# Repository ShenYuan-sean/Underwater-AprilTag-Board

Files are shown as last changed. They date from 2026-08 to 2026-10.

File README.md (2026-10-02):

# Underwater AprilTag Board

本仓库包含两套使用 AprilTag 36h11 的水下标定与定位板工程：

- 当前根目录：6 块 `150 mm × 150 mm` 六面全向标定板，Tag ID 为 `0–53`。
- [`Reservoir-AprilTag-Boards-20/`](Reservoir-AprilTag-Boards-20/)：两批共 40 块 `300 mm × 300 mm` 水库定位板，Tag ID 为 `100–459`，包含四个 `5.2 mm` 安装孔、加工用 DXF/SVG、参考 PDF 和第一批加工厂确认图。

## 6-Face AprilTag 36h11 Calibration Board

这个项目用于生成 6 块 150 mm x 150 mm 标定板，每块板使用 AprilTag `36h11` 家族，所有 Tag ID 唯一。默认布局是每面 1 个中央大 Tag + 8 个外围小 Tag，适合做六边形水平全向标定板。

## 默认方案

- 每块板尺寸：150 mm x 150 mm
- 每面 Tag 数：9
- 中央大 Tag：64 mm 黑色码区，单元格约 8 mm
- 外围小 Tag：22 mm 黑色码区，单元格约 2.75 mm
- 每面 ID：
  - Face 1: 0-8
  - Face 2: 9-17
  - Face 3: 18-26
  - Face 4: 27-35
  - Face 5: 36-44
  - Face 6: 45-53

中央大 Tag 用来保证中远距离、斜视角和运动模糊下仍能稳定识别；外围小 Tag 用来在近距离、局部遮挡、多面同时入镜时增加可见角点数量。默认不在板面上放安装孔，建议用背面、边缘压条或插槽夹持，避免破坏 Tag 的白色 quiet zone。

## 文件

- `generate_apriltag_boards.py`: 生成 SVG/DXF 的 Python 脚本
- `environment.yml`: 可复现环境配置
- `generated/face_01.svg` 到 `generated/face_06.svg`: 单面干净 SVG
- `generated/face_01_guide.svg` 到 `generated/face_06_guide.svg`: 带 ID 和 quiet zone 辅助线的 SVG
- `generated/face_01.dxf` 到 `generated/face_06.dxf`: 单面干净 DXF，默认只含加工常用图层和板面文字
- `generated/face_01_guide.dxf` 到 `generated/face_06_guide.dxf`: 带 Tag 边界、quiet zone 和辅助 ID 的 DXF
- `generated/all_faces_sheet.svg`: 六面拼版 SVG
- `generated/all_faces_sheet.dxf`: 六面拼版 DXF
- `generated/all_faces_sheet_guide.dxf`: 六面拼版辅助 DXF
- `generated/hex_fixture_top_view.dxf`: 六边形夹具顶视参考 DXF
- `generated/manifest.txt`: 尺寸、ID 和 DXF 图层说明

## 生成命令

本机 Miniconda 没有加入 PATH，所以可以直接用完整路径调用项目内环境：

```powershell
C:\Users\ASUS\Documents\WS\4.Underwater_Robot\水下标定板\.conda\apriltag-board\python.exe generate_apriltag_boards.py
```

如果要从 `environment.yml` 重建环境：

```powershell
C:\Users\ASUS\miniconda3\Scripts\conda.exe env create -f environment.yml
```

或者创建到项目内：

```powershell
C:\Users\ASUS\miniconda3\Scripts\conda.exe env create --prefix .\.conda\apriltag-board -f environment.yml
```

## 可调参数

```powershell
.\.conda\apriltag-board\python.exe generate_apriltag_boards.py --center-tag-mm 64 --small-tag-mm 22 --start-id 0
```

如果你希望远距离识别更强，可以把外围小 Tag 减少，或把中央 Tag 改到 72-90 mm；如果主要是近距离标定，可以保留 9 Tag 布局。当前默认方案是两者之间的折中。

## ID 校验

用 OpenCV 重新检测每块板的 SVG，确认 AprilTag 36h11 的 ID 没有生成错：

```powershell
.\.conda\apriltag-board\python.exe verify_apriltag_boards.py
```

脚本会检查 `generated/face_01.svg` 到 `generated/face_06.svg`，并在 `generated/verification_debug/` 里输出带检测框的 PNG。

## DXF 图层

- `CUT`: 150 mm 板外框
- `MOUNT_HOLE`: 4 个安装孔，默认孔径 3.4 mm，孔心为 `(48,22)`, `(102,22)`, `(48,128)`, `(102,128)`
- `BLACK_POCKET`: 每个黑色单元格的轮廓线，适合 CNC/激光做填黑或雕刻区域
- `BOARD_TEXT`: 实际可印/可刻的板号、ID 范围和左右相邻面提示；普通 DXF 中这些文字已经转成线段字，不依赖 CAD 的 `TEXT` 实体
- `ORIENTATION`: 顶边方向箭头
- `BLACK_FILL_PREVIEW`: 可选黑块预览填充层，默认不输出
- `TAG_BOUNDARY`: Tag 黑色码区边界，只在 `*_guide.dxf`
- `QUIET_ZONE`: 推荐留白区域，只在 `*_guide.dxf`
- `LABEL`: 面编号和 ID 辅助标注，只在 `*_guide.dxf`

实际加工时，建议使用 `CUT`、`BLACK_POCKET`、`BOARD_TEXT` 和 `ORIENTATION`。默认 DXF 已改成 AutoCAD R12 ASCII，普通加工版只用 `LINE` 实体来画板框、黑块、箭头和板面提示文字，兼容性比上一版更好。

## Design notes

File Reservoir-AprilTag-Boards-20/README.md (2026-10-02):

# 水库 AprilTag 定位板（两批共 40 块）

本工程管理两批共 40 块独立的 `300 mm × 300 mm` 水库定位板。参考原六面标定板，每块板使用“一个中央大 Tag + 八个外围小 Tag”的 AprilTag 36h11 九宫格布局。共使用唯一 ID `100–459`，避免与 `Underwater-AprilTag-Board` 中已有的 `0–53` 冲突。

| 批次 | 板号 | Tag ID | 文件位置 |
|---|---|---|---|
| 第一批（已加工） | R01–R20 | 100–279 | `generated/`、`加工厂复核/` |
| 第二批（本次新增） | R21–R40 | 280–459 | `batch_02/generated/`、`batch_02/output/pdf/` |

## 推荐方案

| 项目 | 参数 |
|---|---:|
| 板材外形 | 300 mm × 300 mm |
| 每板 Tag 数量 | 9 |
| Tag 家族 | AprilTag 36h11 |
| ID | 100–459（两批合计） |
| 中央黑色码区 | 128 mm × 128 mm |
| 外围黑色码区 | 44 mm × 44 mm |
| 中央/小 Tag 单元格 | 16 mm / 5.5 mm |
| 中央/小 Tag quiet zone | 10 mm / 8 mm |
| 安装孔 | 4 × 直径 5.2 mm（M5 间隙孔） |
| 孔位 | 两列 `x=96/204 mm`，两行 `y=44/256 mm` |

以板左下角为工程坐标原点，四个孔心为：

- `(96, 44) mm`
- `(204, 44) mm`
- `(96, 256) mm`
- `(204, 256) mm`

中央 Tag 黑色码区位于 `x=86–214 mm, y=86–214 mm`，其 quiet zone 为 `x=76–224 mm, y=76–224 mm`。外围 Tag 位于中心坐标为 `44、150、256 mm` 的九宫格位置，跳过中央位置；每个小 Tag 的 quiet zone 外形为 `60 mm × 60 mm`。孔位落在外围 Tag 之间的空隙中，不侵入任何 quiet zone。

每块板的 ID 按下面方式连续分配：

```text
左上=base+1    上=base+2      右上=base+3
左=base+4      中央=base      右=base+5
左下=base+6    下=base+7      右下=base+8
```

例如 R01 使用 `100–108`，R20 使用 `271–279`，R21 使用 `280–288`，R40 使用 `451–459`。

## 为什么采用一大八小

中央 `128 mm` Tag 是主地标，承担相对较远距离的发现和位姿估计。八个 `44 mm` 小 Tag 用于：

- 相机经常靠得非常近，主 Tag 不能完整进入画面；
- 标定板经常被局部遮挡；
- 只看到板的一角或一条边时仍能识别板号；
- 近距离时提供更多独立角点和检测冗余。

该布局是原 150 mm 六面板方案的两倍尺度版本：中央 `64→128 mm`、外围 `22→44 mm`、外围中心距板边 `22→44 mm`。因此可以沿用原工程的 ID 顺序和检测逻辑。

## 输出文件

第一批的 `generated/` 包含：

- `board_01_ids_100-108.svg` 到 `board_20_ids_271-279.svg`：用于印刷的干净 SVG；
- `board_XX_ids_XXX-XXX_guide.svg`：包含 quiet zone、Tag 边界、ID 和钻孔位置的检查图；
- 对应的 `.dxf`：包含切割、钻孔和黑色单元格加工图层；
- `all_boards_sheet.svg/.dxf`：20 块板的 4 × 5 拼版；
- `board_drill_template.svg/.dxf`：所有板共用的钻孔模板；
- `id_map.csv`：板号与 Tag ID 对照表；
- `deployment_survey_template.csv`：部署位置和姿态测量记录模板；
- `manifest.txt`：生产尺寸摘要。
- `output/pdf/reservoir_apriltag_20_board_reference.pdf`：20 页 DXF 图案和孔位对照册。

第二批的 `batch_02/generated/` 使用相同结构，文件名从 `board_21_ids_280-288` 到 `board_40_ids_451-459`。加工厂交付目录位于 `batch_02/manufacturing/`，可直接发送的压缩包为 `batch_02/reservoir_apriltag_boards_21-40_manufacturing.zip`，参考对照册为 `batch_02/output/pdf/reservoir_apriltag_boards_21-40_reference.pdf`。

干净 SVG 不画钻孔辅助圆，避免钻孔标记混入印刷图案；钻孔位置在 guide SVG 和所有 DXF 文件中给出。
每块板正面左下边缘只印中央大 Tag 的可读编号，例如第一块为 `ID = 100`；不再印 `R01–R20` 板号。该文字位于外围 Tag 的 quiet zone 之外。
生产 DXF 中的 `ID = 100` 已转换成普通 `LINE` 轮廓，不依赖 DXF `TEXT` 实体，因此 Fusion 360 插入草图时也能显示。

## 环境

本机已有 `rss_depth` Conda 环境满足要求：

- Python 3.10.19
- OpenCV 4.13.0
- `cv2.aruco.ArucoDetector`

直接运行：

```powershell
conda run -n rss_depth python generate_reservoir_boards.py
conda run -n rss_depth python verify_reservoir_boards.py --no-debug
conda run -n rss_depth python generate_reference_pdf.py
```

生成并验证第二批 R21–R40：

```powershell
conda run -n rss_depth python generate_reservoir_boards.py `
  --out batch_02/generated `
  --board-count 20 `
  --board-number-start 21 `
  --start-id 280

conda run -n rss_depth python verify_reservoir_boards.py `
  --input-dir batch_02/generated `
  --no-debug

conda run -n rss_depth python generate_reference_pdf.py `
  --out batch_02/output/pdf/reservoir_apriltag_boards_21-40_reference.pdf `
  --board-count 20 `
  --board-number-start 21 `
  --start-id 280
```

如果以后需要独立重建环境：

```powershell
conda env create -f environment.yml
conda run -n reservoir-apriltag-boards python generate_reservoir_boards.py
```

常用参数示例：

```powershell
conda run -n rss_depth python generate_reservoir_boards.py `
  --board-count 20 `
  --board-mm 300 `
  --center-tag-mm 128 `
  --small-tag-mm 44 `
  --center-quiet-mm 10 `
  --small-quiet-mm 8 `
  --small-center-mm 44 `
  --start-id 100 `
  --hole-dia-mm 5.2 `
  --hole-x-mm 96 `
  --hole-y-mm 44
```

## 制作要求

1. 必须按 `100%` 实际尺寸输出，关闭“适合页面”或自动缩放。
2. 成品上实测中央/小黑色码区应为 `128 mm` 和 `44 mm`；建议中央尺寸误差控制在 `±0.5 mm` 内。
3. quiet zone 内不能出现孔、螺栓、接缝、文字、污渍或颜色突变。
4. 黑白表面优先使用哑光工艺，避免水下照明形成强反光。
5. 推荐 3–5 mm 5052 铝板、铝塑板或足够刚性的耐水板材；薄板背面应加支撑，避免弯曲造成位姿误差。
6. 图案可采用耐浸水 UV 印刷、丝印或黑白双组分环氧涂层。正式批量制作前先做一块浸泡和擦洗测试。
7. M5 螺栓建议配大垫片和防松结构；异种金属接触处应做电化学腐蚀隔离。
8. 板角建议倒圆，但最终外形变更不能侵入孔边或 quiet zone。

## 部署要求

Tag ID 只能告诉程序“看到了哪块板”。要让它成为水库世界坐标系中的定位地标，还必须测量并记录：

- Tag 中心的水库坐标 `X/Y/Z`；
- 板面朝向，至少记录 yaw/pitch/roll 或板面法向量；
- 箭头所指方向；
- 安装位置照片和附近固定参照物；
- 安装日期、紧固状态和后续污损情况。

建议所有竖直安装的板保持箭头朝上。位姿估计时必须根据 ID 使用正确尺寸：每板第一个 ID 对应中央 `128 mm` Tag，其余八个 ID 对应 `44 mm` Tag，不能把 300 mm 板外形当成 Tag 尺寸。

粗略识别距离可以用下面的投影关系估算：

```text
中央 Tag 像素宽度 ≈ 相机焦距(px) × 0.128(m) / 距离(m)
小 Tag 像素宽度   ≈ 相机焦距(px) × 0.044(m) / 距离(m)
```

水下正式部署前，应使用实际相机、舱体玻璃、灯光和目标水体，在计划的最远距离验证检测成功率。建议让 Tag 在图像中至少保持约 60–80 像素宽，复杂浑水环境应留更大余量。

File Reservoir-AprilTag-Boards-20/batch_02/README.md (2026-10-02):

# 第二批水库 AprilTag 定位板

本批次包含 R21–R40，共 20 块 `300 mm × 300 mm` 定位板，沿用第一批的一大八小 AprilTag 36h11 布局、四个 `5.2 mm` 安装孔和左下角中央 ID 标识。

- 板号：R21–R40
- Tag ID：280–459
- 中央 Tag：128 mm
- 外围 Tag：8 × 44 mm
- 孔位：`(96,44)`、`(204,44)`、`(96,256)`、`(204,256)` mm
- 加工厂压缩包：`reservoir_apriltag_boards_21-40_manufacturing.zip`
- 生产 DXF：`manufacturing/`
- SVG/DXF/清单源文件：`generated/`
- 20 页对照 PDF：`output/pdf/reservoir_apriltag_boards_21-40_reference.pdf`

所有 20 块板的 180 个 Tag 已通过 OpenCV AprilTag 36h11 解码复核；20 个生产 DXF 已检查 300 mm 外框和四个直径 5.2 mm 通孔。

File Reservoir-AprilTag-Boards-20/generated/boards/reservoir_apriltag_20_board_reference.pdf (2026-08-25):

RESERVOIR APRILTAG BOARD - DXF REFERENCE | Page 1 / 20 | Center ID 100

# BOARD 01

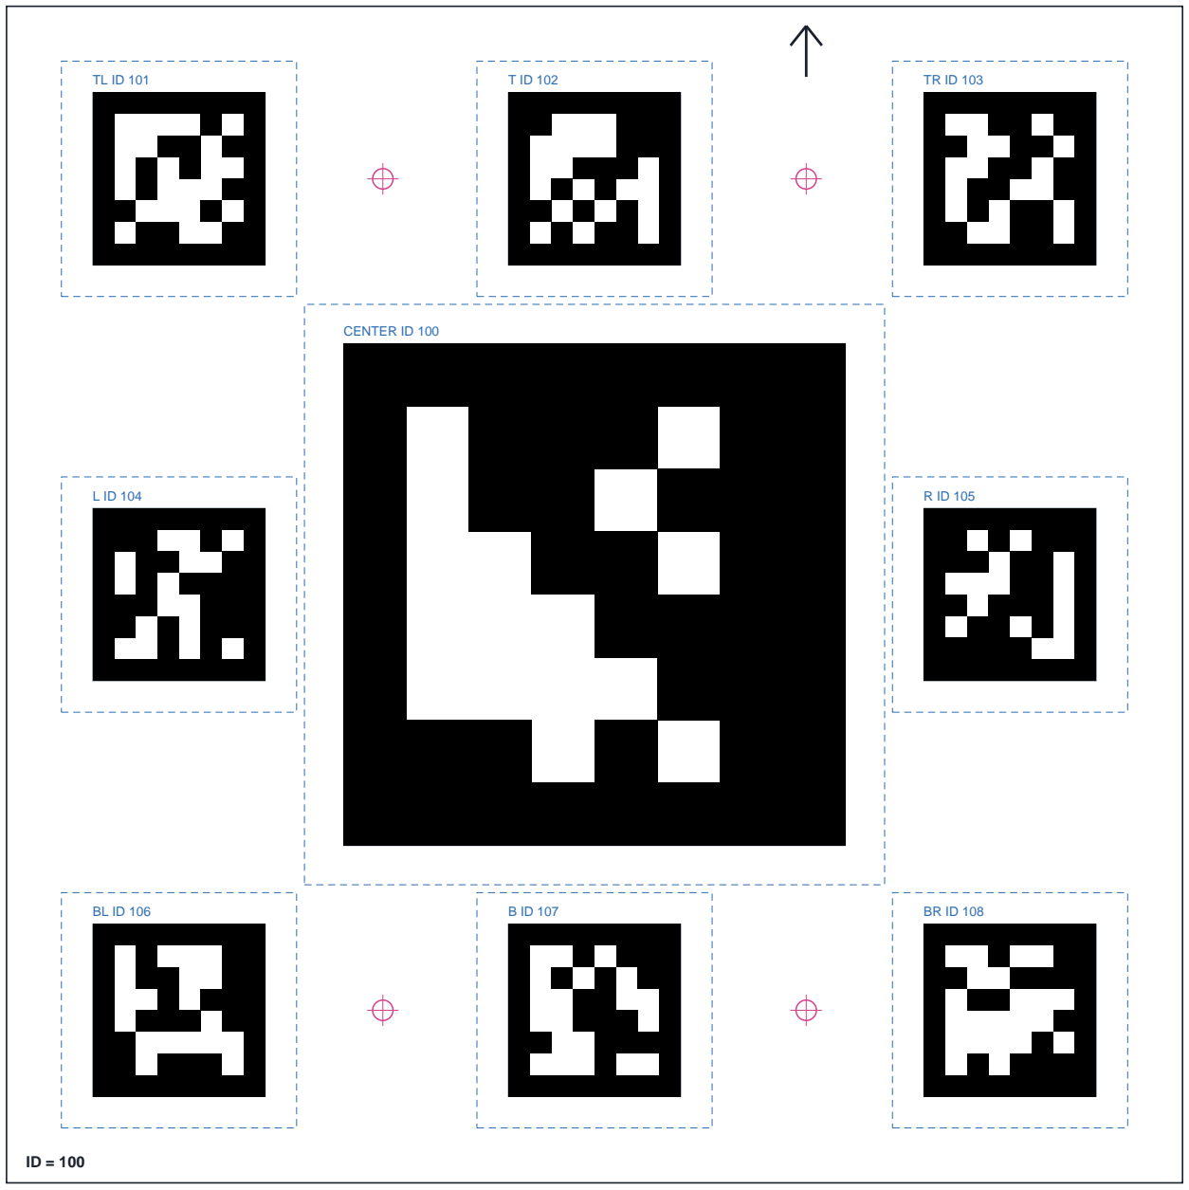
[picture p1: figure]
CENTER ID 100

## Center ID 100 | IDs 100-108

Board | 300 x 300 mm
Center marker | 128 mm
Outer markers | 8 x 44 mm
Mount holes | 4 x DIA 5.2 mm
Hole X | 96, 204 mm
Hole Y | 44, 256 mm

## ID LAYOUT

TL 101 | T 102 | TR 103
L 104 | CENTER 100 | R 105
BL 106 | B 107 | BR 108

Blue dashed: required white quiet zone Magenta: mounting holes and centers Reference diagram is scaled, not 1:1 Manufacture from DXF/SVG; DXF units are mm

board_01_ids_100-108.dxf

RESERVOIR APRILTAG BOARD - DXF REFERENCE | Page 2 / 20 | Center ID 109

# BOARD 02

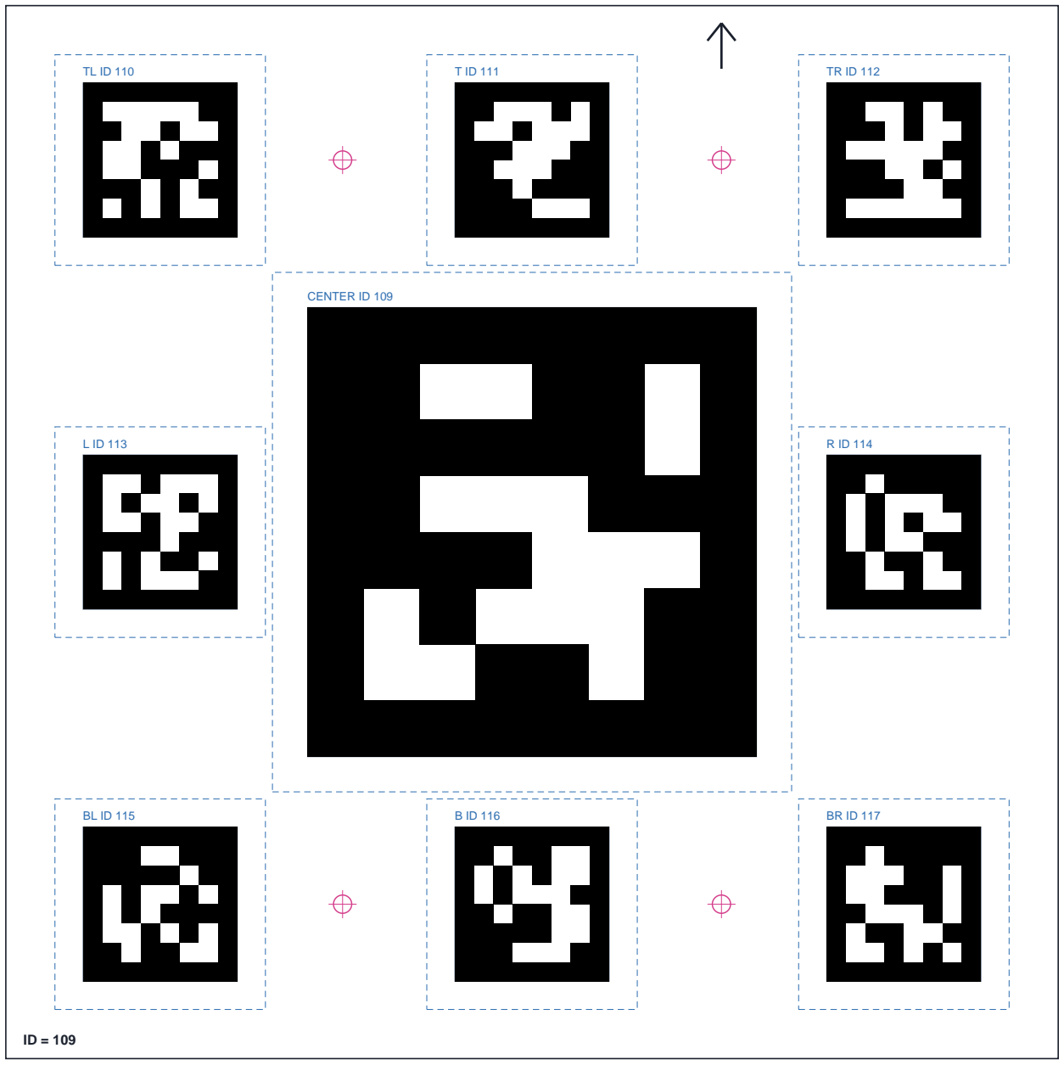
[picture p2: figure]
CENTER ID 109

## Center ID 109 | IDs 109-117

Board | 300 x 300 mm
Center marker | 128 mm
Outer markers | 8 x 44 mm
Mount holes | 4 x DIA 5.2 mm
Hole X | 96, 204 mm
Hole Y | 44, 256 mm

## ID LAYOUT

TL 110 | T 111 | TR 112
L 113 | CENTER 109 | R 114
BL 115 | B 116 | BR 117

Blue dashed: required white quiet zone Magenta: mounting holes and centers Reference diagram is scaled, not 1:1 Manufacture from DXF/SVG; DXF units are mm

board_02_ids_109-117.dxf

RESERVOIR APRILTAG BOARD - DXF REFERENCE | Page 3 / 20 | Center ID 118

# BOARD 03

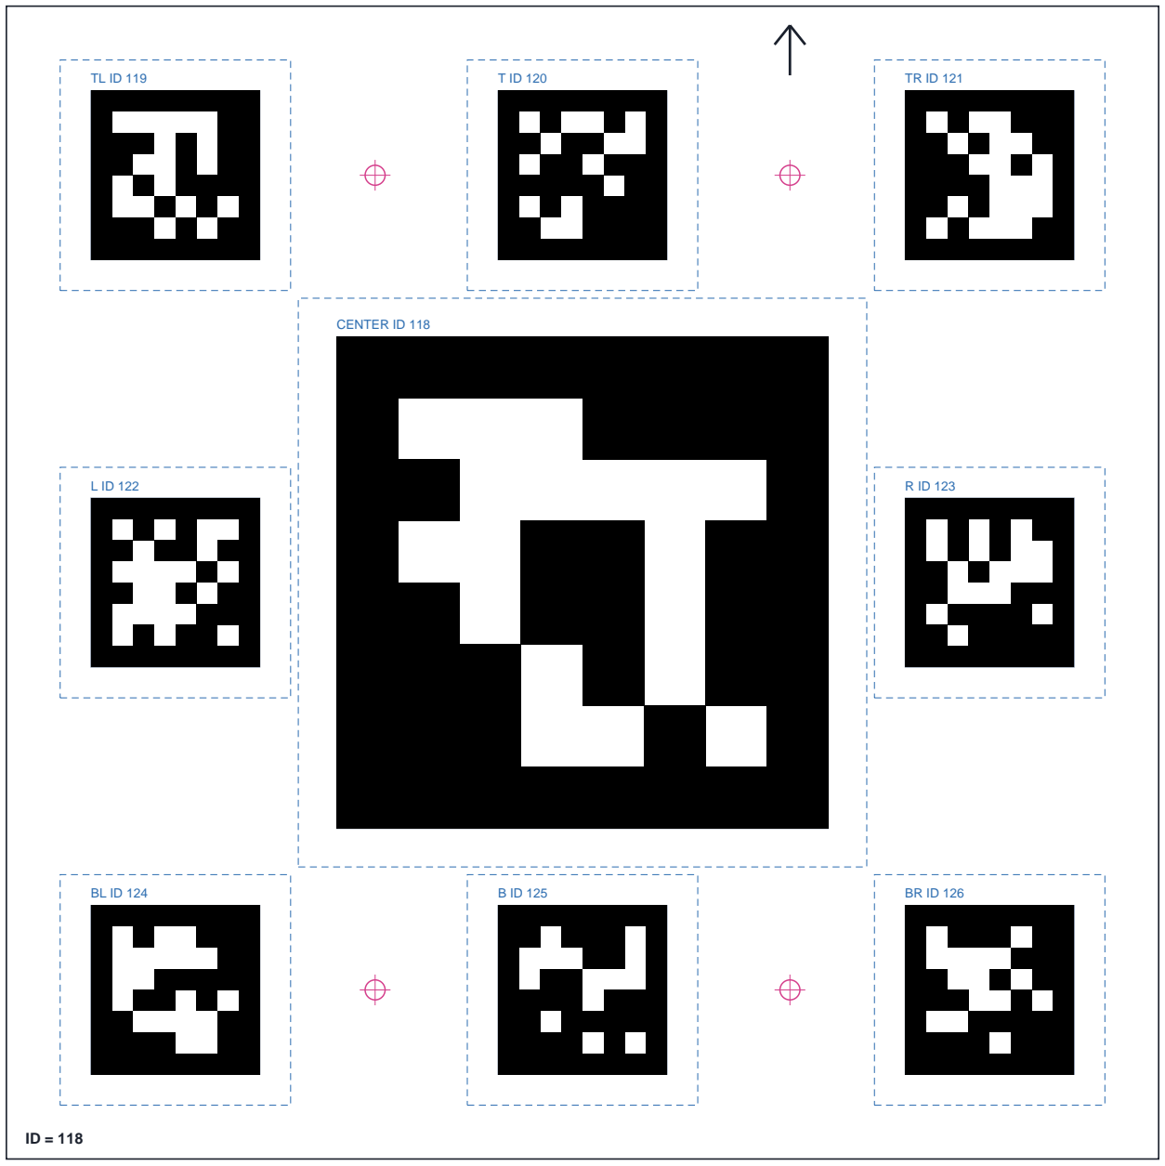
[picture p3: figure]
CENTER ID 118

## Center ID 118 | IDs 118-126

Board | 300 x 300 mm
Center marker | 128 mm
Outer markers | 8 x 44 mm
Mount holes | 4 x DIA 5.2 mm
Hole X | 96, 204 mm
Hole Y | 44, 256 mm

## ID LAYOUT

TL 119 | T 120 | TR 121
L 122 | CENTER 118 | R 123
BL 124 | B 125 | BR 126

Blue dashed: required white quiet zone Magenta: mounting holes and centers Reference diagram is scaled, not 1:1 Manufacture from DXF/SVG; DXF units are mm

board_03_ids_118-126.dxf

RESERVOIR APRILTAG BOARD - DXF REFERENCE | Page 4 / 20 | Center ID 127

# BOARD 04

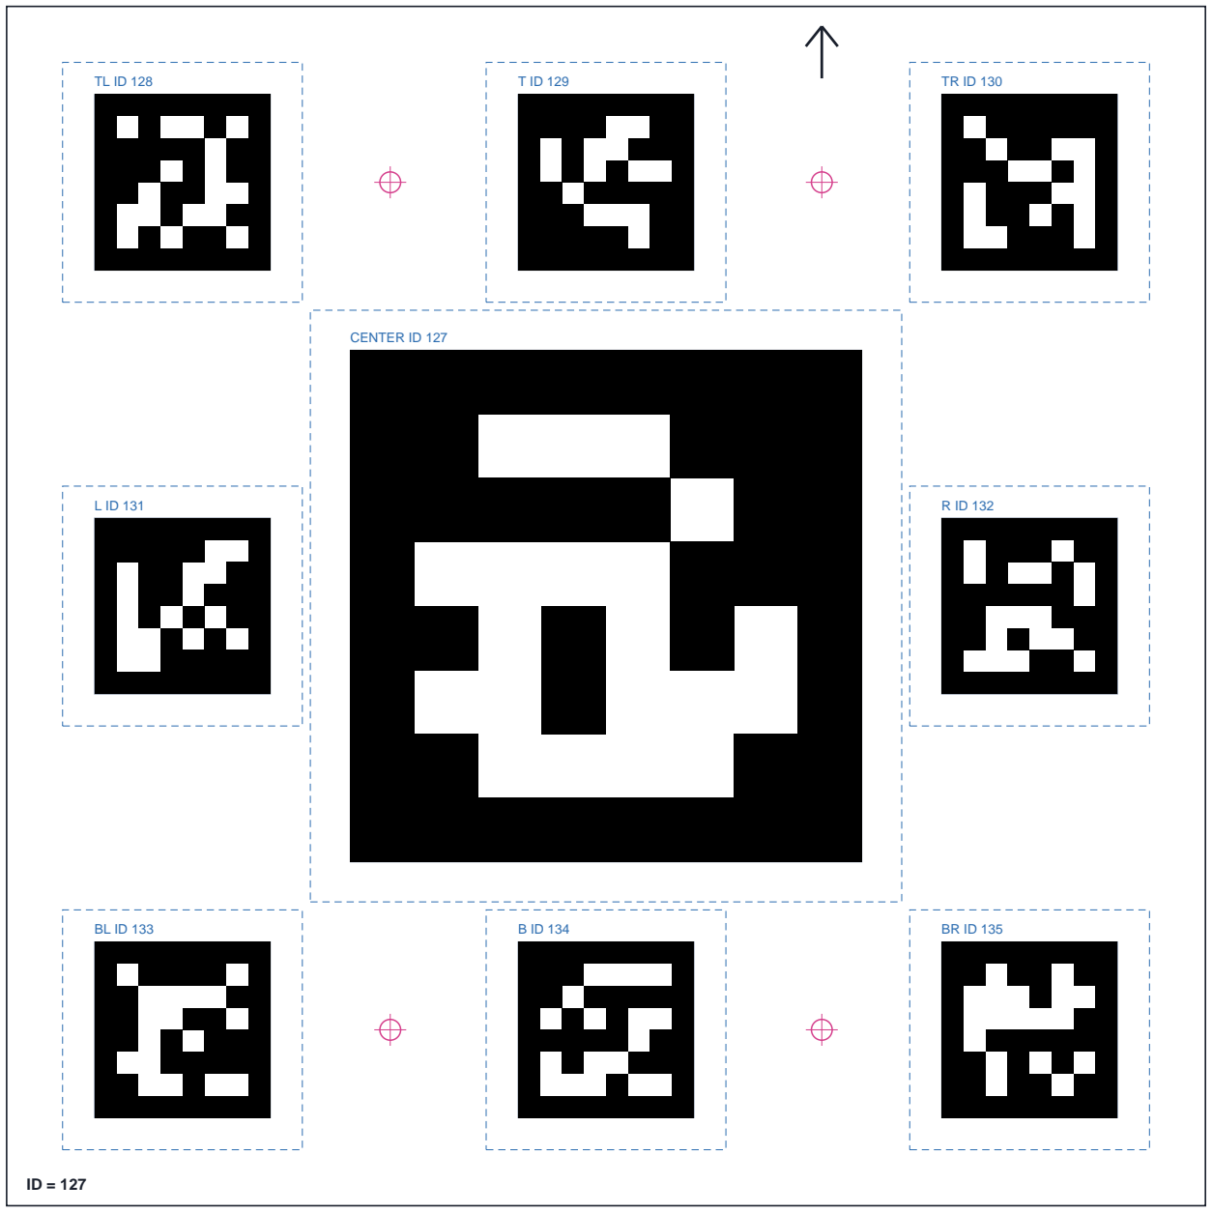
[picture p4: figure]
CENTER ID 127

## Center ID 127 | IDs 127-135

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

## ID LAYOUT

TL 128 | T 129 | TR 130
L 131 | CENTER 127 | R 132
BL 133 | B 134 | BR 135

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

board_04_ids_127-135.dxf

RESERVOIR APRILTAG BOARD - DXF REFERENCE | Page 5 / 20 | Center ID 136

# BOARD 05

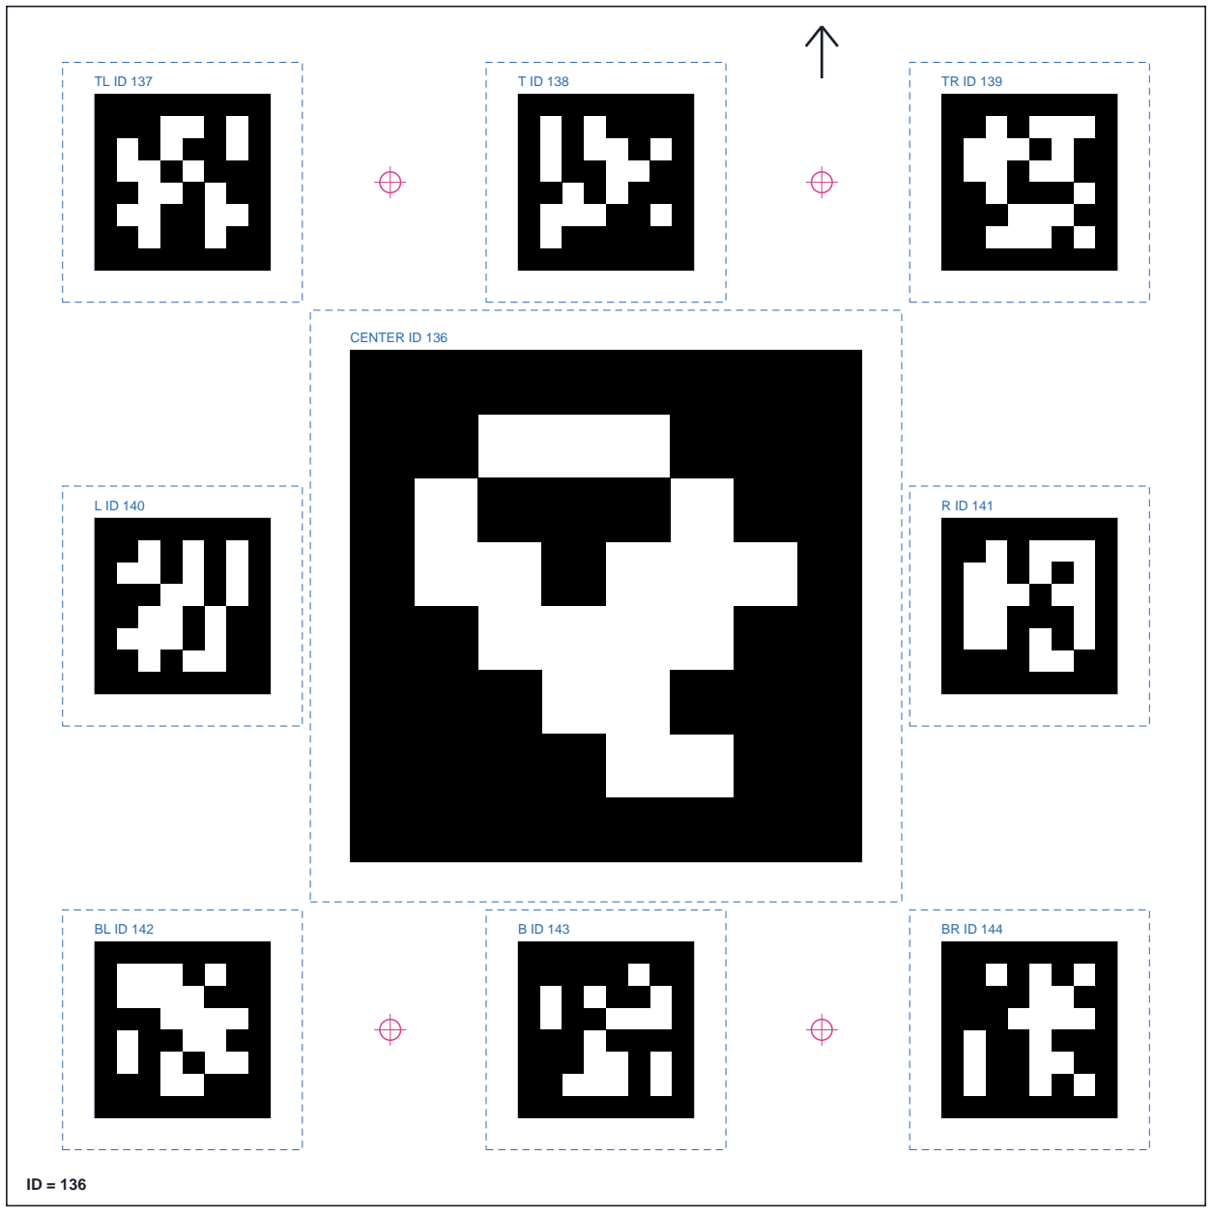
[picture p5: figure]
CENTER ID 136

## Center ID 136 | IDs 136-144

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

## ID LAYOUT

TL 137 | T 138 | TR 139
L 140 | CENTER 136 | R 141
BL 142 | B 143 | BR 144

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

board_05_ids_136-144.dxf

RESERVOIR APRILTAG BOARD - DXF REFERENCE | Page 6 / 20 | Center ID 145

# BOARD 06

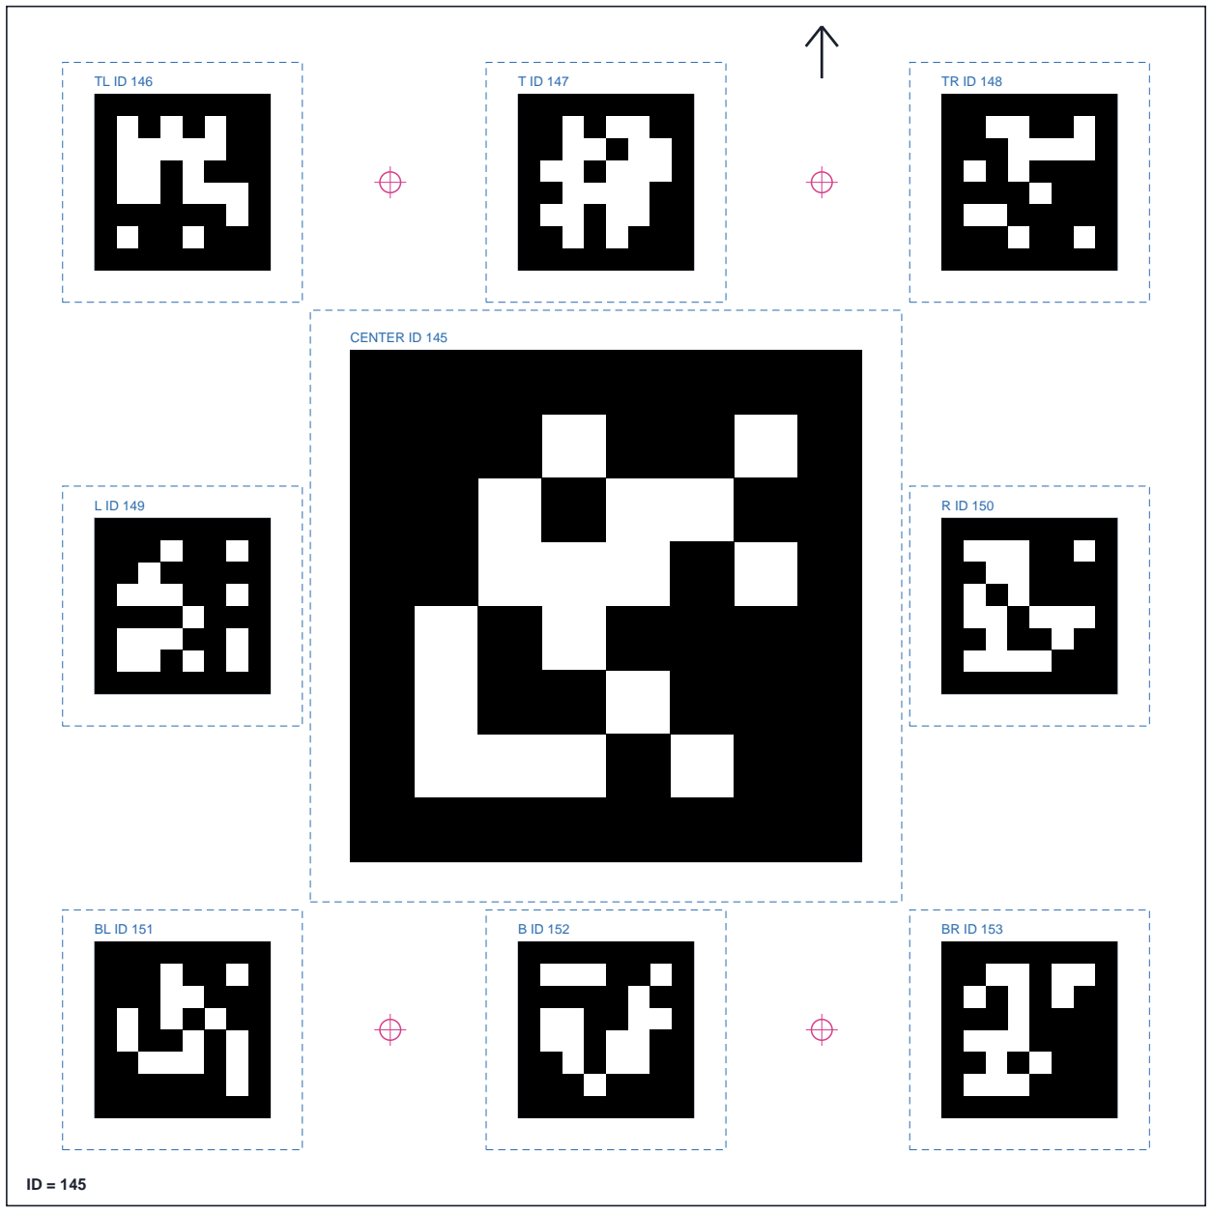
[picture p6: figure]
CENTER ID 145

## Center ID 145 | IDs 145-153

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

## ID LAYOUT

TL 146 | T 147 | TR 148
L 149 | CENTER 145 | R 150
BL 151 | B 152 | BR 153

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

board_06_ids_145-153.dxf

RESERVOIR APRILTAG BOARD - DXF REFERENCE | Page 7 / 20 | Center ID 154

# BOARD 07

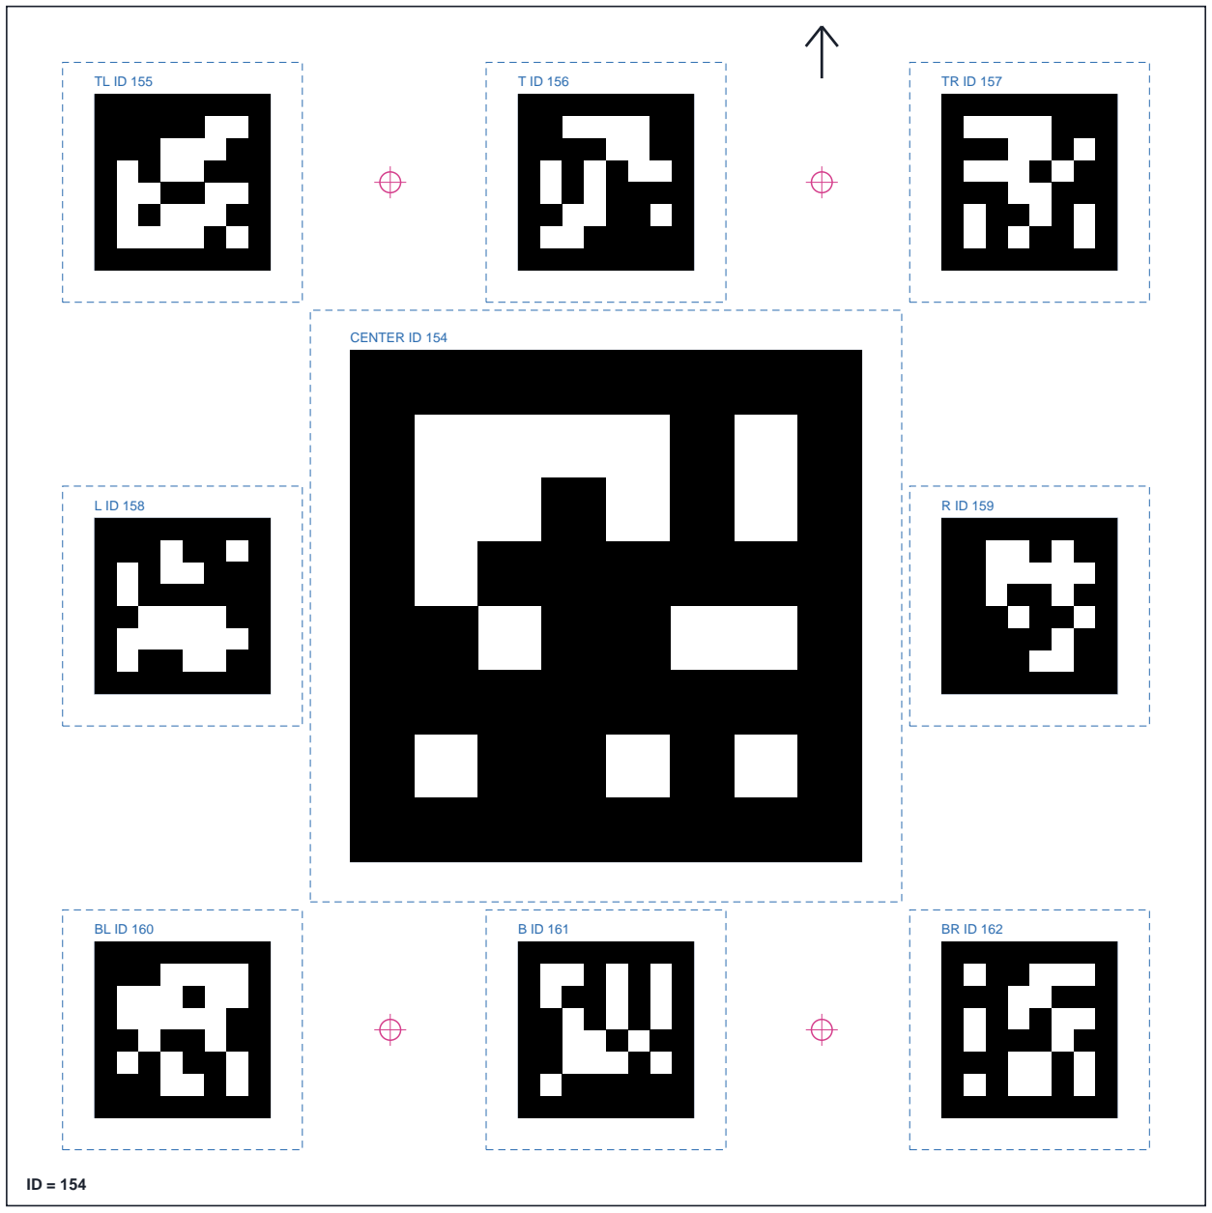
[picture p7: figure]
CENTER ID 154

## Center ID 154 | IDs 154-162

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

## ID LAYOUT

TL 155 | T 156 | TR 157
L 158 | CENTER 154 | R 159
BL 160 | B 161 | BR 162

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

board_07_ids_154-162.dxf

RESERVOIR APRILTAG BOARD - DXF REFERENCE | Page 8 / 20 | Center ID 163

# BOARD 08

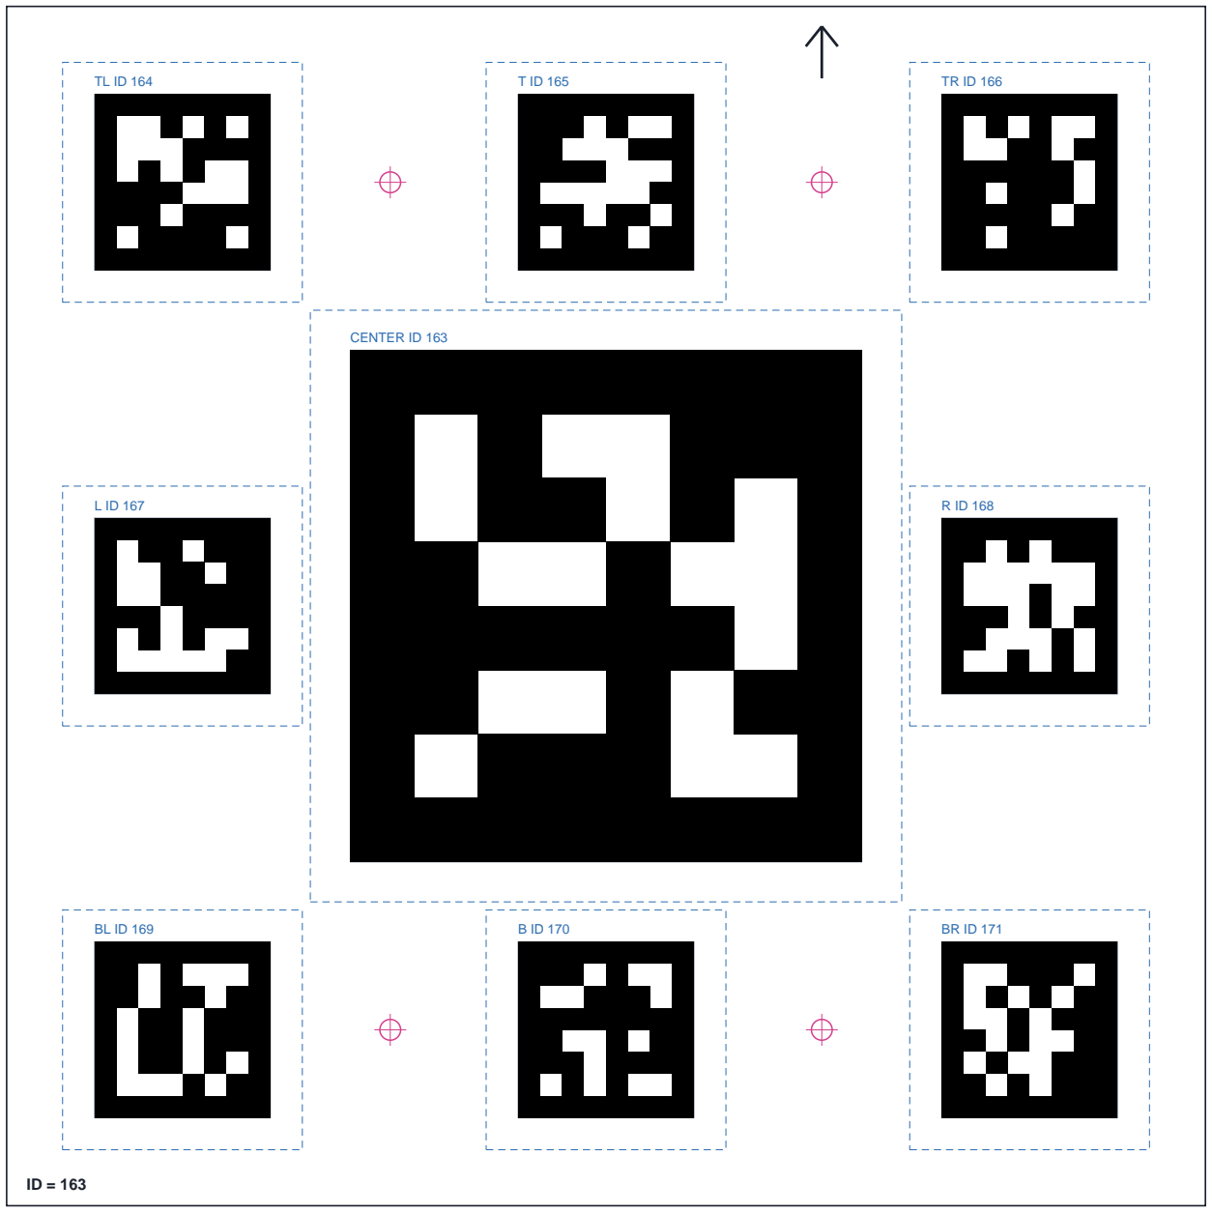
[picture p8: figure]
CENTER ID 163

## Center ID 163 | IDs 163-171

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

## ID LAYOUT

TL 164 | T 165 | TR 166
L 167 | CENTER 163 | R 168
BL 169 | B 170 | BR 171

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

board_08_ids_163-171.dxf

RESERVOIR APRILTAG BOARD - DXF REFERENCE | Page 9 / 20 | Center ID 172

# BOARD 09

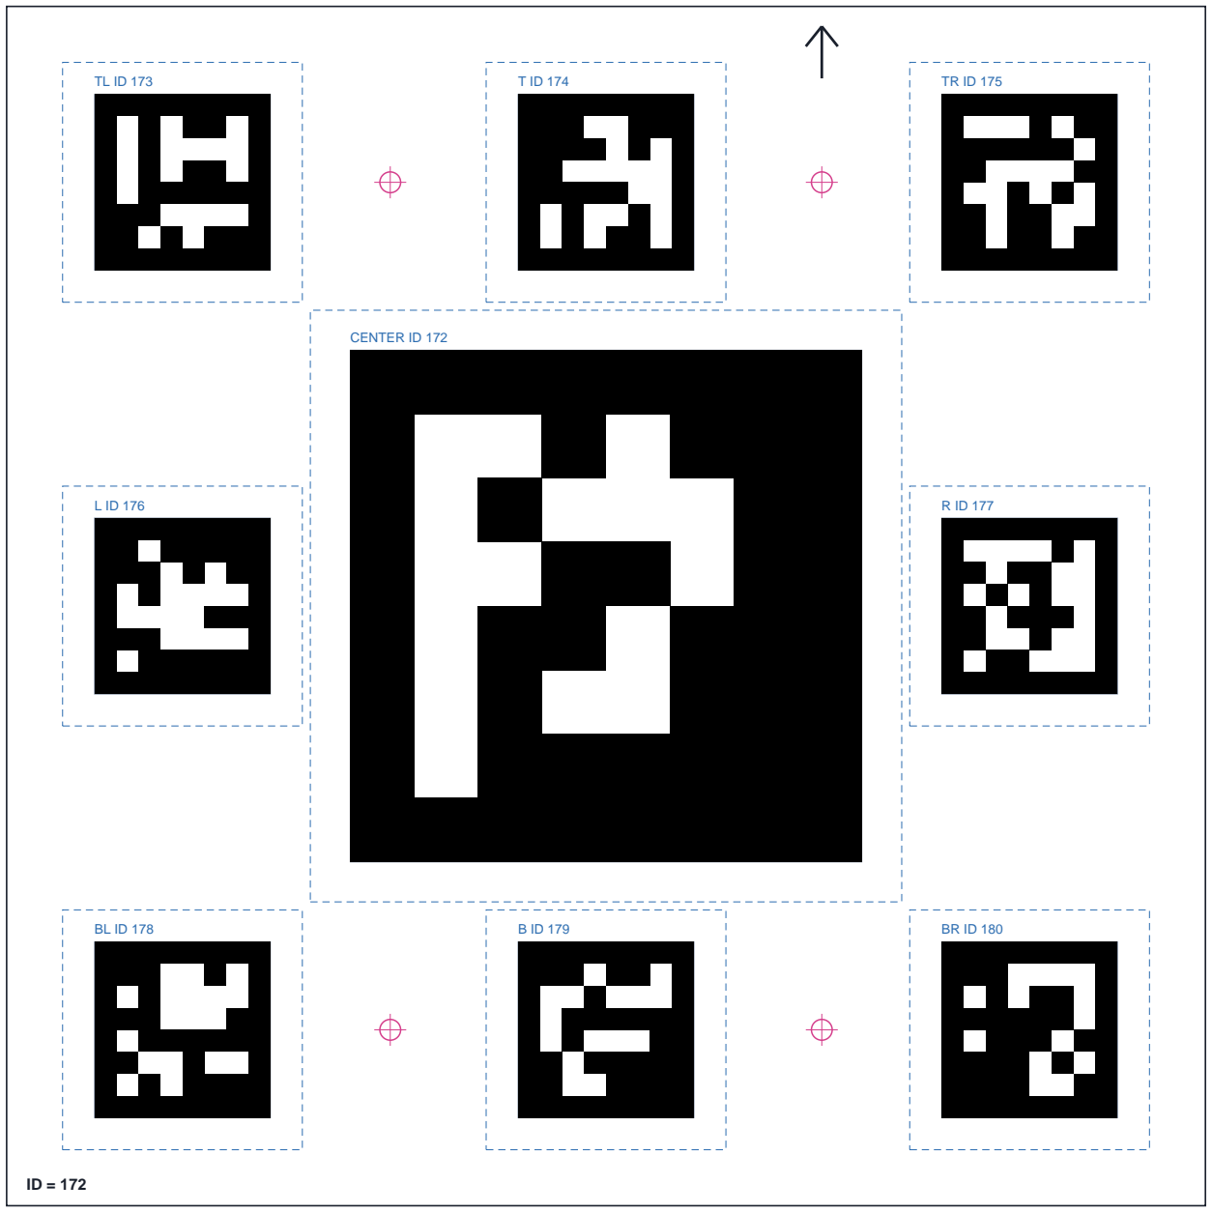
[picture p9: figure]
CENTER ID 172

## Center ID 172 | IDs 172-180

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

## ID LAYOUT

TL 173 | T 174 | TR 175
L 176 | CENTER 172 | R 177
BL 178 | B 179 | BR 180

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

board_09_ids_172-180.dxf

RESERVOIR APRILTAG BOARD - DXF REFERENCE | Page 10 / 20 | Center ID 181

# BOARD 10

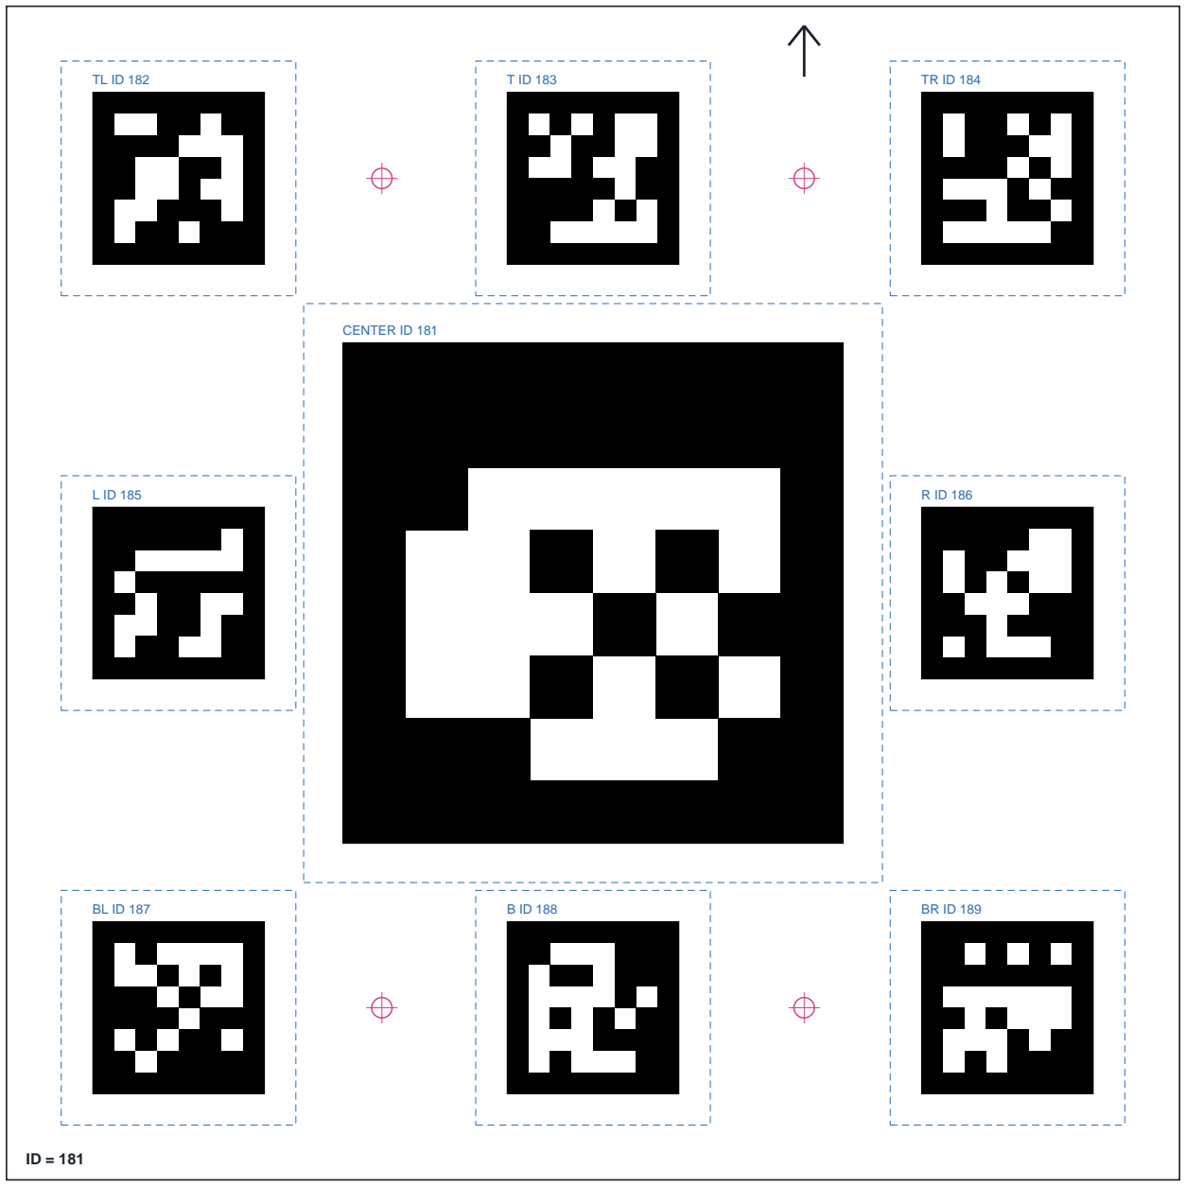
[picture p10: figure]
CENTER ID 181

## Center ID 181 | IDs 181-189

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

## ID LAYOUT

TL 182 | T 183 | TR 184
L 185 | CENTER 181 | R 186
BL 187 | B 188 | BR 189

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

board_10_ids_181-189.dxf

RESERVOIR APRILTAG BOARD - DXF REFERENCE | Page 11 / 20 | Center ID 190

# BOARD 11

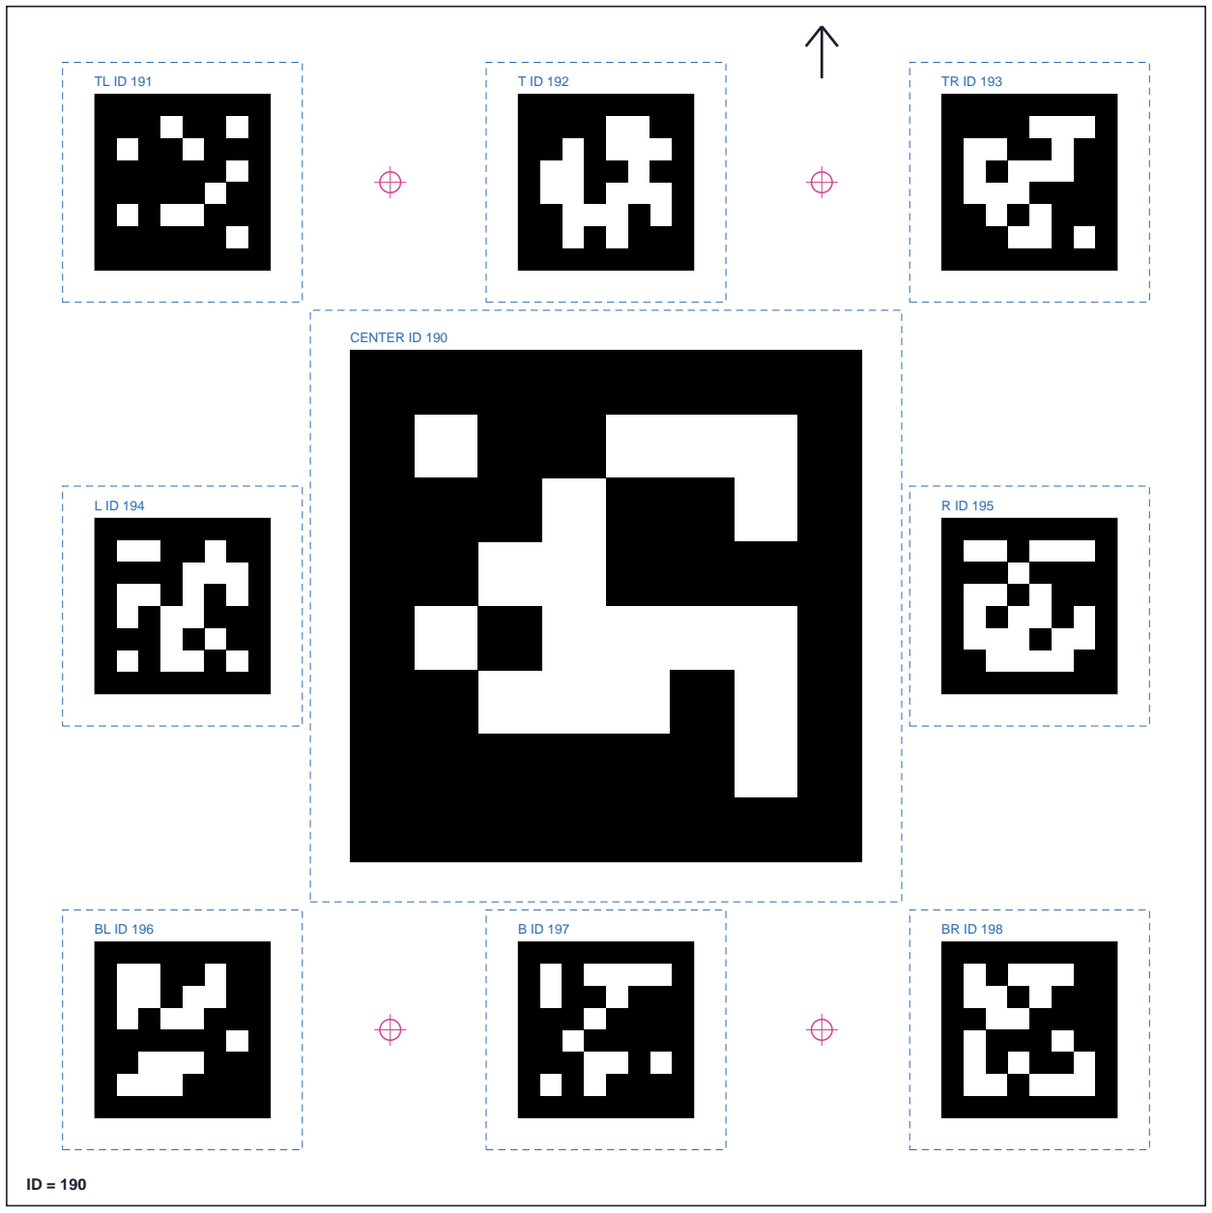
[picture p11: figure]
CENTER ID 190

## Center ID 190 | IDs 190-198

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

## ID LAYOUT

TL 191 | T 192 | TR 193
L 194 | CENTER 190 | R 195
BL 196 | B 197 | BR 198

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

board_11_ids_190-198.dxf

RESERVOIR APRILTAG BOARD - DXF REFERENCE | Page 12 / 20 | Center ID 199

# BOARD 12

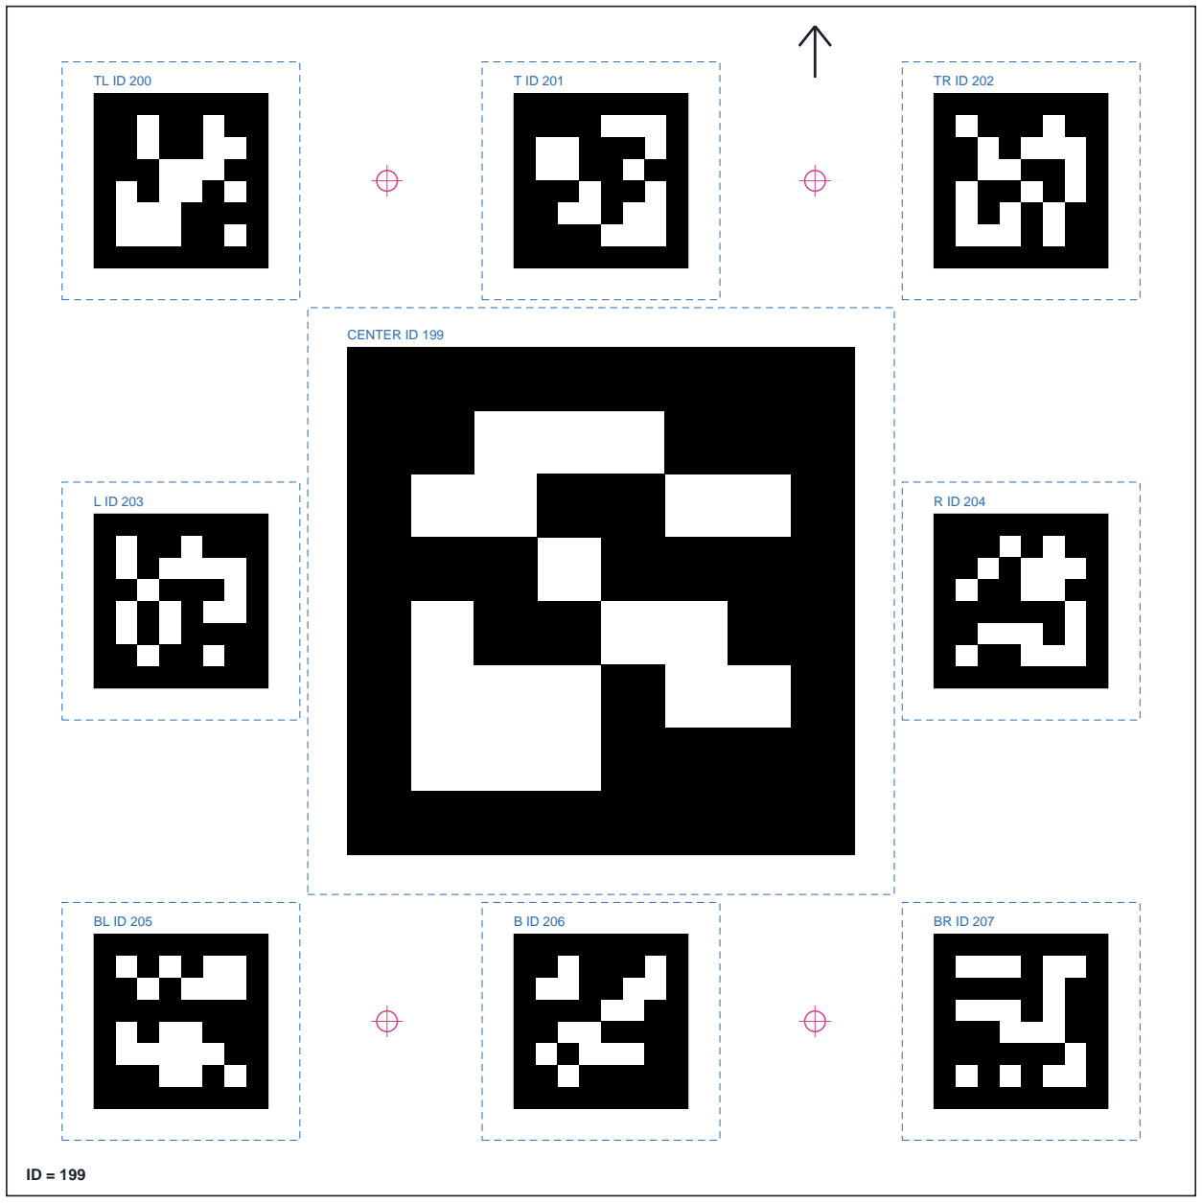
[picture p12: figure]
CENTER ID 199

## Center ID 199 | IDs 199-207

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

## ID LAYOUT

TL 200 | T 201 | TR 202
L 203 | CENTER 199 | R 204
BL 205 | B 206 | BR 207

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

board_12_ids_199-207.dxf

RESERVOIR APRILTAG BOARD - DXF REFERENCE | Page 13 / 20 | Center ID 208

# BOARD 13

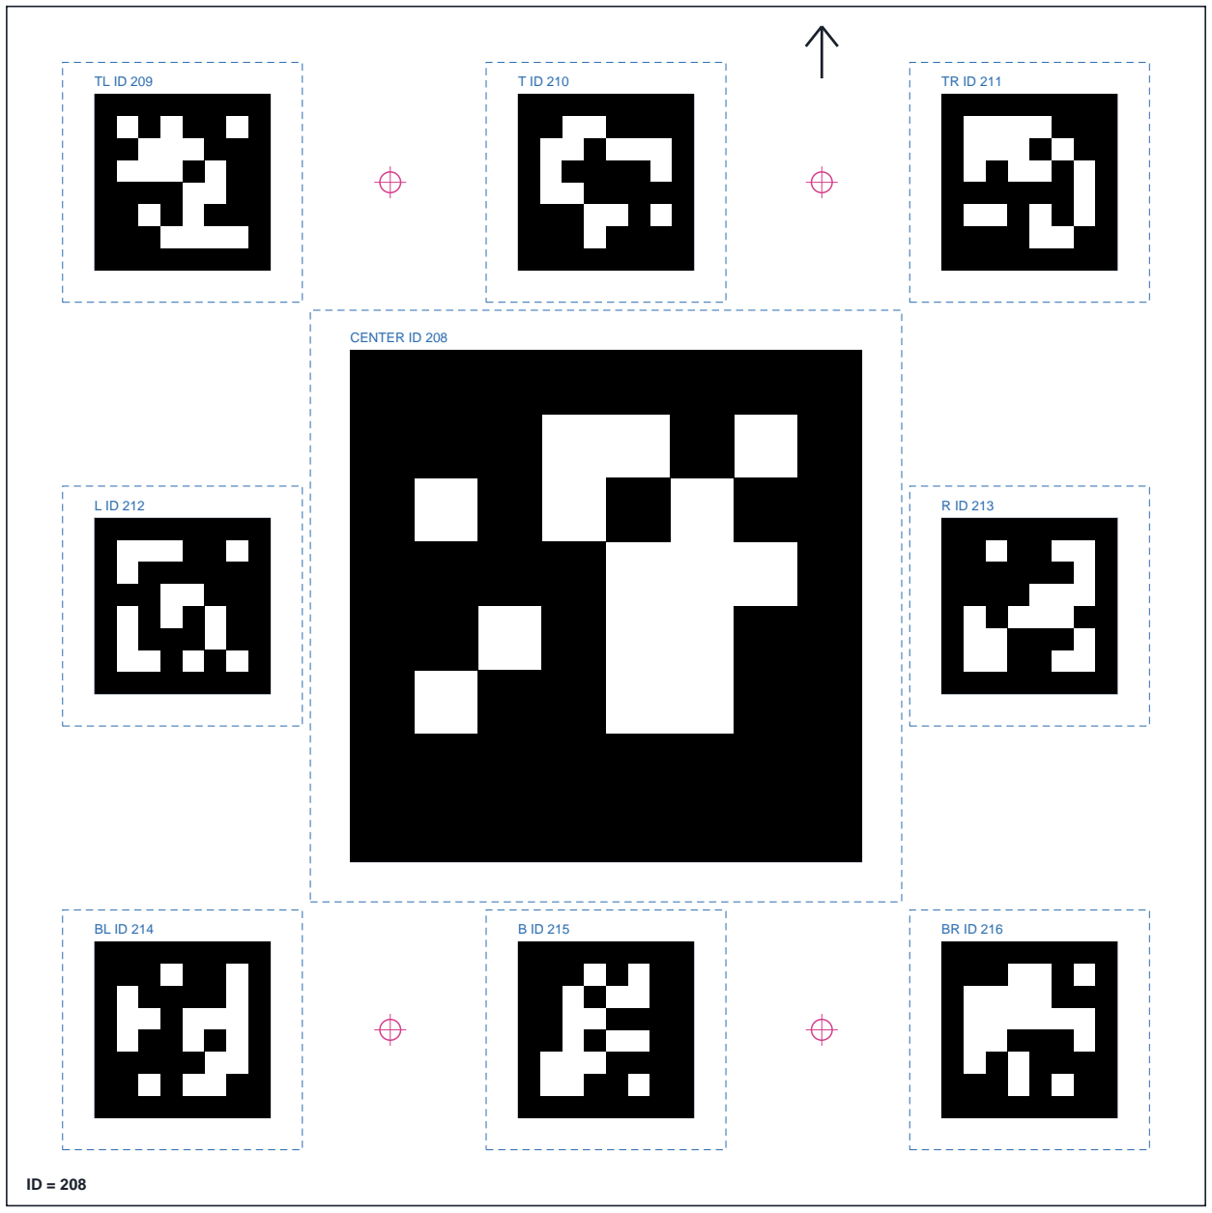
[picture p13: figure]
CENTER ID 208

## Center ID 208 | IDs 208-216

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

## ID LAYOUT

TL 209 | T 210 | TR 211
L 212 | CENTER 208 | R 213
BL 214 | B 215 | BR 216

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

board_13_ids_208-216.dxf

RESERVOIR APRILTAG BOARD - DXF REFERENCE | Page 14 / 20 | Center ID 217

# BOARD 14

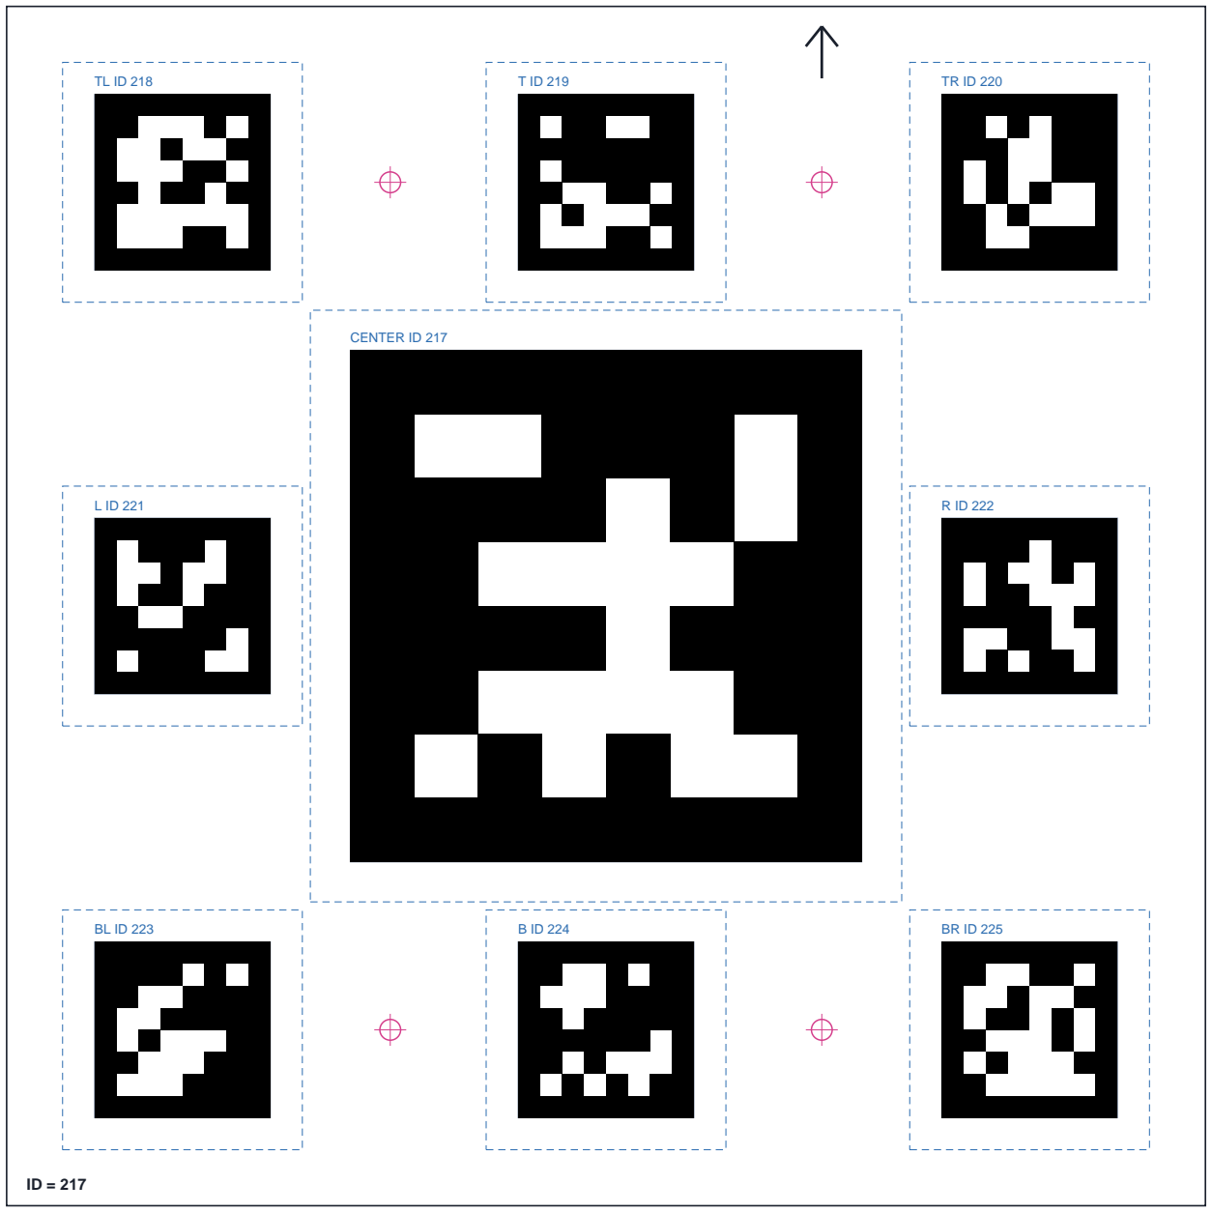
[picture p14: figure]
CENTER ID 217

## Center ID 217 | IDs 217-225

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

## ID LAYOUT

TL 218 | T 219 | TR 220
L 221 | CENTER 217 | R 222
BL 223 | B 224 | BR 225

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

board_14_ids_217-225.dxf

RESERVOIR APRILTAG BOARD - DXF REFERENCE | Page 15 / 20 | Center ID 226

# BOARD 15

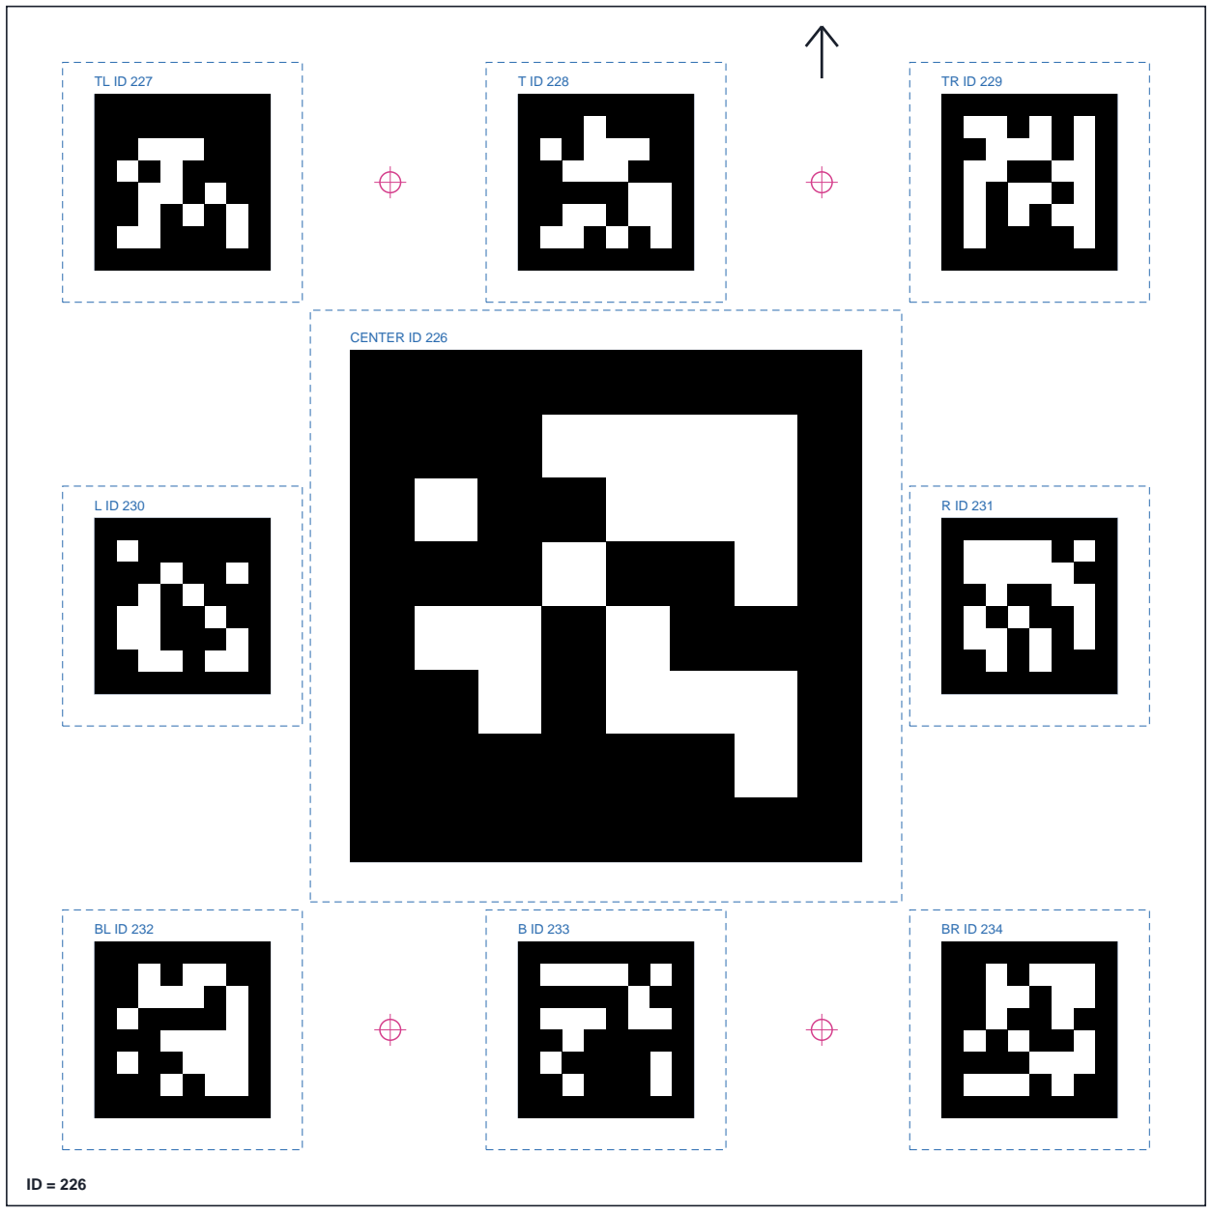
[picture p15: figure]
CENTER ID 226

## Center ID 226 | IDs 226-234

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

## ID LAYOUT

TL 227 | T 228 | TR 229
L 230 | CENTER 226 | R 231
BL 232 | B 233 | BR 234

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

board_15_ids_226-234.dxf

RESERVOIR APRILTAG BOARD - DXF REFERENCE | Page 16 / 20 | Center ID 235

# BOARD 16

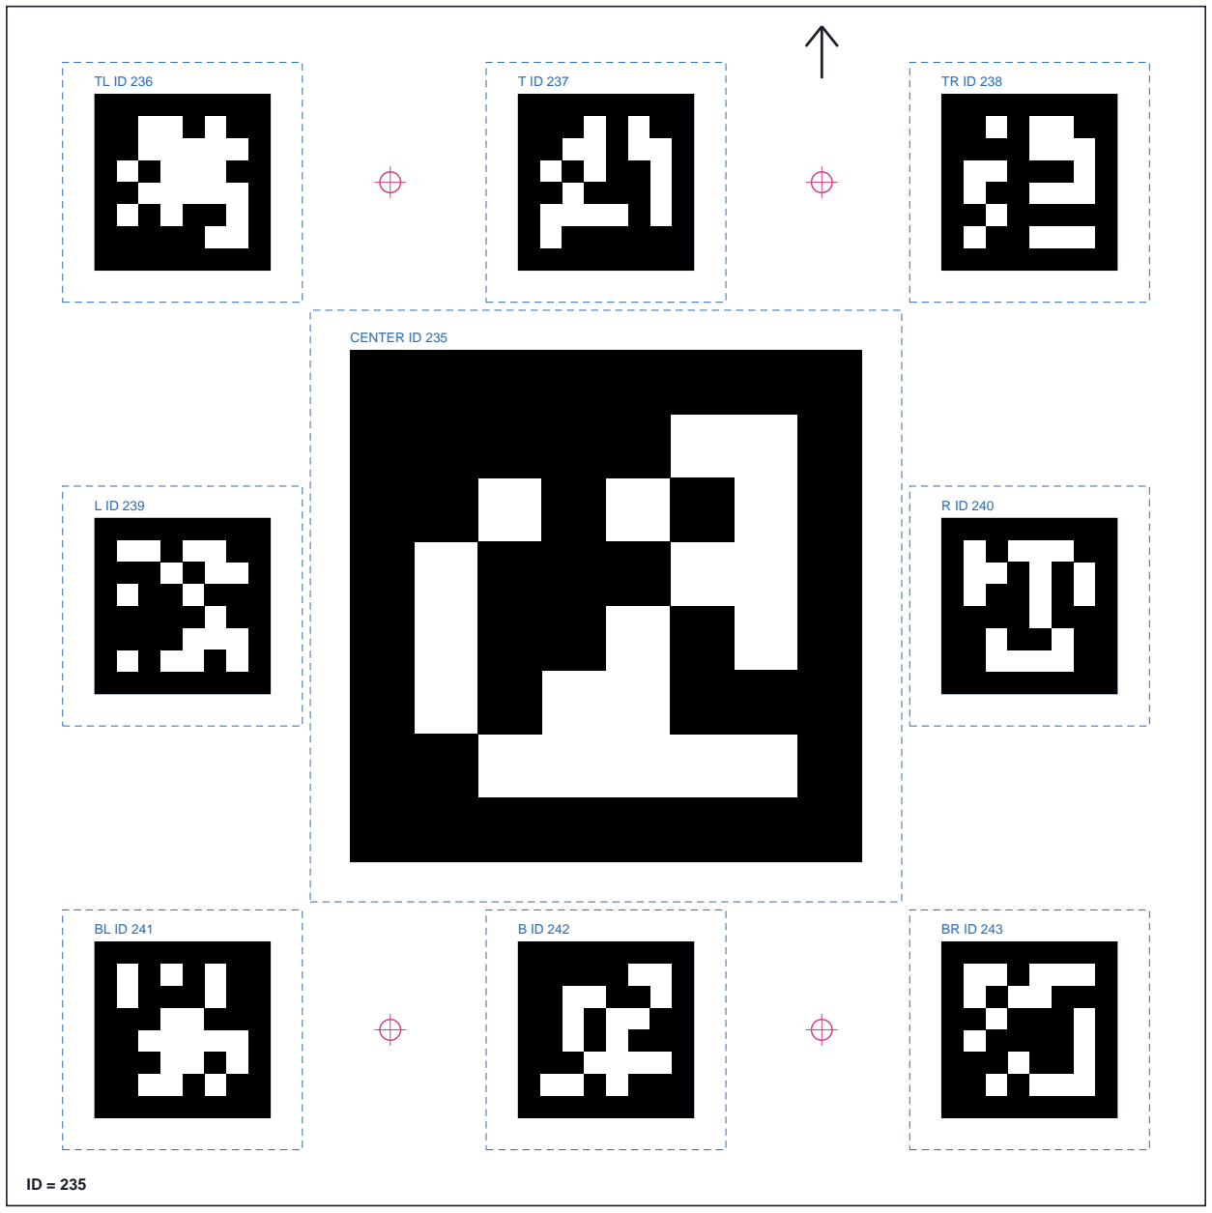
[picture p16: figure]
CENTER ID 235

## Center ID 235 | IDs 235-243

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

## ID LAYOUT

TL 236 | T 237 | TR 238
L 239 | CENTER 235 | R 240
BL 241 | B 242 | BR 243

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

board_16_ids_235-243.dxf

RESERVOIR APRILTAG BOARD - DXF REFERENCE | Page 17 / 20 | Center ID 244

# BOARD 17

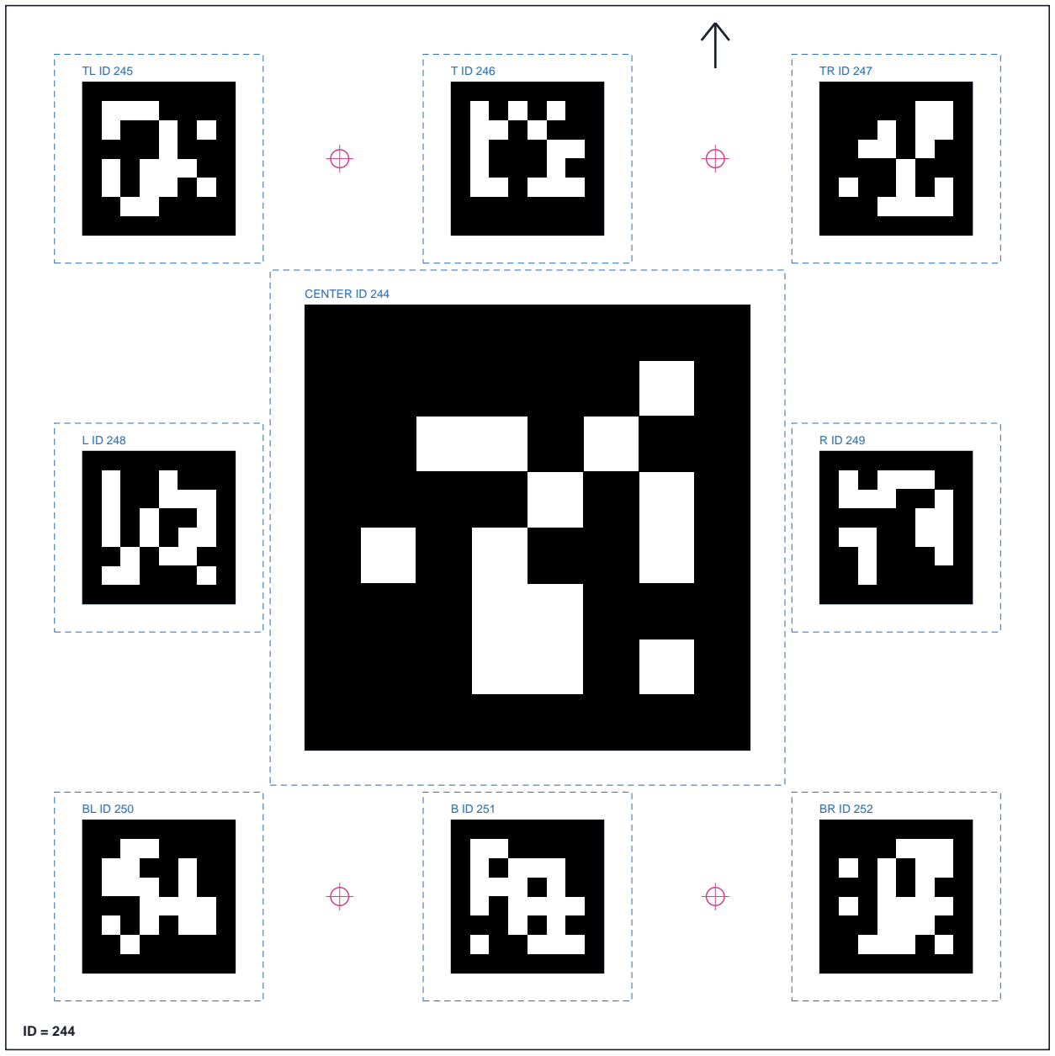
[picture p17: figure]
CENTER ID 244

## Center ID 244 | IDs 244-252

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

## ID LAYOUT

TL 245 | T 246 | TR 247
L 248 | CENTER 244 | R 249
BL 250 | B 251 | BR 252

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

board_17_ids_244-252.dxf

RESERVOIR APRILTAG BOARD - DXF REFERENCE | Page 18 / 20 | Center ID 253

# BOARD 18

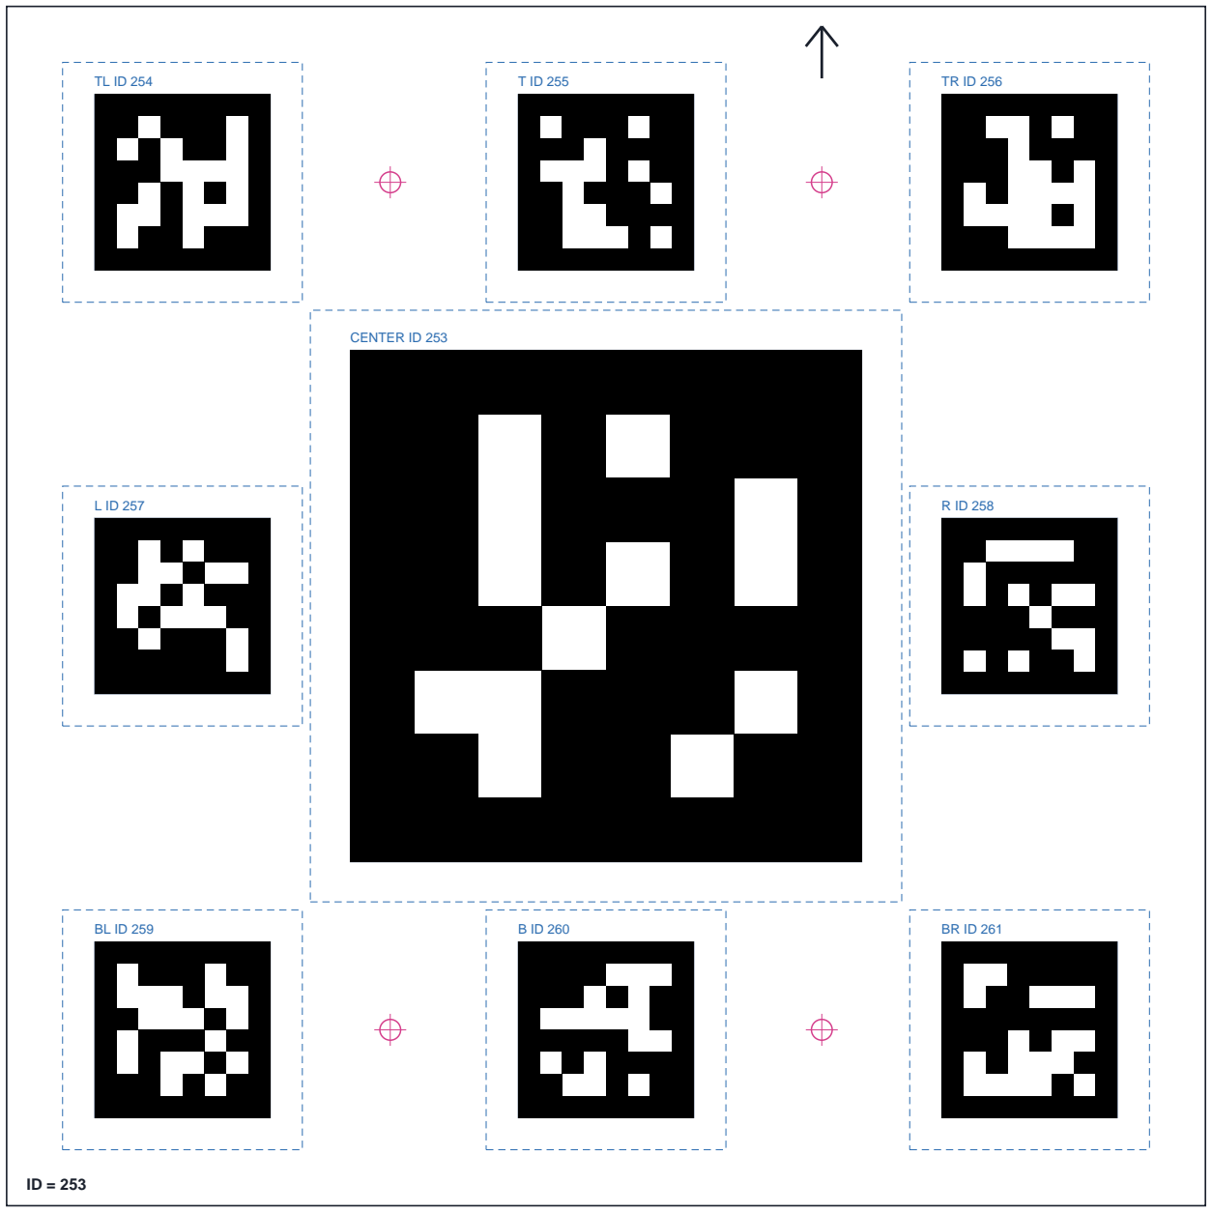
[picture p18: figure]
CENTER ID 253

## Center ID 253 | IDs 253-261

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

## ID LAYOUT

TL 254 | T 255 | TR 256
L 257 | CENTER 253 | R 258
BL 259 | B 260 | BR 261

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

board_18_ids_253-261.dxf

RESERVOIR APRILTAG BOARD - DXF REFERENCE | Page 19 / 20 | Center ID 262

# BOARD 19

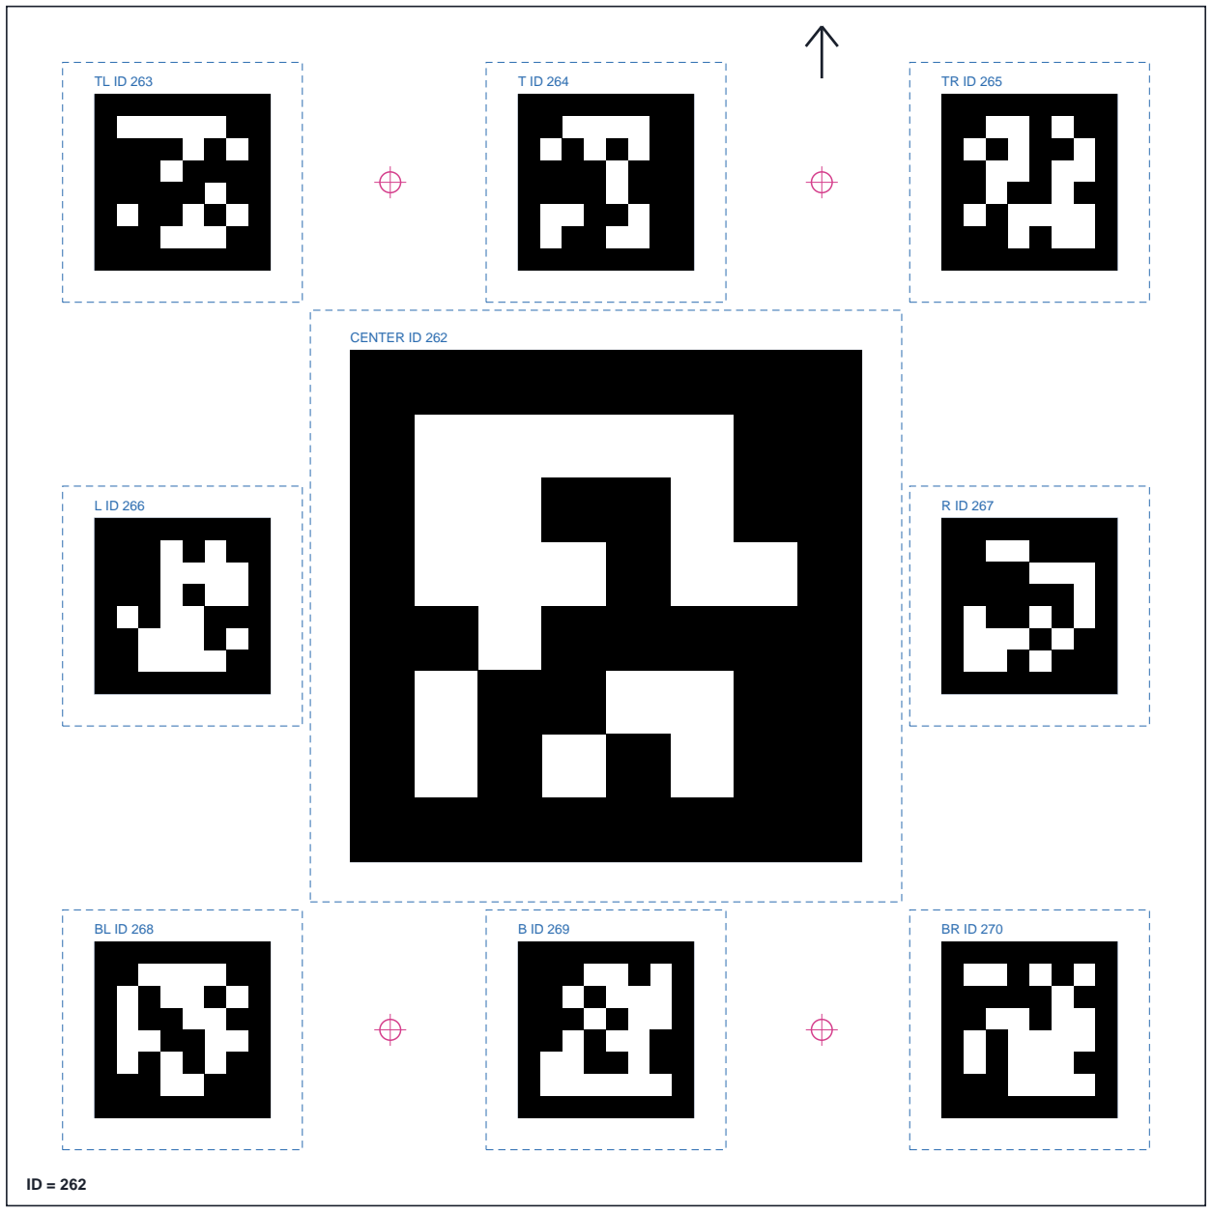
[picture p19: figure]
CENTER ID 262

## Center ID 262 | IDs 262-270

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

## ID LAYOUT

TL 263 | T 264 | TR 265
L 266 | CENTER 262 | R 267
BL 268 | B 269 | BR 270

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

board_19_ids_262-270.dxf

RESERVOIR APRILTAG BOARD - DXF REFERENCE | Page 20 / 20 | Center ID 271

# BOARD 20

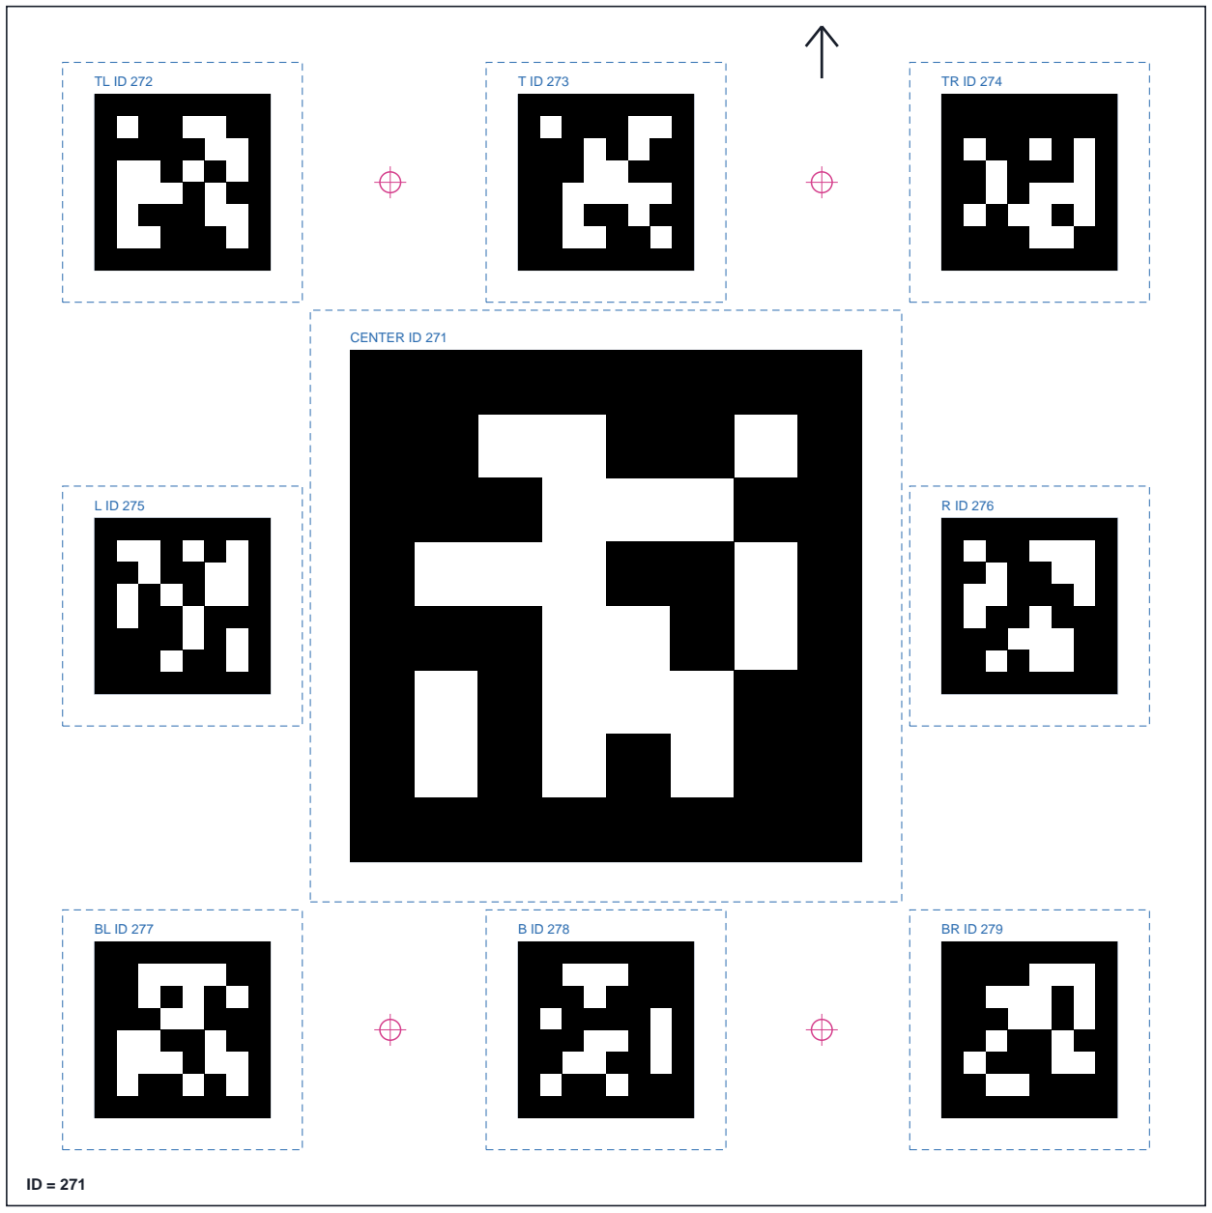
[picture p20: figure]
CENTER ID 271

## Center ID 271 | IDs 271-279

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

## ID LAYOUT

TL 272 | T 273 | TR 274
L 275 | CENTER 271 | R 276
BL 277 | B 278 | BR 279

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

board_20_ids_271-279.dxf

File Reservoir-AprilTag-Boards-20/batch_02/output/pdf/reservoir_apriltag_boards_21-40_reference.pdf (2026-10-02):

RESERVOIR APRILTAG BOARD - DXF REFERENCE | Page 1 / 20 | Center ID 280

# BOARD 21

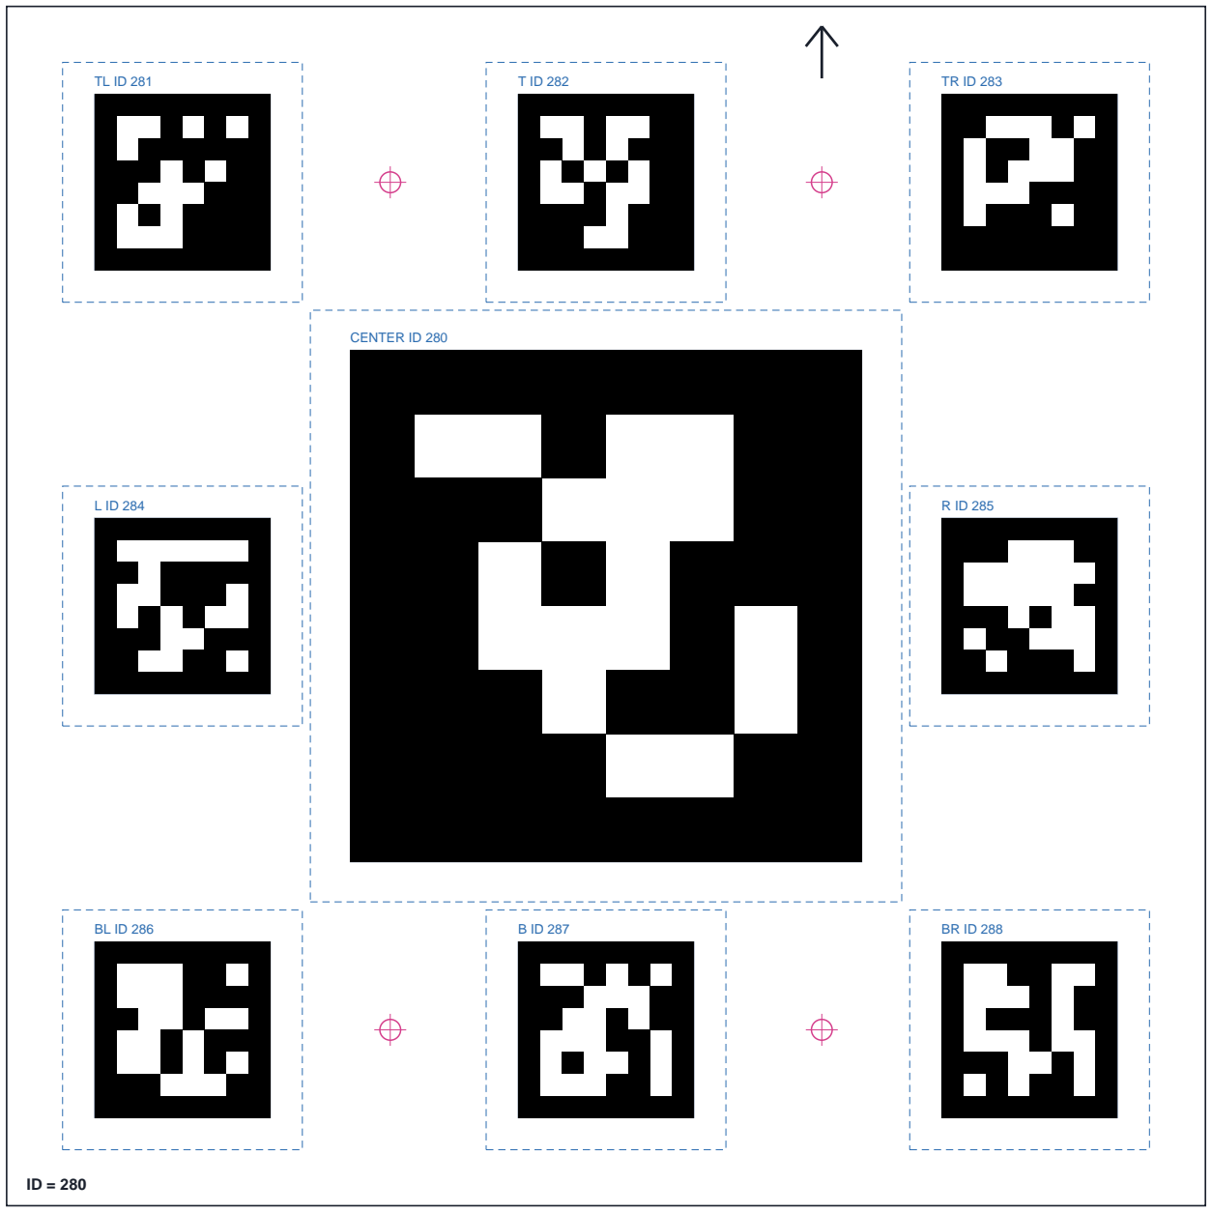
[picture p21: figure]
CENTER ID 280

## Center ID 280 | IDs 280-288

Board | 300 x 300 mm
Center marker | 128 mm
Outer markers | 8 x 44 mm
Mount holes | 4 x DIA 5.2 mm
Hole X | 96, 204 mm
Hole Y | 44, 256 mm

## ID LAYOUT

TL 281 | T 282 | TR 283
L 284 | CENTER 280 | R 285
BL 286 | B 287 | BR 288

Blue dashed: required white quiet zone Magenta: mounting holes and centers Reference diagram is scaled, not 1:1 Manufacture from DXF/SVG; DXF units are mm

board_21_ids_280-288.dxf

RESERVOIR APRILTAG BOARD - DXF REFERENCE | Page 2 / 20 | Center ID 289

# BOARD 22

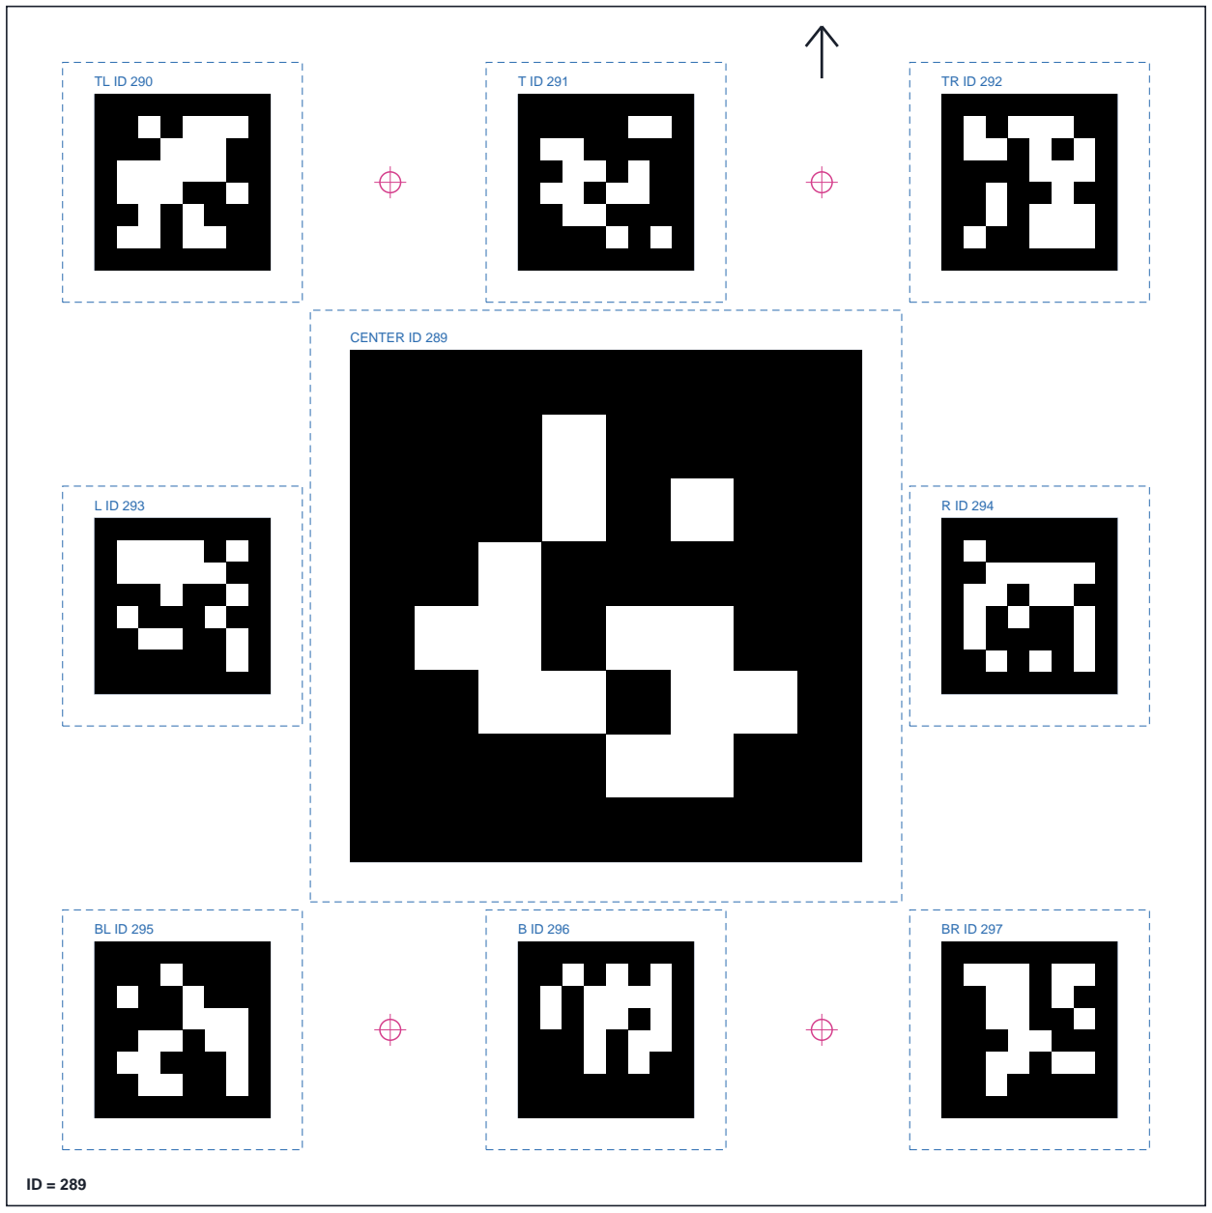
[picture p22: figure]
CENTER ID 289

## Center ID 289 | IDs 289-297

Board | 300 x 300 mm
Center marker | 128 mm
Outer markers | 8 x 44 mm
Mount holes | 4 x DIA 5.2 mm
Hole X | 96, 204 mm
Hole Y | 44, 256 mm

## ID LAYOUT

TL 290 | T 291 | TR 292
L 293 | CENTER 289 | R 294
BL 295 | B 296 | BR 297

Blue dashed: required white quiet zone Magenta: mounting holes and centers Reference diagram is scaled, not 1:1 Manufacture from DXF/SVG; DXF units are mm

board_22_ids_289-297.dxf

RESERVOIR APRILTAG BOARD - DXF REFERENCE | Page 3 / 20 | Center ID 298

# BOARD 23

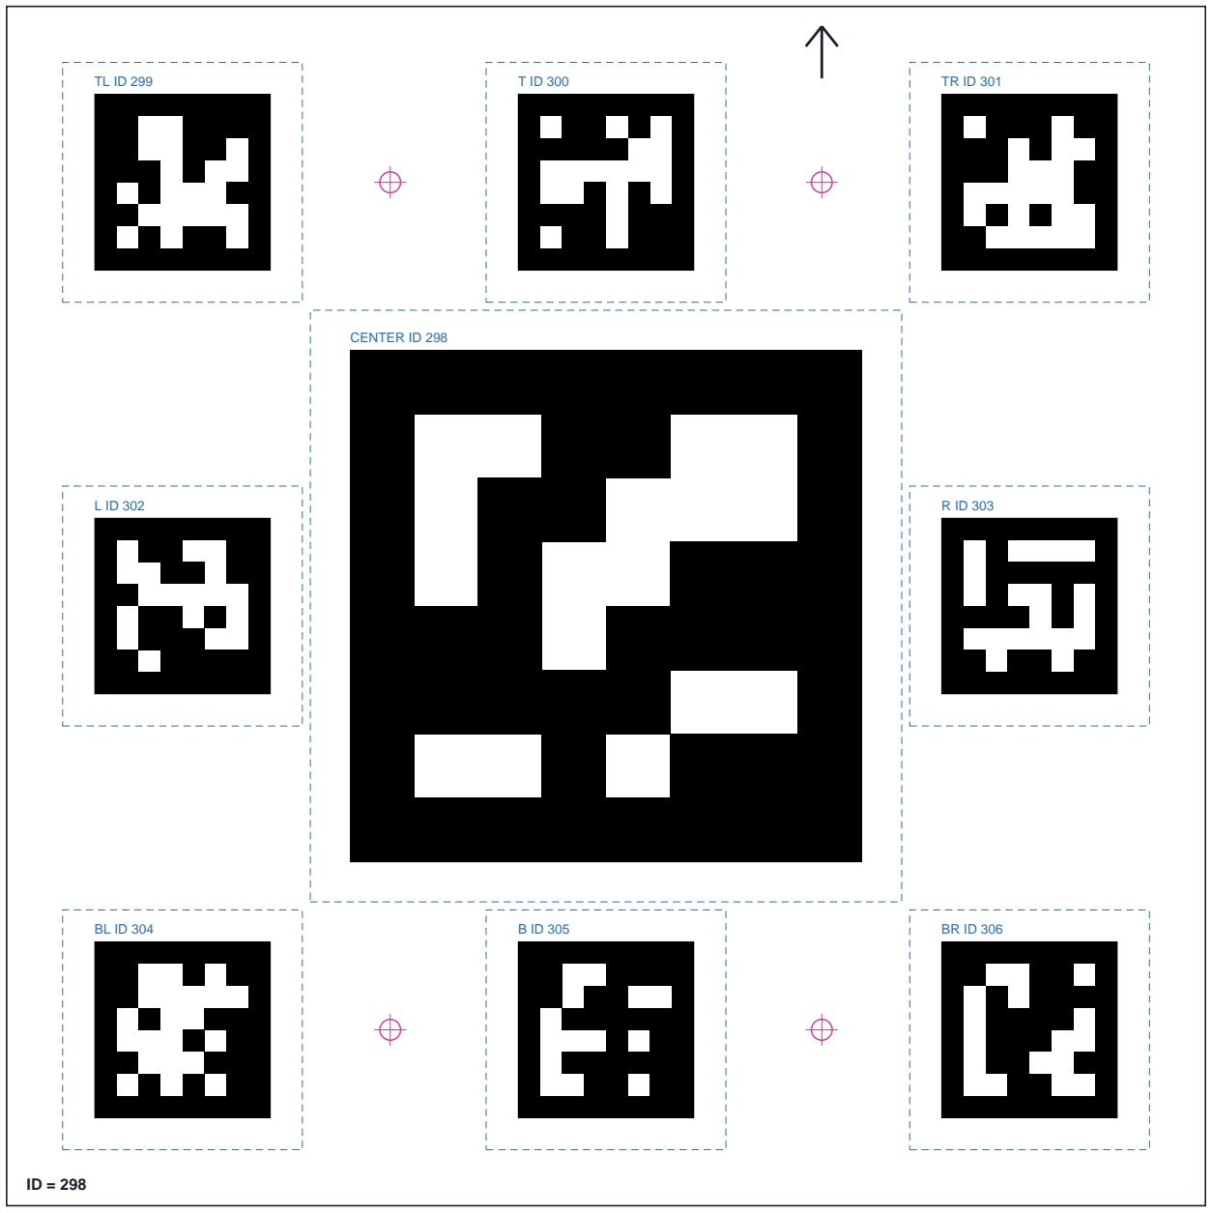
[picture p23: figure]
CENTER ID 298

## Center ID 298 | IDs 298-306

Board | 300 x 300 mm
Center marker | 128 mm
Outer markers | 8 x 44 mm
Mount holes | 4 x DIA 5.2 mm
Hole X | 96, 204 mm
Hole Y | 44, 256 mm

## ID LAYOUT

TL 299 | T 300 | TR 301
L 302 | CENTER 298 | R 303
BL 304 | B 305 | BR 306

Blue dashed: required white quiet zone Magenta: mounting holes and centers Reference diagram is scaled, not 1:1 Manufacture from DXF/SVG; DXF units are mm

board_23_ids_298-306.dxf

RESERVOIR APRILTAG BOARD - DXF REFERENCE | Page 4 / 20 | Center ID 307

# BOARD 24

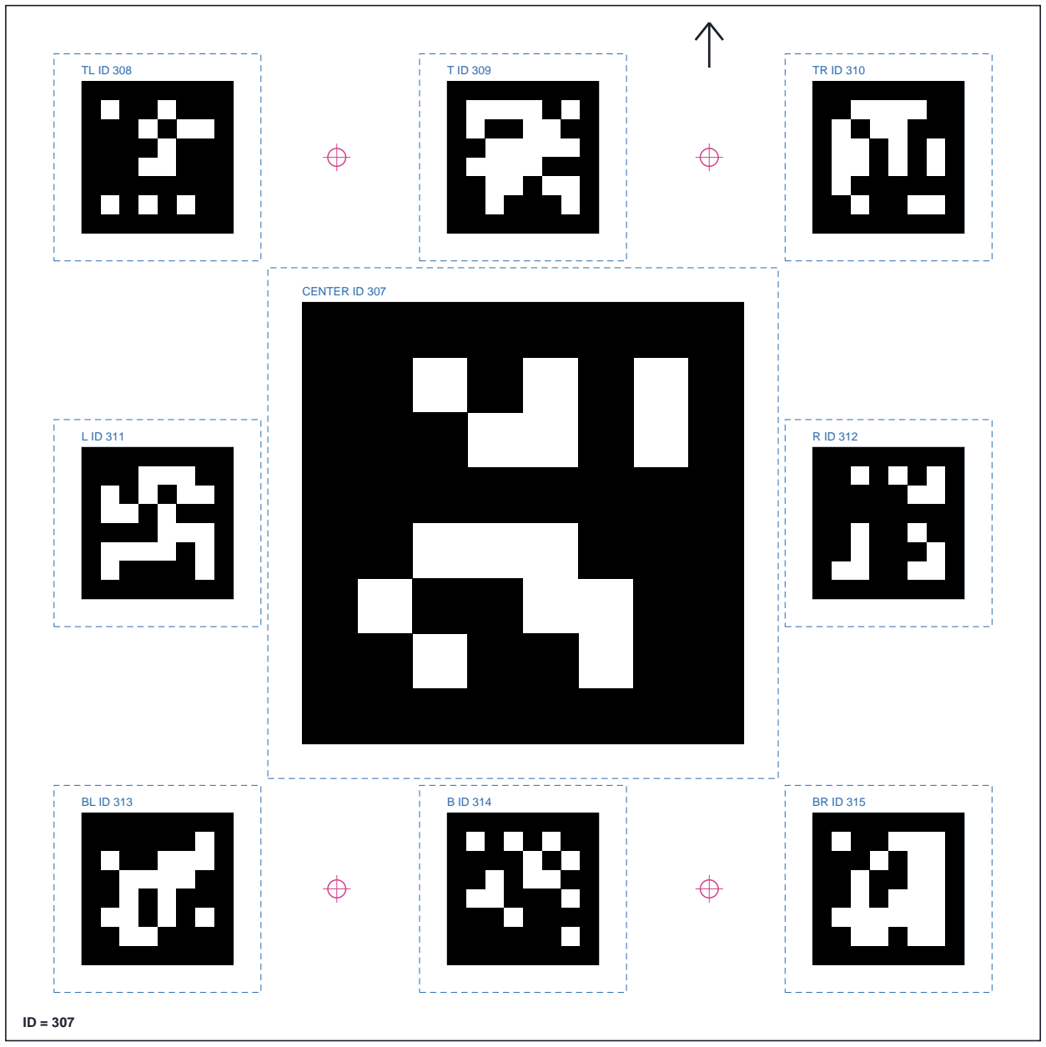
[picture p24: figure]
CENTER ID 307

## Center ID 307 | IDs 307-315

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

## ID LAYOUT

TL 308 | T 309 | TR 310
L 311 | CENTER 307 | R 312
BL 313 | B 314 | BR 315

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

board_24_ids_307-315.dxf

RESERVOIR APRILTAG BOARD - DXF REFERENCE | Page 5 / 20 | Center ID 316

# BOARD 25

CENTER ID 316

## Center ID 316 | IDs 316-324

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

## ID LAYOUT

TL 317 | T 318 | TR 319
L 320 | CENTER 316 | R 321
BL 322 | B 323 | BR 324

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

board_25_ids_316-324.dxf

RESERVOIR APRILTAG BOARD - DXF REFERENCE | Page 6 / 20 | Center ID 325

# BOARD 26

CENTER ID 325

## Center ID 325 | IDs 325-333

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

## ID LAYOUT

TL 326 | T 327 | TR 328
L 329 | CENTER 325 | R 330
BL 331 | B 332 | BR 333

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

board_26_ids_325-333.dxf

RESERVOIR APRILTAG BOARD - DXF REFERENCE | Page 7 / 20 | Center ID 334

# BOARD 27

CENTER ID 334

## Center ID 334 | IDs 334-342

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

## ID LAYOUT

TL 335 | T 336 | TR 337
L 338 | CENTER 334 | R 339
BL 340 | B 341 | BR 342

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

board_27_ids_334-342.dxf

RESERVOIR APRILTAG BOARD - DXF REFERENCE | Page 8 / 20 | Center ID 343

# BOARD 28

CENTER ID 343

## Center ID 343 | IDs 343-351

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

## ID LAYOUT

TL 344 | T 345 | TR 346
L 347 | CENTER 343 | R 348
BL 349 | B 350 | BR 351

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

board_28_ids_343-351.dxf

RESERVOIR APRILTAG BOARD - DXF REFERENCE | Page 9 / 20 | Center ID 352

# BOARD 29

CENTER ID 352

## Center ID 352 | IDs 352-360

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

## ID LAYOUT

TL 353 | T 354 | TR 355
L 356 | CENTER 352 | R 357
BL 358 | B 359 | BR 360

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

board_29_ids_352-360.dxf

RESERVOIR APRILTAG BOARD - DXF REFERENCE | Page 10 / 20 | Center ID 361

# BOARD 30

CENTER ID 361

## Center ID 361 | IDs 361-369

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

## ID LAYOUT

TL 362 | T 363 | TR 364
L 365 | CENTER 361 | R 366
BL 367 | B 368 | BR 369

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

board_30_ids_361-369.dxf

RESERVOIR APRILTAG BOARD - DXF REFERENCE | Page 11 / 20 | Center ID 370

# BOARD 31

CENTER ID 370

## Center ID 370 | IDs 370-378

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

## ID LAYOUT

TL 371 | T 372 | TR 373
L 374 | CENTER 370 | R 375
BL 376 | B 377 | BR 378

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

board_31_ids_370-378.dxf

RESERVOIR APRILTAG BOARD - DXF REFERENCE | Page 12 / 20 | Center ID 379

# BOARD 32

CENTER ID 379

## Center ID 379 | IDs 379-387

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

## ID LAYOUT

TL 380 | T 381 | TR 382
L 383 | CENTER 379 | R 384
BL 385 | B 386 | BR 387

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

board_32_ids_379-387.dxf

RESERVOIR APRILTAG BOARD - DXF REFERENCE | Page 13 / 20 | Center ID 388

# BOARD 33

CENTER ID 388

## Center ID 388 | IDs 388-396

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

## ID LAYOUT

TL 389 | T 390 | TR 391
L 392 | CENTER 388 | R 393
BL 394 | B 395 | BR 396

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

board_33_ids_388-396.dxf

RESERVOIR APRILTAG BOARD - DXF REFERENCE | Page 14 / 20 | Center ID 397

# BOARD 34

CENTER ID 397

## Center ID 397 | IDs 397-405

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

## ID LAYOUT

TL 398 | T 399 | TR 400
L 401 | CENTER 397 | R 402
BL 403 | B 404 | BR 405

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

board_34_ids_397-405.dxf

RESERVOIR APRILTAG BOARD - DXF REFERENCE | Page 15 / 20 | Center ID 406

# BOARD 35

CENTER ID 406

## Center ID 406 | IDs 406-414

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

## ID LAYOUT

TL 407 | T 408 | TR 409
L 410 | CENTER 406 | R 411
BL 412 | B 413 | BR 414

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

board_35_ids_406-414.dxf

RESERVOIR APRILTAG BOARD - DXF REFERENCE | Page 16 / 20 | Center ID 415

# BOARD 36

CENTER ID 415

## Center ID 415 | IDs 415-423

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

## ID LAYOUT

TL 416 | T 417 | TR 418
L 419 | CENTER 415 | R 420
BL 421 | B 422 | BR 423

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

board_36_ids_415-423.dxf

RESERVOIR APRILTAG BOARD - DXF REFERENCE | Page 17 / 20 | Center ID 424

# BOARD 37

CENTER ID 424

## Center ID 424 | IDs 424-432

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

## ID LAYOUT

TL 425 | T 426 | TR 427
L 428 | CENTER 424 | R 429
BL 430 | B 431 | BR 432

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

board_37_ids_424-432.dxf

RESERVOIR APRILTAG BOARD - DXF REFERENCE | Page 18 / 20 | Center ID 433

# BOARD 38

CENTER ID 433

## Center ID 433 | IDs 433-441

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

## ID LAYOUT

TL 434 | T 435 | TR 436
L 437 | CENTER 433 | R 438
BL 439 | B 440 | BR 441

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

board_38_ids_433-441.dxf

RESERVOIR APRILTAG BOARD - DXF REFERENCE | Page 19 / 20 | Center ID 442

# BOARD 39

CENTER ID 442

## Center ID 442 | IDs 442-450

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

## ID LAYOUT

TL 443 | T 444 | TR 445
L 446 | CENTER 442 | R 447
BL 448 | B 449 | BR 450

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

board_39_ids_442-450.dxf

RESERVOIR APRILTAG BOARD - DXF REFERENCE | Page 20 / 20 | Center ID 451

# BOARD 40

CENTER ID 451

## Center ID 451 | IDs 451-459

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

## ID LAYOUT

TL 452 | T 453 | TR 454
L 455 | CENTER 451 | R 456
BL 457 | B 458 | BR 459

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

board_40_ids_451-459.dxf

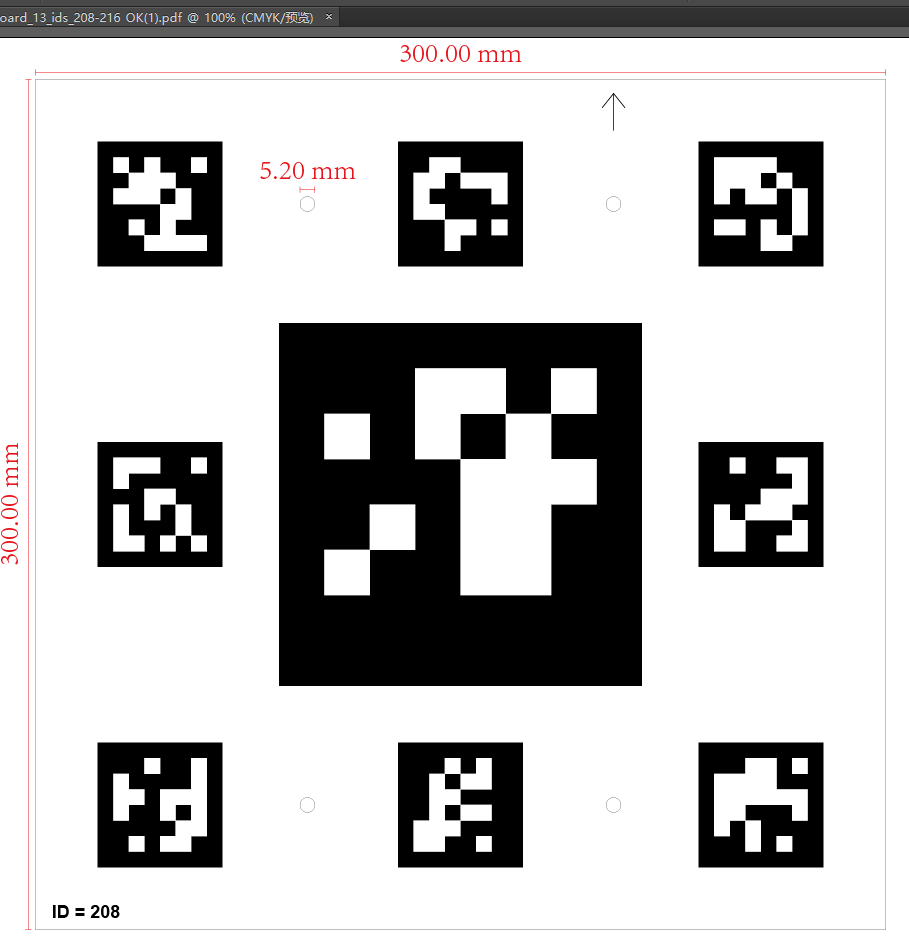
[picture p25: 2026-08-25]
Reservoir-AprilTag-Boards-20/加工厂复核/微信图片_20260824111636_379_489.png

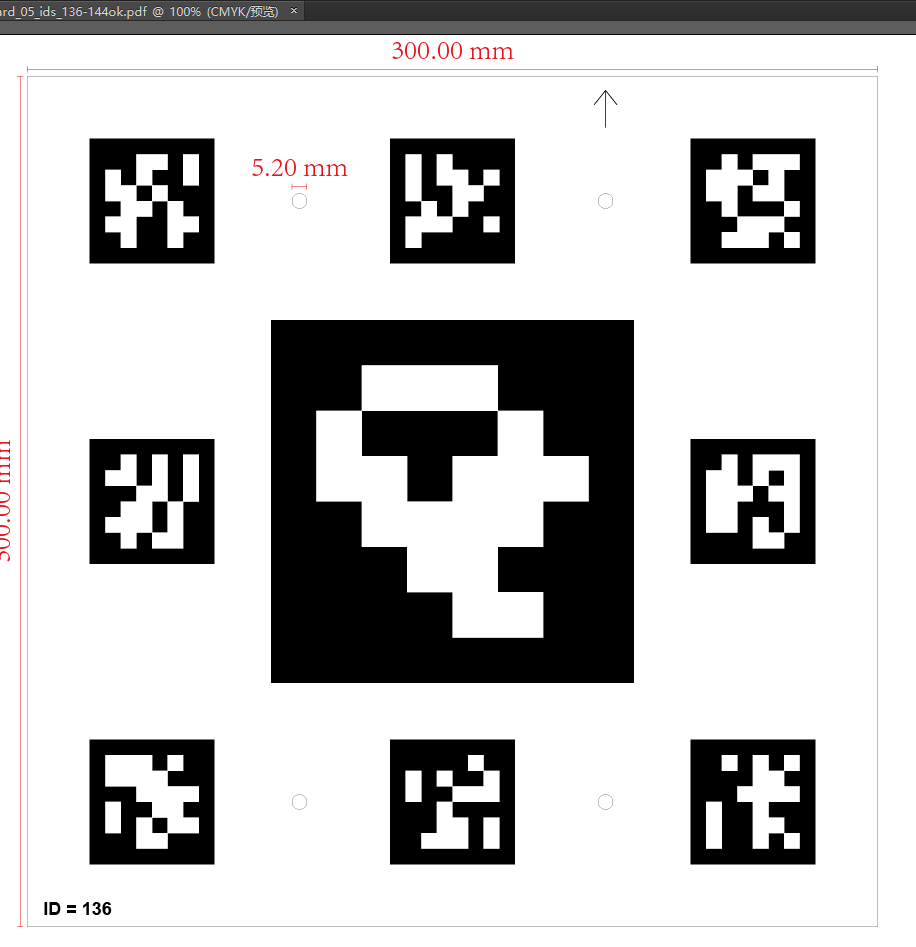
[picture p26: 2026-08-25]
Reservoir-AprilTag-Boards-20/加工厂复核/微信图片_20260824111518_371_489.png

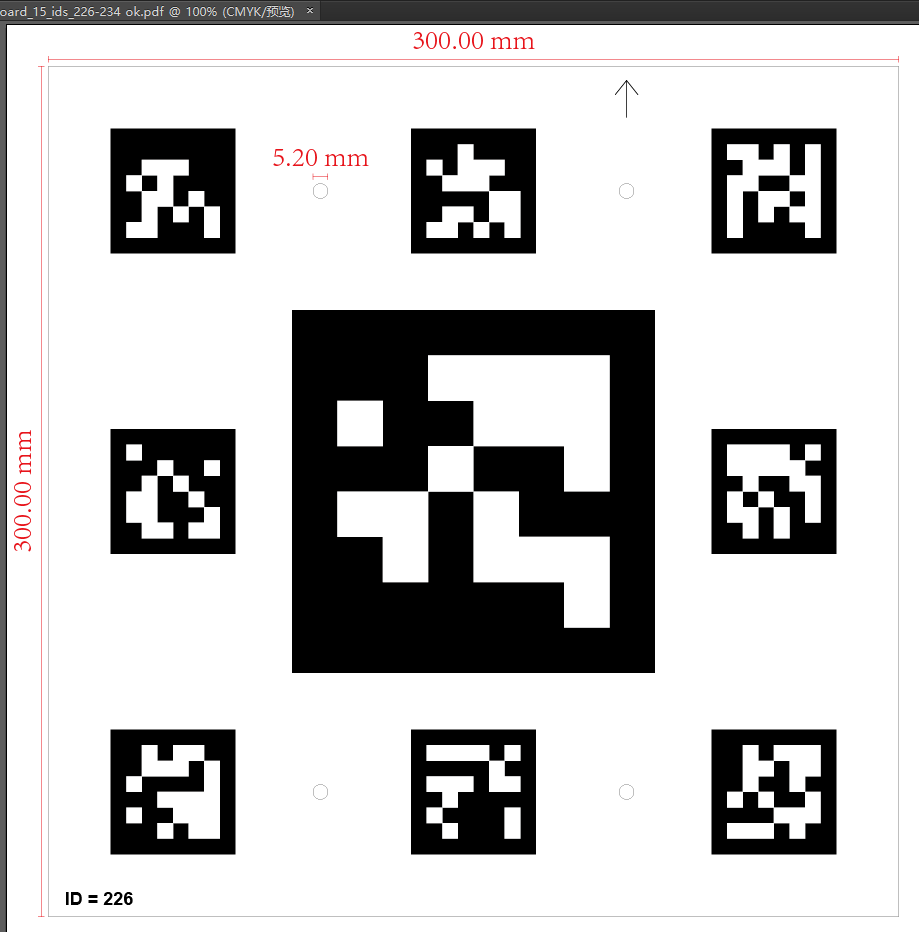
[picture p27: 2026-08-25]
Reservoir-AprilTag-Boards-20/加工厂复核/微信图片_20260824111822_381_489.png

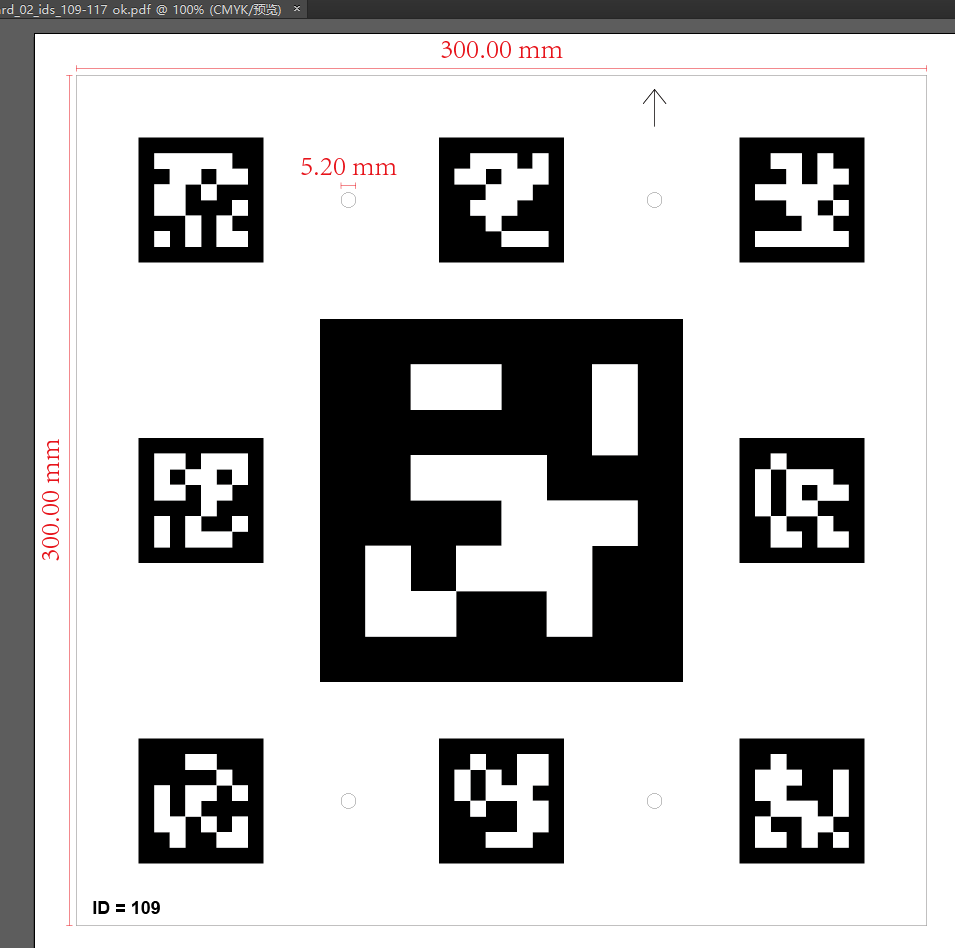
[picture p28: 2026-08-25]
Reservoir-AprilTag-Boards-20/加工厂复核/微信图片_20260824111516_368_489.png

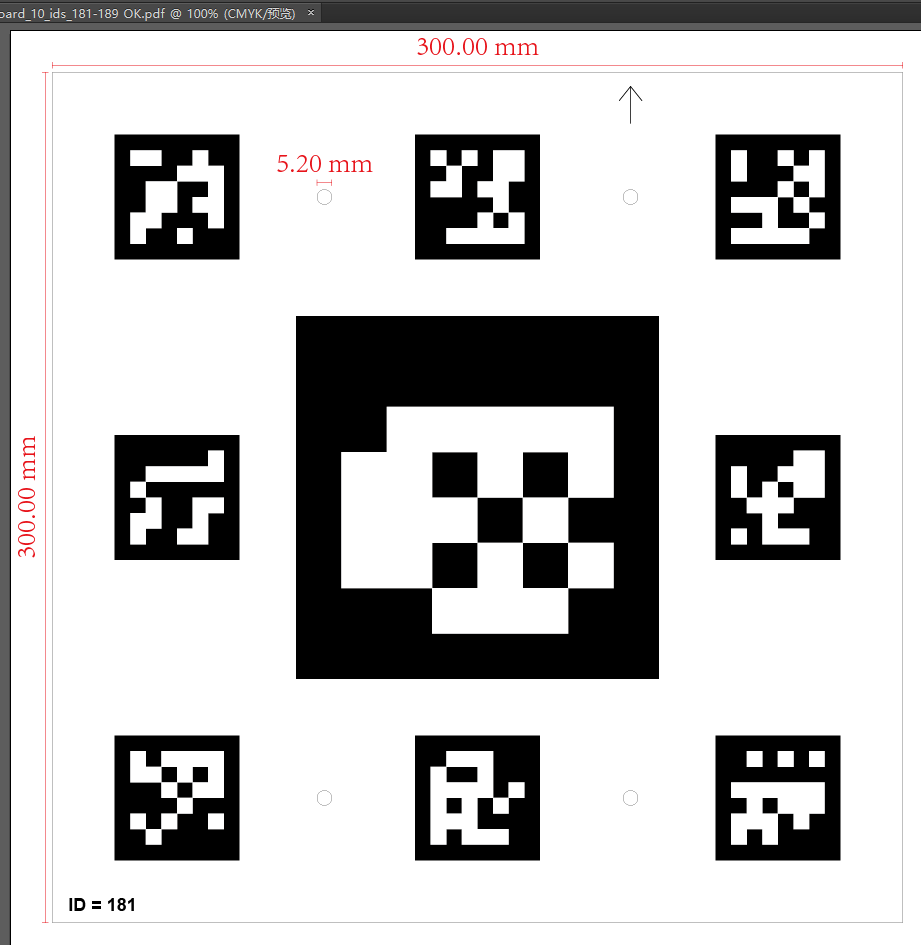
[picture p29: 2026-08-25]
Reservoir-AprilTag-Boards-20/加工厂复核/微信图片_20260824111535_376_489.png

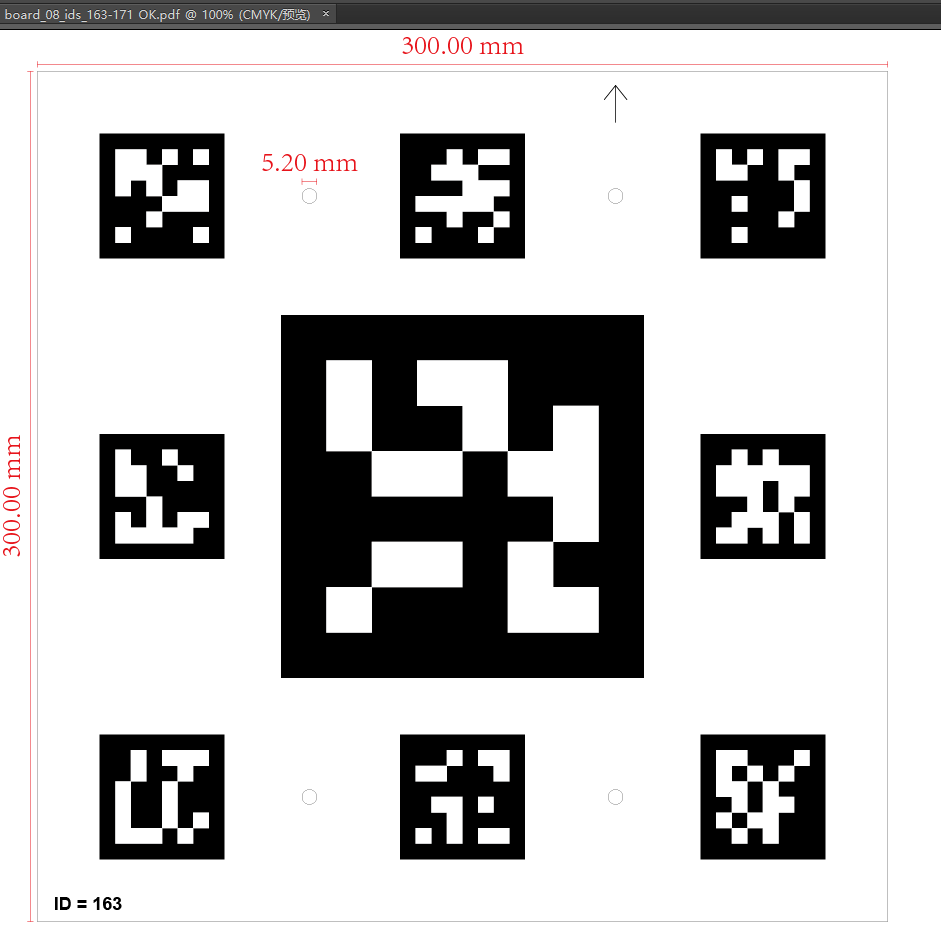
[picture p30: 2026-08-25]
Reservoir-AprilTag-Boards-20/加工厂复核/微信图片_20260824111519_374_489.png

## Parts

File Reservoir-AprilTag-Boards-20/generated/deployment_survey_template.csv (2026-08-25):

board_no | center_tag_id | tag_id_range | reservoir_zone | position_x_m | position_y_m | position_z_m | yaw_deg | pitch_deg | roll_deg | installed_date | photo_reference | notes
R01 | 100 | 100-108
R02 | 109 | 109-117
R03 | 118 | 118-126
R04 | 127 | 127-135
R05 | 136 | 136-144
R06 | 145 | 145-153
R07 | 154 | 154-162
R08 | 163 | 163-171
R09 | 172 | 172-180
R10 | 181 | 181-189
R11 | 190 | 190-198
R12 | 199 | 199-207
R13 | 208 | 208-216
R14 | 217 | 217-225
R15 | 226 | 226-234
R16 | 235 | 235-243
R17 | 244 | 244-252
R18 | 253 | 253-261
R19 | 262 | 262-270
R20 | 271 | 271-279

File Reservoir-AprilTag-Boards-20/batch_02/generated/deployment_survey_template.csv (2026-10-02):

board_no | center_tag_id | tag_id_range | reservoir_zone | position_x_m | position_y_m | position_z_m | yaw_deg | pitch_deg | roll_deg | installed_date | photo_reference | notes
R21 | 280 | 280-288
R22 | 289 | 289-297
R23 | 298 | 298-306
R24 | 307 | 307-315
R25 | 316 | 316-324
R26 | 325 | 325-333
R27 | 334 | 334-342
R28 | 343 | 343-351
R29 | 352 | 352-360
R30 | 361 | 361-369
R31 | 370 | 370-378
R32 | 379 | 379-387
R33 | 388 | 388-396
R34 | 397 | 397-405
R35 | 406 | 406-414
R36 | 415 | 415-423
R37 | 424 | 424-432
R38 | 433 | 433-441
R39 | 442 | 442-450
R40 | 451 | 451-459

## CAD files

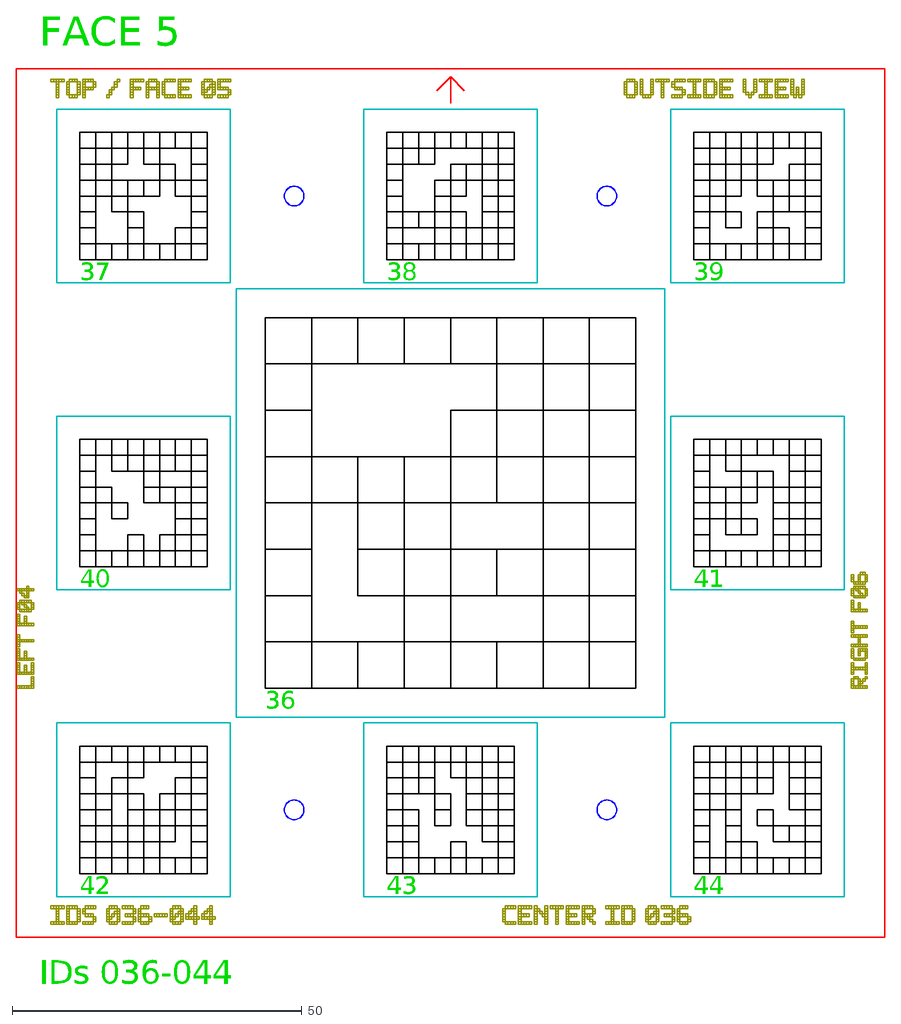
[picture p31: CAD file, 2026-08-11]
generated/face_05_guide.dxf
FACE 5
IDs 036-044
36
37
38
39
40
41
42
43
44

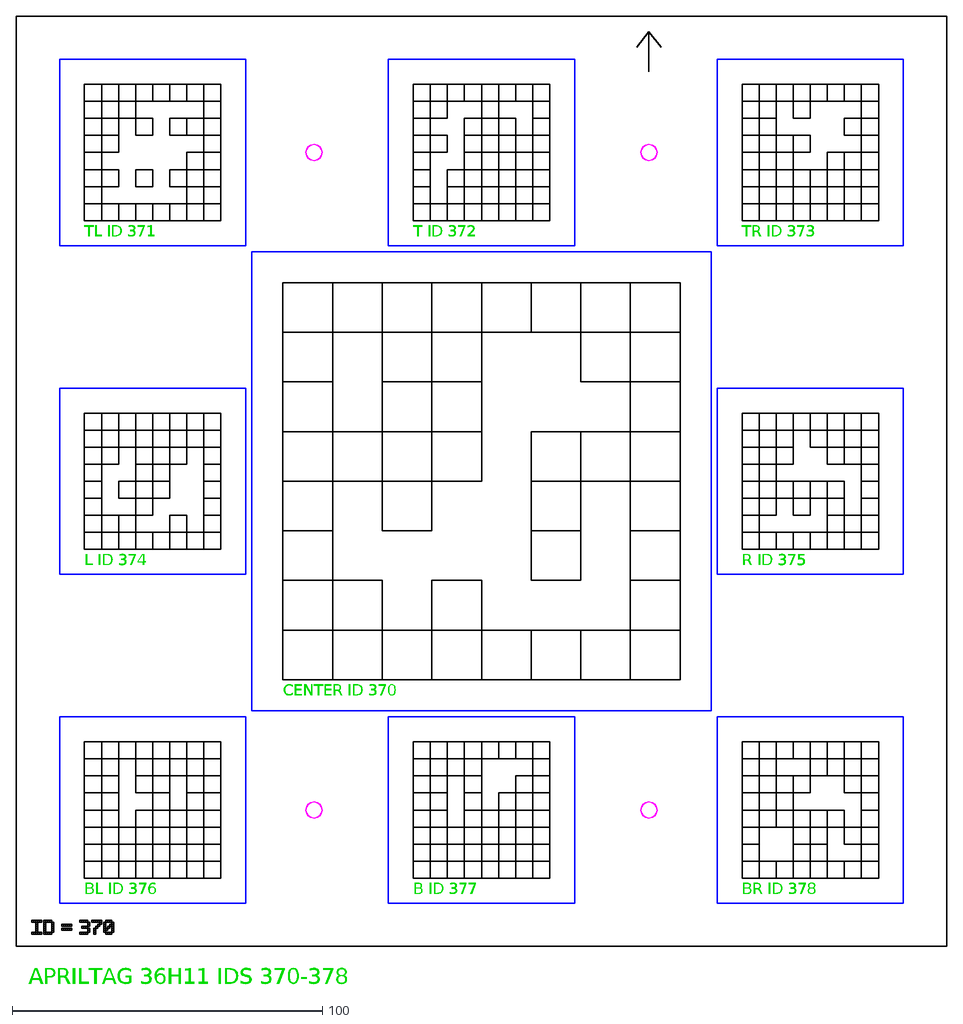
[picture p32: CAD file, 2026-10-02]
Reservoir-AprilTag-Boards-20/batch_02/generated/board_31_ids_370-378_guide.dxf
CENTER ID 370
TL ID 371
T ID 372
TR ID 373
L ID 374
R ID 375
BL ID 376
B ID 377
BR ID 378
APRILTAG 36H11 IDS 370-378

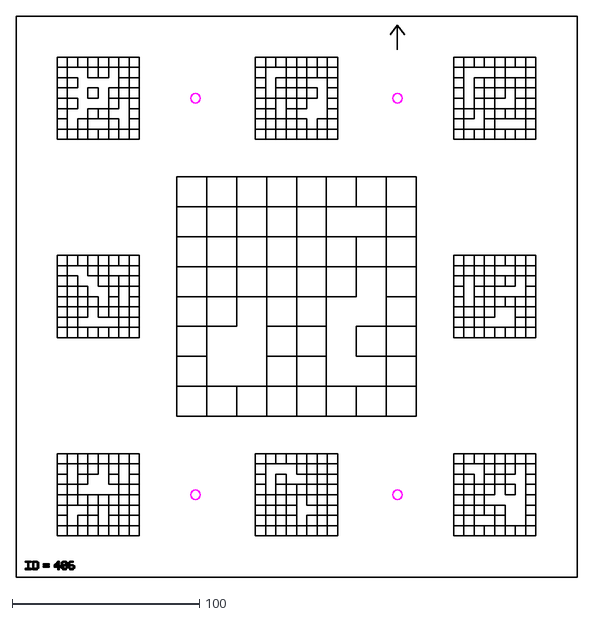
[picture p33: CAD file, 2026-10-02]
Reservoir-AprilTag-Boards-20/batch_02/manufacturing/board_35_ids_406-414.dxf
300.0 x 300.0

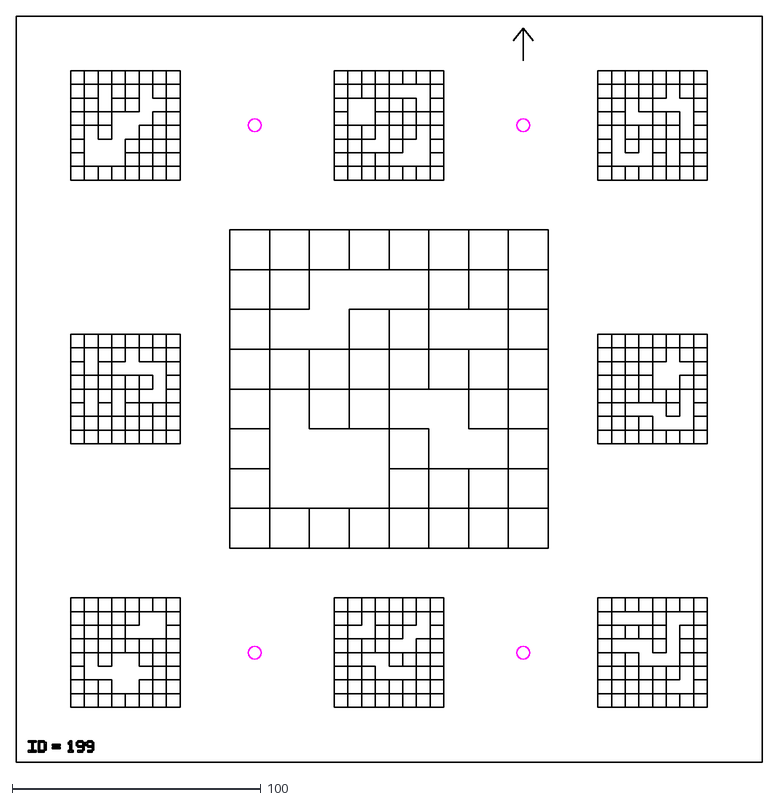
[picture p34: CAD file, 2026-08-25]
Reservoir-AprilTag-Boards-20/generated/board_12_ids_199-207.dxf
300.0 x 300.0

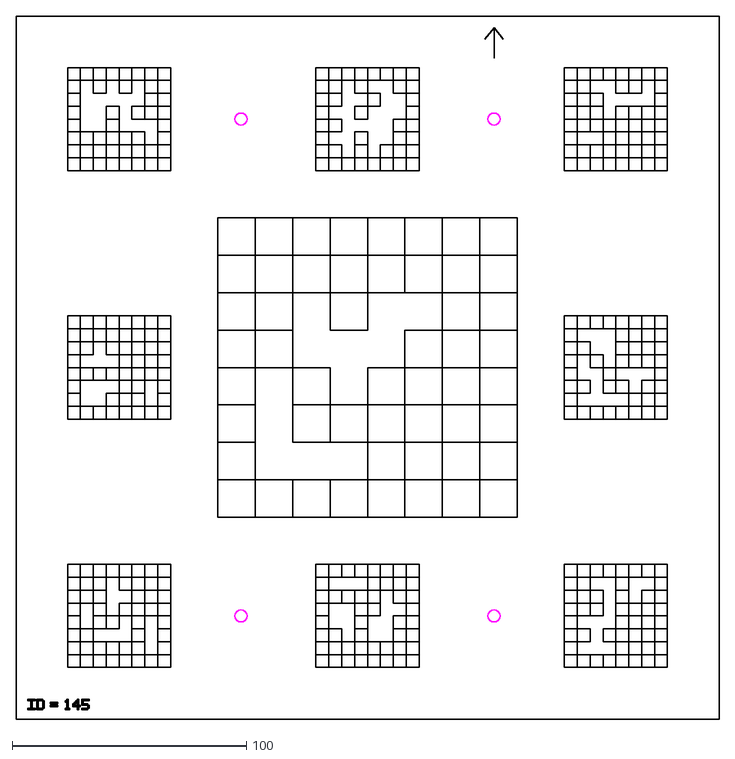
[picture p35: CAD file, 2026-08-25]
Reservoir-AprilTag-Boards-20/generated/boards/board_06_ids_145-153.dxf
300.0 x 300.0

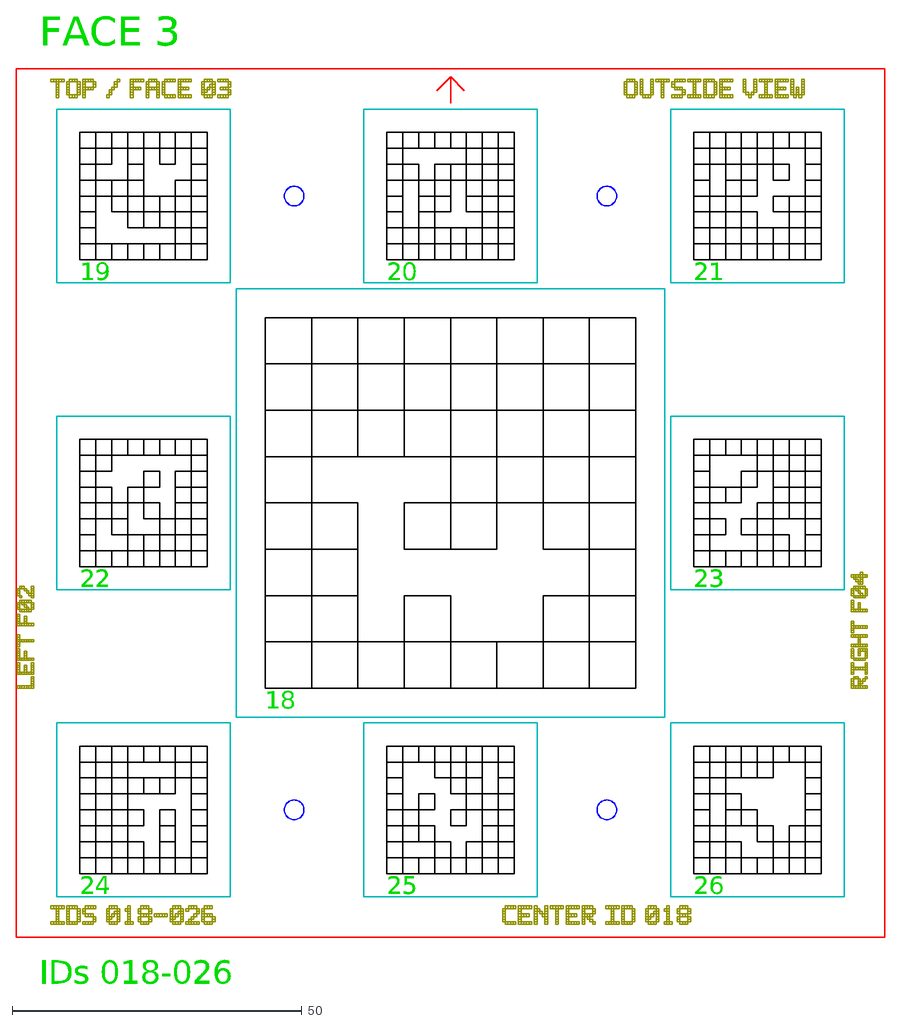
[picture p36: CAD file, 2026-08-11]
generated/face_03_guide.dxf
FACE 3
IDs 018-026
18
19
20
21
22
23
24
25
26

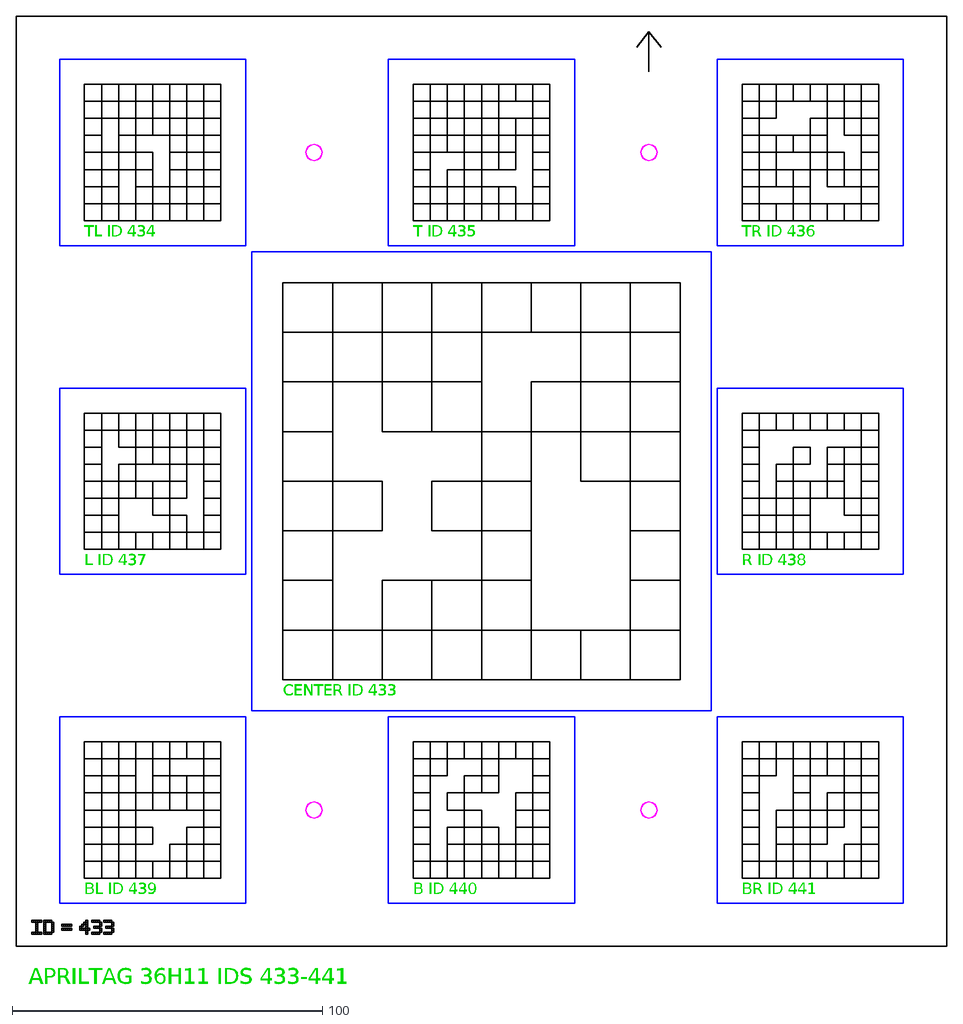
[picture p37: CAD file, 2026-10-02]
Reservoir-AprilTag-Boards-20/batch_02/generated/board_38_ids_433-441_guide.dxf
CENTER ID 433
TL ID 434
T ID 435
TR ID 436
L ID 437
R ID 438
BL ID 439
B ID 440
BR ID 441
APRILTAG 36H11 IDS 433-441

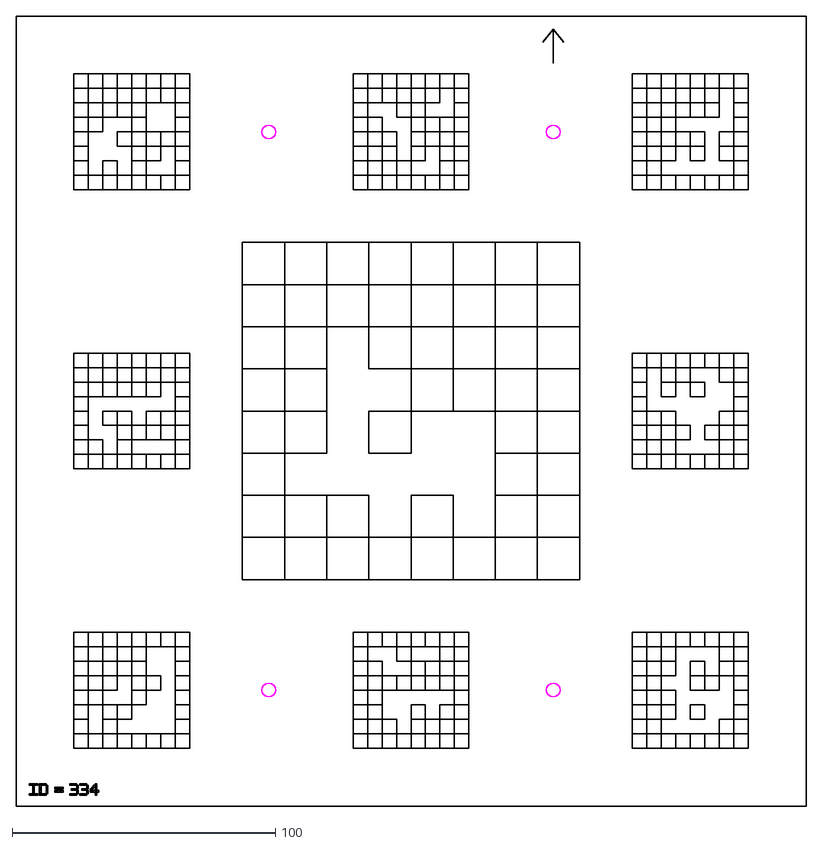
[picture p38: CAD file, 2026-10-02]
Reservoir-AprilTag-Boards-20/batch_02/manufacturing/board_27_ids_334-342.dxf
300.0 x 300.0

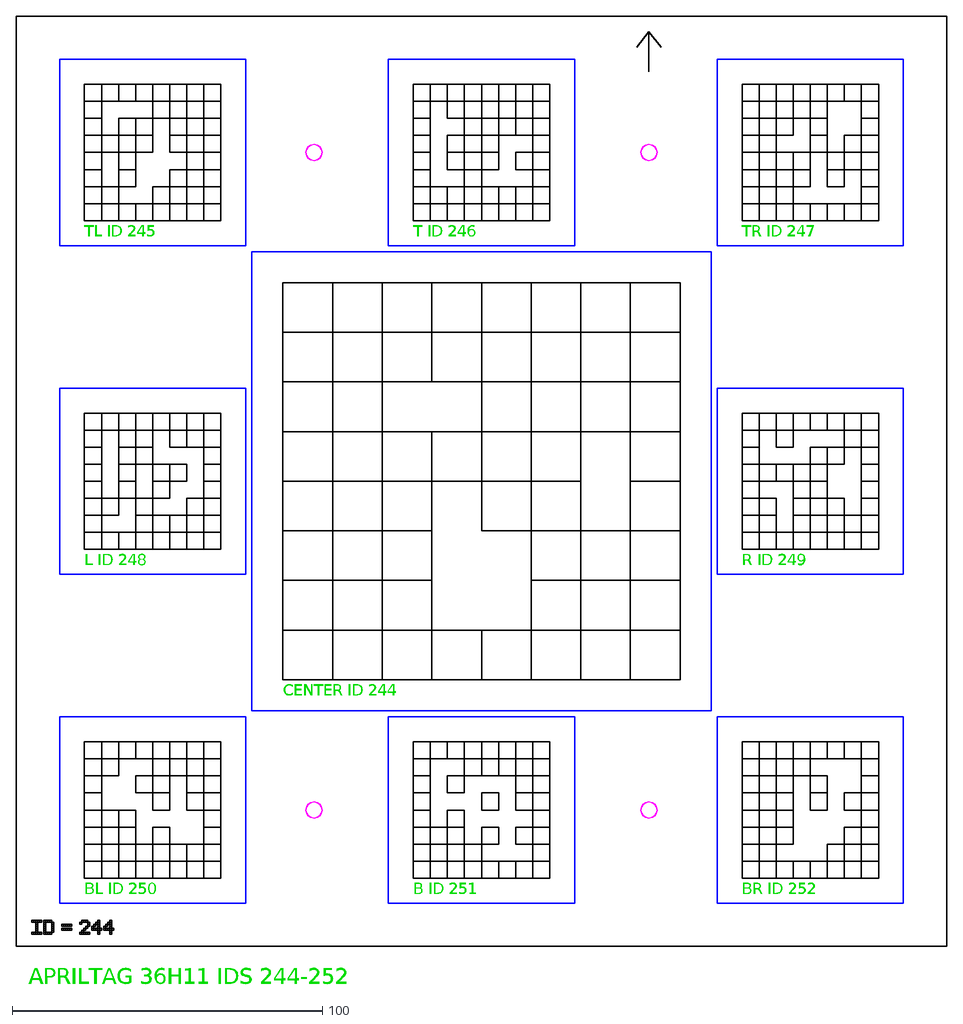
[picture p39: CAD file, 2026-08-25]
Reservoir-AprilTag-Boards-20/generated/board_17_ids_244-252_guide.dxf
CENTER ID 244
TL ID 245
T ID 246
TR ID 247
L ID 248
R ID 249
BL ID 250
B ID 251
BR ID 252
APRILTAG 36H11 IDS 244-252

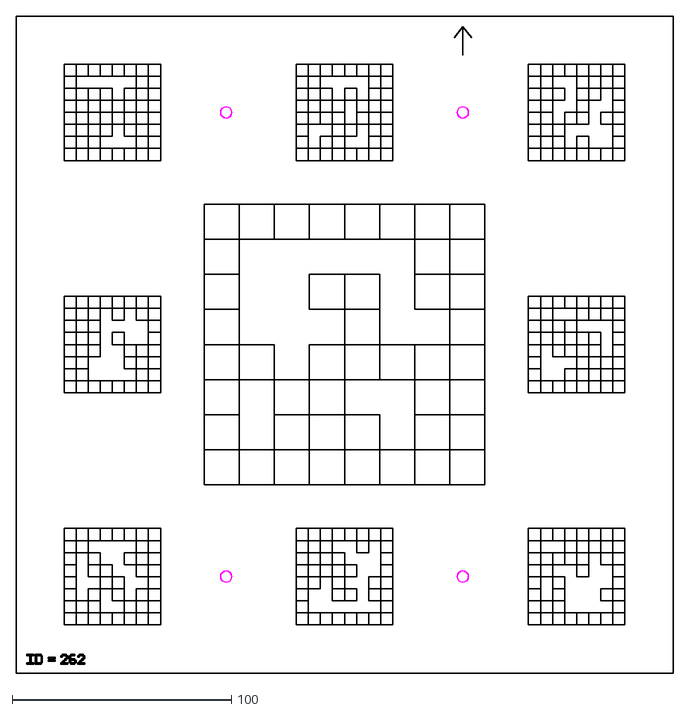
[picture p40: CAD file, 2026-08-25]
Reservoir-AprilTag-Boards-20/generated/boards/board_19_ids_262-270.dxf
300.0 x 300.0

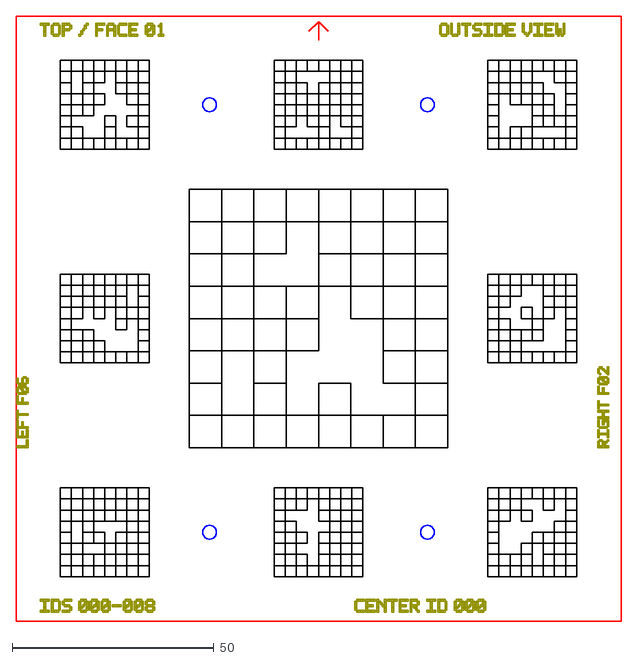
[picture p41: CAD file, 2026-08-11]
generated/face_01.dxf
150.0 x 150.0

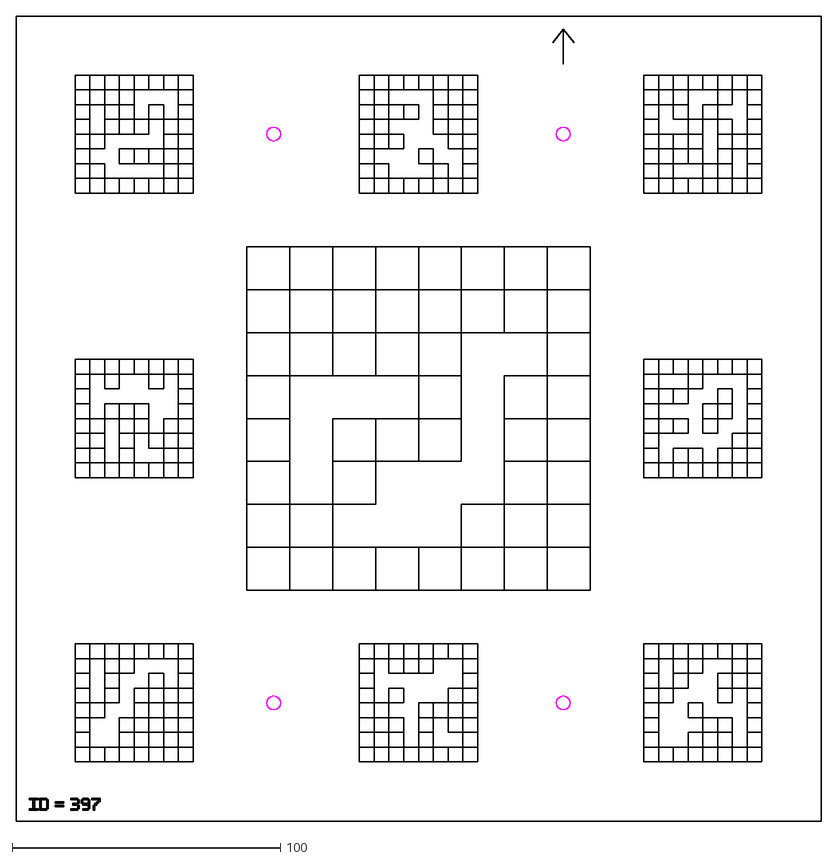
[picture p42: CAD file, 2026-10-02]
Reservoir-AprilTag-Boards-20/batch_02/generated/board_34_ids_397-405.dxf
300.0 x 300.0

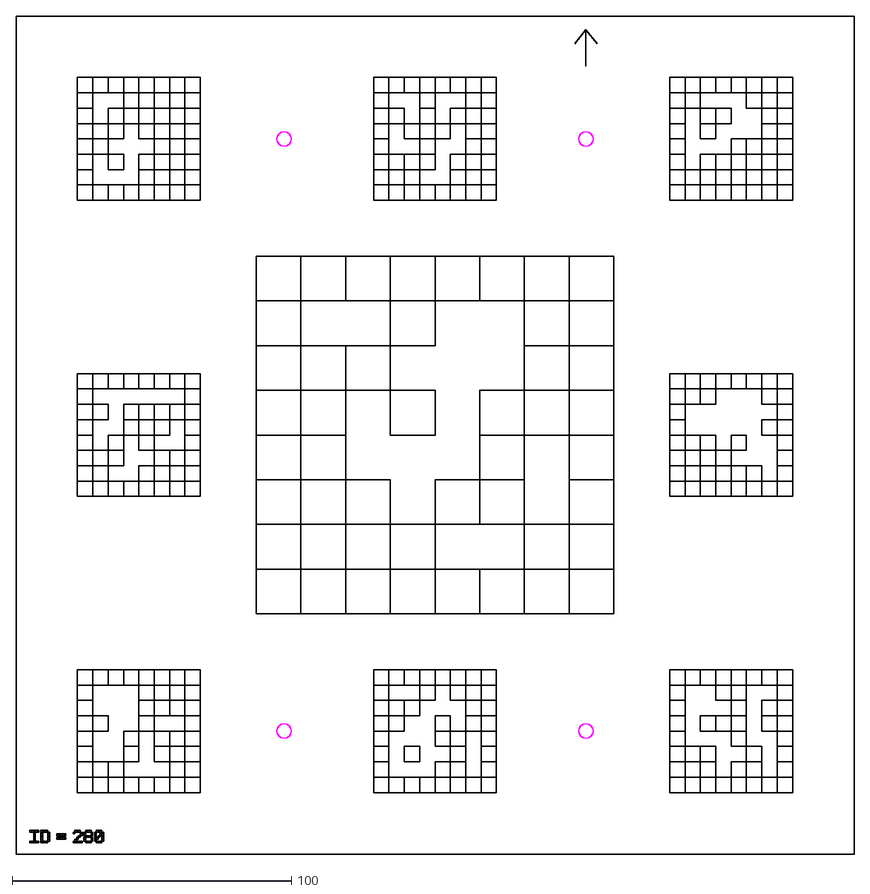
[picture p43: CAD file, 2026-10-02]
Reservoir-AprilTag-Boards-20/batch_02/manufacturing/board_21_ids_280-288.dxf
300.0 x 300.0

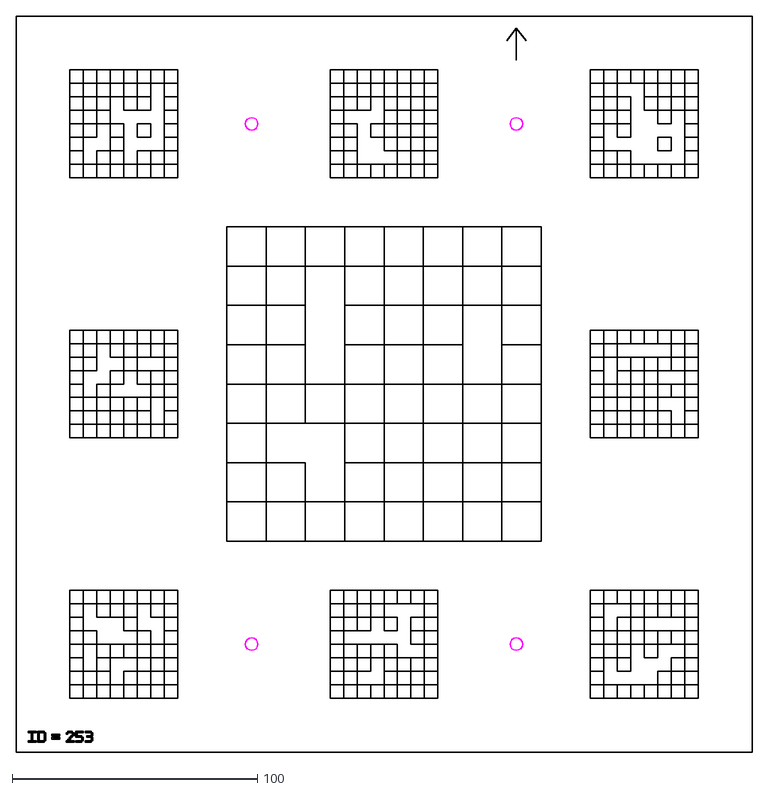
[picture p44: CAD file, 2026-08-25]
Reservoir-AprilTag-Boards-20/generated/board_18_ids_253-261.dxf
300.0 x 300.0

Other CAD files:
Reservoir-AprilTag-Boards-20/generated/boards/board_13_ids_208-216.dxf
generated/face_02_guide.dxf
Reservoir-AprilTag-Boards-20/batch_02/manufacturing/board_26_ids_325-333.dxf
Reservoir-AprilTag-Boards-20/batch_02/generated/all_boards_sheet.dxf
Reservoir-AprilTag-Boards-20/batch_02/generated/all_boards_sheet_guide.dxf
Reservoir-AprilTag-Boards-20/batch_02/generated/board_21_ids_280-288_guide.dxf
Reservoir-AprilTag-Boards-20/batch_02/generated/board_22_ids_289-297.dxf
Reservoir-AprilTag-Boards-20/batch_02/generated/board_22_ids_289-297_guide.dxf
Reservoir-AprilTag-Boards-20/batch_02/generated/board_23_ids_298-306.dxf
Reservoir-AprilTag-Boards-20/batch_02/generated/board_23_ids_298-306_guide.dxf
Reservoir-AprilTag-Boards-20/batch_02/generated/board_24_ids_307-315.dxf
Reservoir-AprilTag-Boards-20/batch_02/generated/board_24_ids_307-315_guide.dxf
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

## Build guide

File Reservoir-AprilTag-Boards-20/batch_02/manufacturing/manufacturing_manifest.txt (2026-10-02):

Reservoir AprilTag board manufacturing manifest

Tag family: AprilTag 36h11
Board count: 20
Board numbers: 21-40
Tags per board: 9 (one center plus eight outer tags)
ID range: 280-459
Board size: 300.0 x 300.0 mm
Center black marker size: 128.0 x 128.0 mm
Outer black marker size: 44.0 x 44.0 mm
Marker modules: 8 x 8
Center module / quiet zone: 16.000 / 10.0 mm
Outer module / quiet zone: 5.500 / 8.0 mm
Outer tag grid centers: 44.0, 150.0, 256.0 mm
Mounting holes: 4 x diameter 5.2 mm
Hole centers from lower-left: (96.0, 44.0), (204.0, 44.0), (96.0, 256.0), (204.0, 256.0)

Print at 100% scale. Do not use fit-to-page.
Keep the entire quiet zone matte white and free of fasteners, stains, text, or seams.
The SVG files contain physical millimeter dimensions; DXF uses millimeters.
The clean SVG is print artwork. The guide SVG is for inspection and drilling reference.

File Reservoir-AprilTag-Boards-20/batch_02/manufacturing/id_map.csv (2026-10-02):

board_no | board_label | tag_family | tag_id | tag_position | center_x_mm | center_y_mm | board_size_mm | black_marker_size_mm | module_size_mm | quiet_zone_mm
21 | R21 | AprilTag 36h11 | 280 | CENTER | 150.0 | 150.0 | 300.0 | 128.0 | 16.000 | 10.0
21 | R21 | AprilTag 36h11 | 281 | TL | 44.0 | 256.0 | 300.0 | 44.0 | 5.500 | 8.0
21 | R21 | AprilTag 36h11 | 282 | T | 150.0 | 256.0 | 300.0 | 44.0 | 5.500 | 8.0
21 | R21 | AprilTag 36h11 | 283 | TR | 256.0 | 256.0 | 300.0 | 44.0 | 5.500 | 8.0
21 | R21 | AprilTag 36h11 | 284 | L | 44.0 | 150.0 | 300.0 | 44.0 | 5.500 | 8.0
21 | R21 | AprilTag 36h11 | 285 | R | 256.0 | 150.0 | 300.0 | 44.0 | 5.500 | 8.0
21 | R21 | AprilTag 36h11 | 286 | BL | 44.0 | 44.0 | 300.0 | 44.0 | 5.500 | 8.0
21 | R21 | AprilTag 36h11 | 287 | B | 150.0 | 44.0 | 300.0 | 44.0 | 5.500 | 8.0
21 | R21 | AprilTag 36h11 | 288 | BR | 256.0 | 44.0 | 300.0 | 44.0 | 5.500 | 8.0
22 | R22 | AprilTag 36h11 | 289 | CENTER | 150.0 | 150.0 | 300.0 | 128.0 | 16.000 | 10.0
22 | R22 | AprilTag 36h11 | 290 | TL | 44.0 | 256.0 | 300.0 | 44.0 | 5.500 | 8.0
22 | R22 | AprilTag 36h11 | 291 | T | 150.0 | 256.0 | 300.0 | 44.0 | 5.500 | 8.0
22 | R22 | AprilTag 36h11 | 292 | TR | 256.0 | 256.0 | 300.0 | 44.0 | 5.500 | 8.0
22 | R22 | AprilTag 36h11 | 293 | L | 44.0 | 150.0 | 300.0 | 44.0 | 5.500 | 8.0
22 | R22 | AprilTag 36h11 | 294 | R | 256.0 | 150.0 | 300.0 | 44.0 | 5.500 | 8.0
22 | R22 | AprilTag 36h11 | 295 | BL | 44.0 | 44.0 | 300.0 | 44.0 | 5.500 | 8.0
22 | R22 | AprilTag 36h11 | 296 | B | 150.0 | 44.0 | 300.0 | 44.0 | 5.500 | 8.0
22 | R22 | AprilTag 36h11 | 297 | BR | 256.0 | 44.0 | 300.0 | 44.0 | 5.500 | 8.0
23 | R23 | AprilTag 36h11 | 298 | CENTER | 150.0 | 150.0 | 300.0 | 128.0 | 16.000 | 10.0
23 | R23 | AprilTag 36h11 | 299 | TL | 44.0 | 256.0 | 300.0 | 44.0 | 5.500 | 8.0
23 | R23 | AprilTag 36h11 | 300 | T | 150.0 | 256.0 | 300.0 | 44.0 | 5.500 | 8.0
23 | R23 | AprilTag 36h11 | 301 | TR | 256.0 | 256.0 | 300.0 | 44.0 | 5.500 | 8.0
23 | R23 | AprilTag 36h11 | 302 | L | 44.0 | 150.0 | 300.0 | 44.0 | 5.500 | 8.0
23 | R23 | AprilTag 36h11 | 303 | R | 256.0 | 150.0 | 300.0 | 44.0 | 5.500 | 8.0
23 | R23 | AprilTag 36h11 | 304 | BL | 44.0 | 44.0 | 300.0 | 44.0 | 5.500 | 8.0
23 | R23 | AprilTag 36h11 | 305 | B | 150.0 | 44.0 | 300.0 | 44.0 | 5.500 | 8.0
23 | R23 | AprilTag 36h11 | 306 | BR | 256.0 | 44.0 | 300.0 | 44.0 | 5.500 | 8.0
24 | R24 | AprilTag 36h11 | 307 | CENTER | 150.0 | 150.0 | 300.0 | 128.0 | 16.000 | 10.0
24 | R24 | AprilTag 36h11 | 308 | TL | 44.0 | 256.0 | 300.0 | 44.0 | 5.500 | 8.0
24 | R24 | AprilTag 36h11 | 309 | T | 150.0 | 256.0 | 300.0 | 44.0 | 5.500 | 8.0
24 | R24 | AprilTag 36h11 | 310 | TR | 256.0 | 256.0 | 300.0 | 44.0 | 5.500 | 8.0
24 | R24 | AprilTag 36h11 | 311 | L | 44.0 | 150.0 | 300.0 | 44.0 | 5.500 | 8.0
24 | R24 | AprilTag 36h11 | 312 | R | 256.0 | 150.0 | 300.0 | 44.0 | 5.500 | 8.0
24 | R24 | AprilTag 36h11 | 313 | BL | 44.0 | 44.0 | 300.0 | 44.0 | 5.500 | 8.0
24 | R24 | AprilTag 36h11 | 314 | B | 150.0 | 44.0 | 300.0 | 44.0 | 5.500 | 8.0
24 | R24 | AprilTag 36h11 | 315 | BR | 256.0 | 44.0 | 300.0 | 44.0 | 5.500 | 8.0
25 | R25 | AprilTag 36h11 | 316 | CENTER | 150.0 | 150.0 | 300.0 | 128.0 | 16.000 | 10.0
25 | R25 | AprilTag 36h11 | 317 | TL | 44.0 | 256.0 | 300.0 | 44.0 | 5.500 | 8.0
25 | R25 | AprilTag 36h11 | 318 | T | 150.0 | 256.0 | 300.0 | 44.0 | 5.500 | 8.0
25 | R25 | AprilTag 36h11 | 319 | TR | 256.0 | 256.0 | 300.0 | 44.0 | 5.500 | 8.0
25 | R25 | AprilTag 36h11 | 320 | L | 44.0 | 150.0 | 300.0 | 44.0 | 5.500 | 8.0
25 | R25 | AprilTag 36h11 | 321 | R | 256.0 | 150.0 | 300.0 | 44.0 | 5.500 | 8.0
25 | R25 | AprilTag 36h11 | 322 | BL | 44.0 | 44.0 | 300.0 | 44.0 | 5.500 | 8.0
25 | R25 | AprilTag 36h11 | 323 | B | 150.0 | 44.0 | 300.0 | 44.0 | 5.500 | 8.0
25 | R25 | AprilTag 36h11 | 324 | BR | 256.0 | 44.0 | 300.0 | 44.0 | 5.500 | 8.0
26 | R26 | AprilTag 36h11 | 325 | CENTER | 150.0 | 150.0 | 300.0 | 128.0 | 16.000 | 10.0
26 | R26 | AprilTag 36h11 | 326 | TL | 44.0 | 256.0 | 300.0 | 44.0 | 5.500 | 8.0
26 | R26 | AprilTag 36h11 | 327 | T | 150.0 | 256.0 | 300.0 | 44.0 | 5.500 | 8.0
26 | R26 | AprilTag 36h11 | 328 | TR | 256.0 | 256.0 | 300.0 | 44.0 | 5.500 | 8.0
26 | R26 | AprilTag 36h11 | 329 | L | 44.0 | 150.0 | 300.0 | 44.0 | 5.500 | 8.0
26 | R26 | AprilTag 36h11 | 330 | R | 256.0 | 150.0 | 300.0 | 44.0 | 5.500 | 8.0
26 | R26 | AprilTag 36h11 | 331 | BL | 44.0 | 44.0 | 300.0 | 44.0 | 5.500 | 8.0
26 | R26 | AprilTag 36h11 | 332 | B | 150.0 | 44.0 | 300.0 | 44.0 | 5.500 | 8.0
26 | R26 | AprilTag 36h11 | 333 | BR | 256.0 | 44.0 | 300.0 | 44.0 | 5.500 | 8.0
27 | R27 | AprilTag 36h11 | 334 | CENTER | 150.0 | 150.0 | 300.0 | 128.0 | 16.000 | 10.0
27 | R27 | AprilTag 36h11 | 335 | TL | 44.0 | 256.0 | 300.0 | 44.0 | 5.500 | 8.0
27 | R27 | AprilTag 36h11 | 336 | T | 150.0 | 256.0 | 300.0 | 44.0 | 5.500 | 8.0
27 | R27 | AprilTag 36h11 | 337 | TR | 256.0 | 256.0 | 300.0 | 44.0 | 5.500 | 8.0
27 | R27 | AprilTag 36h11 | 338 | L | 44.0 | 150.0 | 300.0 | 44.0 | 5.500 | 8.0
27 | R27 | AprilTag 36h11 | 339 | R | 256.0 | 150.0 | 300.0 | 44.0 | 5.500 | 8.0
27 | R27 | AprilTag 36h11 | 340 | BL | 44.0 | 44.0 | 300.0 | 44.0 | 5.500 | 8.0
27 | R27 | AprilTag 36h11 | 341 | B | 150.0 | 44.0 | 300.0 | 44.0 | 5.500 | 8.0
27 | R27 | AprilTag 36h11 | 342 | BR | 256.0 | 44.0 | 300.0 | 44.0 | 5.500 | 8.0
28 | R28 | AprilTag 36h11 | 343 | CENTER | 150.0 | 150.0 | 300.0 | 128.0 | 16.000 | 10.0
28 | R28 | AprilTag 36h11 | 344 | TL | 44.0 | 256.0 | 300.0 | 44.0 | 5.500 | 8.0
28 | R28 | AprilTag 36h11 | 345 | T | 150.0 | 256.0 | 300.0 | 44.0 | 5.500 | 8.0
28 | R28 | AprilTag 36h11 | 346 | TR | 256.0 | 256.0 | 300.0 | 44.0 | 5.500 | 8.0
28 | R28 | AprilTag 36h11 | 347 | L | 44.0 | 150.0 | 300.0 | 44.0 | 5.500 | 8.0
28 | R28 | AprilTag 36h11 | 348 | R | 256.0 | 150.0 | 300.0 | 44.0 | 5.500 | 8.0
28 | R28 | AprilTag 36h11 | 349 | BL | 44.0 | 44.0 | 300.0 | 44.0 | 5.500 | 8.0
28 | R28 | AprilTag 36h11 | 350 | B | 150.0 | 44.0 | 300.0 | 44.0 | 5.500 | 8.0
28 | R28 | AprilTag 36h11 | 351 | BR | 256.0 | 44.0 | 300.0 | 44.0 | 5.500 | 8.0
29 | R29 | AprilTag 36h11 | 352 | CENTER | 150.0 | 150.0 | 300.0 | 128.0 | 16.000 | 10.0
29 | R29 | AprilTag 36h11 | 353 | TL | 44.0 | 256.0 | 300.0 | 44.0 | 5.500 | 8.0
29 | R29 | AprilTag 36h11 | 354 | T | 150.0 | 256.0 | 300.0 | 44.0 | 5.500 | 8.0
29 | R29 | AprilTag 36h11 | 355 | TR | 256.0 | 256.0 | 300.0 | 44.0 | 5.500 | 8.0
29 | R29 | AprilTag 36h11 | 356 | L | 44.0 | 150.0 | 300.0 | 44.0 | 5.500 | 8.0
29 | R29 | AprilTag 36h11 | 357 | R | 256.0 | 150.0 | 300.0 | 44.0 | 5.500 | 8.0
29 | R29 | AprilTag 36h11 | 358 | BL | 44.0 | 44.0 | 300.0 | 44.0 | 5.500 | 8.0
29 | R29 | AprilTag 36h11 | 359 | B | 150.0 | 44.0 | 300.0 | 44.0 | 5.500 | 8.0
29 | R29 | AprilTag 36h11 | 360 | BR | 256.0 | 44.0 | 300.0 | 44.0 | 5.500 | 8.0
30 | R30 | AprilTag 36h11 | 361 | CENTER | 150.0 | 150.0 | 300.0 | 128.0 | 16.000 | 10.0
30 | R30 | AprilTag 36h11 | 362 | TL | 44.0 | 256.0 | 300.0 | 44.0 | 5.500 | 8.0
30 | R30 | AprilTag 36h11 | 363 | T | 150.0 | 256.0 | 300.0 | 44.0 | 5.500 | 8.0
30 | R30 | AprilTag 36h11 | 364 | TR | 256.0 | 256.0 | 300.0 | 44.0 | 5.500 | 8.0
30 | R30 | AprilTag 36h11 | 365 | L | 44.0 | 150.0 | 300.0 | 44.0 | 5.500 | 8.0
30 | R30 | AprilTag 36h11 | 366 | R | 256.0 | 150.0 | 300.0 | 44.0 | 5.500 | 8.0
30 | R30 | AprilTag 36h11 | 367 | BL | 44.0 | 44.0 | 300.0 | 44.0 | 5.500 | 8.0
30 | R30 | AprilTag 36h11 | 368 | B | 150.0 | 44.0 | 300.0 | 44.0 | 5.500 | 8.0
30 | R30 | AprilTag 36h11 | 369 | BR | 256.0 | 44.0 | 300.0 | 44.0 | 5.500 | 8.0
31 | R31 | AprilTag 36h11 | 370 | CENTER | 150.0 | 150.0 | 300.0 | 128.0 | 16.000 | 10.0
31 | R31 | AprilTag 36h11 | 371 | TL | 44.0 | 256.0 | 300.0 | 44.0 | 5.500 | 8.0
31 | R31 | AprilTag 36h11 | 372 | T | 150.0 | 256.0 | 300.0 | 44.0 | 5.500 | 8.0
31 | R31 | AprilTag 36h11 | 373 | TR | 256.0 | 256.0 | 300.0 | 44.0 | 5.500 | 8.0
31 | R31 | AprilTag 36h11 | 374 | L | 44.0 | 150.0 | 300.0 | 44.0 | 5.500 | 8.0
31 | R31 | AprilTag 36h11 | 375 | R | 256.0 | 150.0 | 300.0 | 44.0 | 5.500 | 8.0
31 | R31 | AprilTag 36h11 | 376 | BL | 44.0 | 44.0 | 300.0 | 44.0 | 5.500 | 8.0
31 | R31 | AprilTag 36h11 | 377 | B | 150.0 | 44.0 | 300.0 | 44.0 | 5.500 | 8.0
31 | R31 | AprilTag 36h11 | 378 | BR | 256.0 | 44.0 | 300.0 | 44.0 | 5.500 | 8.0
32 | R32 | AprilTag 36h11 | 379 | CENTER | 150.0 | 150.0 | 300.0 | 128.0 | 16.000 | 10.0
32 | R32 | AprilTag 36h11 | 380 | TL | 44.0 | 256.0 | 300.0 | 44.0 | 5.500 | 8.0
32 | R32 | AprilTag 36h11 | 381 | T | 150.0 | 256.0 | 300.0 | 44.0 | 5.500 | 8.0
32 | R32 | AprilTag 36h11 | 382 | TR | 256.0 | 256.0 | 300.0 | 44.0 | 5.500 | 8.0
32 | R32 | AprilTag 36h11 | 383 | L | 44.0 | 150.0 | 300.0 | 44.0 | 5.500 | 8.0
32 | R32 | AprilTag 36h11 | 384 | R | 256.0 | 150.0 | 300.0 | 44.0 | 5.500 | 8.0
32 | R32 | AprilTag 36h11 | 385 | BL | 44.0 | 44.0 | 300.0 | 44.0 | 5.500 | 8.0
32 | R32 | AprilTag 36h11 | 386 | B | 150.0 | 44.0 | 300.0 | 44.0 | 5.500 | 8.0
32 | R32 | AprilTag 36h11 | 387 | BR | 256.0 | 44.0 | 300.0 | 44.0 | 5.500 | 8.0
33 | R33 | AprilTag 36h11 | 388 | CENTER | 150.0 | 150.0 | 300.0 | 128.0 | 16.000 | 10.0
33 | R33 | AprilTag 36h11 | 389 | TL | 44.0 | 256.0 | 300.0 | 44.0 | 5.500 | 8.0
33 | R33 | AprilTag 36h11 | 390 | T | 150.0 | 256.0 | 300.0 | 44.0 | 5.500 | 8.0
33 | R33 | AprilTag 36h11 | 391 | TR | 256.0 | 256.0 | 300.0 | 44.0 | 5.500 | 8.0
33 | R33 | AprilTag 36h11 | 392 | L | 44.0 | 150.0 | 300.0 | 44.0 | 5.500 | 8.0
33 | R33 | AprilTag 36h11 | 393 | R | 256.0 | 150.0 | 300.0 | 44.0 | 5.500 | 8.0
33 | R33 | AprilTag 36h11 | 394 | BL | 44.0 | 44.0 | 300.0 | 44.0 | 5.500 | 8.0
33 | R33 | AprilTag 36h11 | 395 | B | 150.0 | 44.0 | 300.0 | 44.0 | 5.500 | 8.0
33 | R33 | AprilTag 36h11 | 396 | BR | 256.0 | 44.0 | 300.0 | 44.0 | 5.500 | 8.0
34 | R34 | AprilTag 36h11 | 397 | CENTER | 150.0 | 150.0 | 300.0 | 128.0 | 16.000 | 10.0
34 | R34 | AprilTag 36h11 | 398 | TL | 44.0 | 256.0 | 300.0 | 44.0 | 5.500 | 8.0
34 | R34 | AprilTag 36h11 | 399 | T | 150.0 | 256.0 | 300.0 | 44.0 | 5.500 | 8.0
34 | R34 | AprilTag 36h11 | 400 | TR | 256.0 | 256.0 | 300.0 | 44.0 | 5.500 | 8.0
34 | R34 | AprilTag 36h11 | 401 | L | 44.0 | 150.0 | 300.0 | 44.0 | 5.500 | 8.0
34 | R34 | AprilTag 36h11 | 402 | R | 256.0 | 150.0 | 300.0 | 44.0 | 5.500 | 8.0
34 | R34 | AprilTag 36h11 | 403 | BL | 44.0 | 44.0 | 300.0 | 44.0 | 5.500 | 8.0
34 | R34 | AprilTag 36h11 | 404 | B | 150.0 | 44.0 | 300.0 | 44.0 | 5.500 | 8.0
34 | R34 | AprilTag 36h11 | 405 | BR | 256.0 | 44.0 | 300.0 | 44.0 | 5.500 | 8.0
35 | R35 | AprilTag 36h11 | 406 | CENTER | 150.0 | 150.0 | 300.0 | 128.0 | 16.000 | 10.0
35 | R35 | AprilTag 36h11 | 407 | TL | 44.0 | 256.0 | 300.0 | 44.0 | 5.500 | 8.0
35 | R35 | AprilTag 36h11 | 408 | T | 150.0 | 256.0 | 300.0 | 44.0 | 5.500 | 8.0
35 | R35 | AprilTag 36h11 | 409 | TR | 256.0 | 256.0 | 300.0 | 44.0 | 5.500 | 8.0
35 | R35 | AprilTag 36h11 | 410 | L | 44.0 | 150.0 | 300.0 | 44.0 | 5.500 | 8.0
35 | R35 | AprilTag 36h11 | 411 | R | 256.0 | 150.0 | 300.0 | 44.0 | 5.500 | 8.0
35 | R35 | AprilTag 36h11 | 412 | BL | 44.0 | 44.0 | 300.0 | 44.0 | 5.500 | 8.0
35 | R35 | AprilTag 36h11 | 413 | B | 150.0 | 44.0 | 300.0 | 44.0 | 5.500 | 8.0
35 | R35 | AprilTag 36h11 | 414 | BR | 256.0 | 44.0 | 300.0 | 44.0 | 5.500 | 8.0
36 | R36 | AprilTag 36h11 | 415 | CENTER | 150.0 | 150.0 | 300.0 | 128.0 | 16.000 | 10.0
36 | R36 | AprilTag 36h11 | 416 | TL | 44.0 | 256.0 | 300.0 | 44.0 | 5.500 | 8.0
36 | R36 | AprilTag 36h11 | 417 | T | 150.0 | 256.0 | 300.0 | 44.0 | 5.500 | 8.0
36 | R36 | AprilTag 36h11 | 418 | TR | 256.0 | 256.0 | 300.0 | 44.0 | 5.500 | 8.0
36 | R36 | AprilTag 36h11 | 419 | L | 44.0 | 150.0 | 300.0 | 44.0 | 5.500 | 8.0
36 | R36 | AprilTag 36h11 | 420 | R | 256.0 | 150.0 | 300.0 | 44.0 | 5.500 | 8.0
36 | R36 | AprilTag 36h11 | 421 | BL | 44.0 | 44.0 | 300.0 | 44.0 | 5.500 | 8.0
36 | R36 | AprilTag 36h11 | 422 | B | 150.0 | 44.0 | 300.0 | 44.0 | 5.500 | 8.0
36 | R36 | AprilTag 36h11 | 423 | BR | 256.0 | 44.0 | 300.0 | 44.0 | 5.500 | 8.0
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

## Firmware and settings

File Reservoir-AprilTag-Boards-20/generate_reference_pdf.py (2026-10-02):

from __future__ import annotations

import argparse
from pathlib import Path

import cv2
from reportlab.lib import colors
from reportlab.lib.pagesizes import A4, landscape
from reportlab.lib.units import mm
from reportlab.pdfgen import canvas

from generate_reservoir_boards import (
    Config,
    TagSpec,
    marker_grid,
    tag_specs_for_board,
    validate_config,
)


PAGE_SIZE = landscape(A4)
BLUE = colors.HexColor("#2B6CB0")
MAGENTA = colors.HexColor("#D53F8C")
GRAY = colors.HexColor("#718096")
DARK = colors.HexColor("#1A202C")
LIGHT = colors.HexColor("#EDF2F7")


def draw_tag(
    pdf: canvas.Canvas,
    dictionary: cv2.aruco.Dictionary,
    tag: TagSpec,
    origin_x: float,
    origin_y: float,
    scale: float,
) -> None:
    def px(value_mm: float) -> float:
        return origin_x + value_mm * scale

    def py(value_mm: float) -> float:
        return origin_y + value_mm * scale

    quiet_x = tag.x0 - tag.quiet_mm
    quiet_y = tag.y0 - tag.quiet_mm
    quiet_size = tag.size_mm + 2.0 * tag.quiet_mm
    pdf.saveState()
    pdf.setStrokeColor(BLUE)
    pdf.setLineWidth(0.35)
    pdf.setDash(3, 2)
    pdf.rect(px(quiet_x), py(quiet_y), quiet_size * scale, quiet_size * scale, stroke=1, fill=0)
    pdf.setDash()
    pdf.setStrokeColor(GRAY)
    pdf.setLineWidth(0.25)
    pdf.rect(px(tag.x0), py(tag.y0), tag.size_mm * scale, tag.size_mm * scale, stroke=1, fill=0)
    pdf.restoreState()

    grid = marker_grid(dictionary, tag.tag_id)
    cell = tag.module_mm
    pdf.saveState()
    pdf.setFillColor(colors.black)
    for row in range(8):
        for col in range(8):
            if not bool(grid[row, col]):
                continue
            x = tag.x0 + col * cell
            y = tag.y0 + tag.size_mm - (row + 1) * cell
            pdf.rect(px(x), py(y), cell * scale, cell * scale, stroke=0, fill=1)
    pdf.restoreState()

    label_y = tag.y0 + tag.size_mm + 2.0
    pdf.saveState()
    pdf.setFillColor(BLUE)
    pdf.setFont("Helvetica", 5.5)
    pdf.drawString(px(tag.x0), py(label_y), f"{tag.name} ID {tag.tag_id}")
    pdf.restoreState()


def draw_board_diagram(
    pdf: canvas.Canvas,
    dictionary: cv2.aruco.Dictionary,
    board_index: int,
    cfg: Config,
    origin_x: float,
    origin_y: float,
    diagram_size: float,
) -> None:
    scale = diagram_size / cfg.board_mm
    tags = tag_specs_for_board(board_index, cfg)

    pdf.saveState()
    pdf.setFillColor(colors.white)
    pdf.setStrokeColor(DARK)
    pdf.setLineWidth(0.65)
    pdf.rect(origin_x, origin_y, diagram_size, diagram_size, stroke=1, fill=1)
    pdf.restoreState()

    for tag in tags:
        draw_tag(pdf, dictionary, tag, origin_x, origin_y, scale)

    pdf.saveState()
    pdf.setStrokeColor(MAGENTA)
    pdf.setLineWidth(0.6)
    for hx, hy in cfg.holes_mm:
        cx = origin_x + hx * scale
        cy = origin_y + hy * scale
        radius = cfg.hole_dia_mm / 2.0 * scale
        cross = 4.0 * scale
        pdf.circle(cx, cy, radius, stroke=1, fill=0)
        pdf.setLineWidth(0.25)
        pdf.line(cx - cross, cy, cx + cross, cy)
        pdf.line(cx, cy - cross, cx, cy + cross)
        pdf.setLineWidth(0.6)
    pdf.restoreState()

    # Production orientation arrow.
    arrow_x = origin_x + 204.0 * scale
    arrow_y1 = origin_y + (cfg.board_mm - 18.0) * scale
    arrow_y2 = origin_y + (cfg.board_mm - 5.0) * scale
    pdf.saveState()
    pdf.setStrokeColor(DARK)
    pdf.setLineWidth(1.1)
    pdf.line(arrow_x, arrow_y1, arrow_x, arrow_y2)
    pdf.line(arrow_x, arrow_y2, arrow_x - 4.0 * scale, arrow_y2 - 5.0 * scale)
    pdf.line(arrow_x, arrow_y2, arrow_x + 4.0 * scale, arrow_y2 - 5.0 * scale)
    pdf.restoreState()

    pdf.saveState()
    pdf.setFillColor(DARK)
    pdf.setFont("Helvetica-Bold", 6.5)
    pdf.drawString(origin_x + 5.0 * scale, origin_y + 4.0 * scale, f"ID = {tags[0].tag_id}")
    pdf.restoreState()


def draw_detail_panel(
    pdf: canvas.Canvas,
    board_index: int,
    cfg: Config,
    panel_x: float,
    panel_y: float,
    panel_w: float,
) -> None:
    tags = tag_specs_for_board(board_index, cfg)
    first_id, last_id = tags[0].tag_id, tags[-1].tag_id
    board_number = cfg.board_number_start + board_index

    pdf.saveState()
    pdf.setFillColor(DARK)
    pdf.setFont("Helvetica-Bold", 15)
    pdf.drawString(panel_x, panel_y, f"BOARD {board_number:02d}")
    pdf.setFont("Helvetica", 9)
    pdf.setFillColor(GRAY)
    pdf.drawString(panel_x, panel_y - 7 * mm, f"Center ID {first_id} | IDs {first_id}-{last_id}")

    y = panel_y - 17 * mm
    rows = [
        ("Board", f"{cfg.board_mm:.0f} x {cfg.board_mm:.0f} mm"),
        ("Center marker", f"{cfg.center_tag_mm:.0f} mm"),
        ("Outer markers", f"8 x {cfg.small_tag_mm:.0f} mm"),
        ("Mount holes", f"4 x DIA {cfg.hole_dia_mm:.1f} mm"),
        ("Hole X", f"{cfg.hole_x_mm:.0f}, {cfg.board_mm - cfg.hole_x_mm:.0f} mm"),
        ("Hole Y", f"{cfg.hole_y_mm:.0f}, {cfg.board_mm - cfg.hole_y_mm:.0f} mm"),
    ]
    row_h = 8 * mm
    pdf.setLineWidth(0.35)
    for index, (key, value) in enumerate(rows):
        top = y - index * row_h
        pdf.setFillColor(LIGHT if index % 2 == 0 else colors.white)
        pdf.rect(panel_x, top - row_h + 1.2 * mm, panel_w, row_h, stroke=0, fill=1)
        pdf.setFillColor(GRAY)
        pdf.setFont("Helvetica", 7.5)
        pdf.drawString(panel_x + 2.5 * mm, top - 4.1 * mm, key)
        pdf.setFillColor(DARK)
        pdf.setFont("Helvetica-Bold", 7.5)
        pdf.drawRightString(panel_x + panel_w - 2.5 * mm, top - 4.1 * mm, value)

    grid_top = y - len(rows) * row_h - 7 * mm
    pdf.setFillColor(DARK)
    pdf.setFont("Helvetica-Bold", 9)
    pdf.drawString(panel_x, grid_top, "ID LAYOUT")
    cell_w = panel_w / 3.0
    cell_h = 12 * mm
    layout = [
        [tags[1], tags[2], tags[3]],
        [tags[4], tags[0], tags[5]],
        [tags[6], tags[7], tags[8]],
    ]
    grid_y = grid_top - 5 * mm
    for row_index, row in enumerate(layout):
        for col_index, tag in enumerate(row):
            x = panel_x + col_index * cell_w
            cell_y = grid_y - (row_index + 1) * cell_h
            pdf.setFillColor(LIGHT if tag.name != "CENTER" else colors.HexColor("#E6FFFA"))
            pdf.setStrokeColor(colors.HexColor("#CBD5E0"))
            pdf.rect(x, cell_y, cell_w, cell_h, stroke=1, fill=1)
            pdf.setFillColor(GRAY)
            pdf.setFont("Helvetica", 6.5)
            pdf.drawCentredString(x + cell_w / 2.0, cell_y + 7.0 * mm, tag.name)
            pdf.setFillColor(DARK)
            pdf.setFont("Helvetica-Bold", 9)
            pdf.drawCentredString(x + cell_w / 2.0, cell_y + 2.7 * mm, str(tag.tag_id))

    note_y = grid_y - 3 * cell_h - 10 * mm
    pdf.setFillColor(GRAY)
    pdf.setFont("Helvetica", 6.5)
    notes = [
        "Blue dashed: required white quiet zone",
        "Magenta: mounting holes and centers",
        "Reference diagram is scaled, not 1:1",
        "Manufacture from DXF/SVG; DXF units are mm",
    ]
    for index, note in enumerate(notes):
        pdf.drawString(panel_x, note_y - index * 4.2 * mm, note)

    dxf_name = f"board_{board_number:02d}_ids_{first_id:03d}-{last_id:03d}.dxf"
    pdf.setFillColor(DARK)
    pdf.setFont("Helvetica-Bold", 6.5)
    pdf.drawString(panel_x, 12 * mm, dxf_name)
    pdf.restoreState()


def generate_pdf(path: Path, cfg: Config) -> None:
    dictionary = cv2.aruco.getPredefinedDictionary(cv2.aruco.DICT_APRILTAG_36h11)
    validate_config(cfg, dictionary)
    path.parent.mkdir(parents=True, exist_ok=True)
    pdf = canvas.Canvas(str(path), pagesize=PAGE_SIZE, pageCompression=1)
    board_number_end = cfg.board_number_start + cfg.board_count - 1
    pdf.setTitle(
        f"Reservoir AprilTag Boards {cfg.board_number_start}-{board_number_end} DXF Reference"
    )
    pdf.setAuthor("Ocean Hub")
    page_w, page_h = PAGE_SIZE

    diagram_size = 175 * mm
    origin_x = 10 * mm
    origin_y = 17 * mm
    panel_x = 193 * mm
    panel_w = 94 * mm
    panel_y = page_h - 15 * mm

    for board_index in range(cfg.board_count):
        tags = tag_specs_for_board(board_index, cfg)
        pdf.setFillColor(DARK)
        pdf.setFont("Helvetica-Bold", 10)
        pdf.drawString(10 * mm, page_h - 10 * mm, "RESERVOIR APRILTAG BOARD - DXF REFERENCE")
        pdf.setFillColor(GRAY)
        pdf.setFont("Helvetica", 7)
        pdf.drawRightString(
            page_w - 10 * mm,
            page_h - 10 * mm,
            f"Page {board_index + 1} / {cfg.board_count} | Center ID {tags[0].tag_id}",
        )
        draw_board_diagram(pdf, dictionary, board_index, cfg, origin_x, origin_y, diagram_size)
        draw_detail_panel(pdf, board_index, cfg, panel_x, panel_y, panel_w)
        pdf.showPage()

    pdf.save()


def parse_args() -> argparse.Namespace:
    parser = argparse.ArgumentParser(description="Generate a PDF reference for a reservoir board set.")
    parser.add_argument(
        "--out",
        type=Path,
        default=Path("output") / "pdf" / "reservoir_apriltag_20_board_reference.pdf",
    )
    parser.add_argument("--board-count", type=int, default=20)
    parser.add_argument("--board-number-start", type=int, default=1)
    parser.add_argument("--start-id", type=int, default=100)
    return parser.parse_args()


def main() -> None:
    args = parse_args()
    cfg = Config(
        board_count=args.board_count,
        board_number_start=args.board_number_start,
        start_id=args.start_id,
    )
    generate_pdf(args.out, cfg)
    print(f"Wrote PDF reference: {args.out.resolve()}")


if __name__ == "__main__":
    main()

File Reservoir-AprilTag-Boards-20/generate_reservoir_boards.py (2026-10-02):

from __future__ import annotations

import argparse
import csv
import math
from dataclasses import dataclass
from pathlib import Path
from typing import Iterable, Sequence
from xml.sax.saxutils import escape

import cv2
import numpy as np


MODULES_WITH_BORDER = 8

# Minimal 5x7 stroke font used for production labels.  Fusion 360 commonly
# drops DXF TEXT entities when inserting a DXF into a sketch, so these glyphs
# are emitted as ordinary LINE rectangles on the BOARD_TEXT layer.
VECTOR_GLYPHS = {
    "C": ["01111", "10000", "10000", "10000", "10000", "10000", "01111"],
    "D": ["11110", "10001", "10001", "10001", "10001", "10001", "11110"],
    "E": ["11111", "10000", "10000", "11110", "10000", "10000", "11111"],
    "I": ["11111", "00100", "00100", "00100", "00100", "00100", "11111"],
    "N": ["10001", "11001", "10101", "10011", "10001", "10001", "10001"],
    "R": ["11110", "10001", "10001", "11110", "10100", "10010", "10001"],
    "T": ["11111", "00100", "00100", "00100", "00100", "00100", "00100"],
    "0": ["01110", "10001", "10011", "10101", "11001", "10001", "01110"],
    "1": ["00100", "01100", "00100", "00100", "00100", "00100", "01110"],
    "2": ["01110", "10001", "00001", "00010", "00100", "01000", "11111"],
    "3": ["11110", "00001", "00001", "01110", "00001", "00001", "11110"],
    "4": ["00010", "00110", "01010", "10010", "11111", "00010", "00010"],
    "5": ["11111", "10000", "10000", "11110", "00001", "00001", "11110"],
    "6": ["01110", "10000", "10000", "11110", "10001", "10001", "01110"],
    "7": ["11111", "00001", "00010", "00100", "01000", "01000", "01000"],
    "8": ["01110", "10001", "10001", "01110", "10001", "10001", "01110"],
    "9": ["01110", "10001", "10001", "01111", "00001", "00001", "01110"],
    "=": ["00000", "00000", "11111", "00000", "11111", "00000", "00000"],
}


@dataclass(frozen=True)
class Config:
    board_count: int = 20
    board_number_start: int = 1
    board_mm: float = 300.0
    tags_per_board: int = 9
    center_tag_mm: float = 128.0
    small_tag_mm: float = 44.0
    center_quiet_mm: float = 10.0
    small_quiet_mm: float = 8.0
    small_center_mm: float = 44.0
    start_id: int = 100
    hole_dia_mm: float = 5.2
    hole_x_mm: float = 96.0
    hole_y_mm: float = 44.0
    sheet_columns: int = 4
    sheet_gap_mm: float = 20.0
    dxf_preview_fills: bool = False

    @property
    def center_module_mm(self) -> float:
        return self.center_tag_mm / MODULES_WITH_BORDER

    @property
    def small_module_mm(self) -> float:
        return self.small_tag_mm / MODULES_WITH_BORDER

    @property
    def holes_mm(self) -> tuple[tuple[float, float], ...]:
        high_x = self.board_mm - self.hole_x_mm
        high_y = self.board_mm - self.hole_y_mm
        return (
            (self.hole_x_mm, self.hole_y_mm),
            (high_x, self.hole_y_mm),
            (self.hole_x_mm, high_y),
            (high_x, high_y),
        )


@dataclass(frozen=True)
class TagSpec:
    board_index: int
    tag_id: int
    name: str
    cx: float
    cy: float
    size_mm: float
    quiet_mm: float

    @property
    def x0(self) -> float:
        return self.cx - self.size_mm / 2.0

    @property
    def y0(self) -> float:
        return self.cy - self.size_mm / 2.0

    @property
    def module_mm(self) -> float:
        return self.size_mm / MODULES_WITH_BORDER


class DxfWriter:
    """Small AutoCAD R12 ASCII writer with only widely supported entities."""

    LAYERS = (
        ("CUT", 7),
        ("MOUNT_HOLE", 6),
        ("BLACK_POCKET", 7),
        ("BOARD_TEXT", 7),
        ("ORIENTATION", 7),
        ("BLACK_FILL_PREVIEW", 8),
        ("TAG_BOUNDARY", 8),
        ("QUIET_ZONE", 5),
        ("LABEL", 3),
    )

    def __init__(self) -> None:
        self.lines: list[str] = []

    def pair(self, code: int, value: int | float | str) -> None:
        self.lines.append(str(code))
        if isinstance(value, float):
            self.lines.append(f"{value:.6f}".rstrip("0").rstrip("."))
        else:
            self.lines.append(str(value))

    def start(self) -> None:
        self.pair(0, "SECTION")
        self.pair(2, "HEADER")
        self.pair(9, "$ACADVER")
        self.pair(1, "AC1009")
        self.pair(0, "ENDSEC")
        self.pair(0, "SECTION")
        self.pair(2, "TABLES")
        self.pair(0, "TABLE")
        self.pair(2, "LAYER")
        self.pair(70, len(self.LAYERS))
        for name, color in self.LAYERS:
            self.pair(0, "LAYER")
            self.pair(2, name)
            self.pair(70, 0)
            self.pair(62, color)
            self.pair(6, "CONTINUOUS")
        self.pair(0, "ENDTAB")
        self.pair(0, "ENDSEC")
        self.pair(0, "SECTION")
        self.pair(2, "ENTITIES")

    def line(self, x1: float, y1: float, x2: float, y2: float, layer: str) -> None:
        self.pair(0, "LINE")
        self.pair(8, layer)
        self.pair(10, x1)
        self.pair(20, y1)
        self.pair(11, x2)
        self.pair(21, y2)

    def rect(self, x: float, y: float, w: float, h: float, layer: str) -> None:
        self.line(x, y, x + w, y, layer)
        self.line(x + w, y, x + w, y + h, layer)
        self.line(x + w, y + h, x, y + h, layer)
        self.line(x, y + h, x, y, layer)

    def circle(self, cx: float, cy: float, radius: float, layer: str) -> None:
        self.pair(0, "CIRCLE")
        self.pair(8, layer)
        self.pair(10, cx)
        self.pair(20, cy)
        self.pair(40, radius)

    def solid_rect(self, x: float, y: float, w: float, h: float, layer: str) -> None:
        self.pair(0, "SOLID")
        self.pair(8, layer)
        for code_x, code_y, px, py in (
            (10, 20, x, y),
            (11, 21, x + w, y),
            (12, 22, x, y + h),
            (13, 23, x + w, y + h),
        ):
            self.pair(code_x, px)
            self.pair(code_y, py)

    def text(self, x: float, y: float, value: str, height: float, layer: str, align_center: bool = False) -> None:
        self.pair(0, "TEXT")
        self.pair(8, layer)
        self.pair(10, x)
        self.pair(20, y)
        self.pair(40, height)
        self.pair(1, value)
        if align_center:
            self.pair(72, 1)
            self.pair(11, x)
            self.pair(21, y)

    def finish(self) -> str:
        self.pair(0, "ENDSEC")
        self.pair(0, "EOF")
        return "\n".join(self.lines) + "\n"
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

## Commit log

2026-08-11 Add six-face AprilTag calibration board toolkit
    [all_faces_sheet.dxf, all_faces_sheet_guide.dxf, face_01.dxf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]
2026-08-25 Add reservoir AprilTag board project
    [all_boards_sheet.dxf, all_boards_sheet_guide.dxf, board_01_ids_100-108.dxf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]
2026-10-02 Add second reservoir AprilTag board batch and configurable numbering
    Support board-number offsets in board and reference PDF generators. Add R21-R40 manufacturing files with AprilTag IDs 280-459 and update batch documentation.
    [all_boards_sheet.dxf, all_boards_sheet_guide.dxf, board_21_ids_280-288.dxf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]
